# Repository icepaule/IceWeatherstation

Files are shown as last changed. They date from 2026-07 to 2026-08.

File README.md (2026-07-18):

# IceWeatherstation

DIY-Wetterstation auf Basis **ESP32 + Tasmota**: Temperatur, Luftfeuchte, Luftdruck, eine wasserdichte Zusatz-Temperatursonde, Wind (Geschwindigkeit + Richtung), Regenmenge, **Blitzerkennung** (AS3935/Franklin-Sensor) und ein **kalibrierter dBA-Schallpegelmesser**.

## Warum dieses Projekt?

Basiert auf dem Konzept des [ampheo.com Blog-Artikels "How to build a smart weather station with sensors"](https://www.ampheo.com/blog/how-to-build-a-smart-weather-station-with-sensors), erweitert um:

- **Franklin-Blitzsensor** (AS3935) für Blitzerkennung inkl. grober Entfernungsschätzung
- **Kalibriertes dBA-Schallpegelmodul** (DFRobot Gravity SEN0232, 30–130 dBA, A-bewertet) statt eines unkalibrierten Mikrofons, mit wetterfestem Mikrofongehäuse nach dem bewährten [DNMS-Design](https://sensor.community/en/sensors/dnms/) des sensor.community-Citizen-Science-Projekts
- **Zwingend externe WLAN-Antenne** — ESP32-WROOM-32U/32UE-Modulvariante statt der üblichen PCB-Antenne
- **100% Tasmota-Firmware** statt Arduino/PlatformIO, inklusive eigenständigem Web-UI, das komplett ohne Home Assistant/MQTT funktioniert (für Geräte ohne Smart-Home-Infrastruktur beim Empfänger)

Ursprünglich war angedacht, günstige Fertigsensorik (MISOL "Spare Part Outdoor Unit") zu verwenden — siehe [docs/misol-compatibility.md](docs/misol-compatibility.md), warum das **nicht** ohne Weiteres plug-and-play funktioniert und welche zwei Wege es trotzdem gäbe.

## Status

✅ **Erstes Gerät aufgebaut, geflasht und am Schuppen im Betrieb (Stand 2026-07-19).** DS18B20, Regenmesser, Anemometer, Windfahne, dBA-Sensor, AS3935 (Blitz) und OLED-Display sind verkabelt, kalibriert und live verifiziert; MQTT + Home-Assistant-Anbindung läuft. Noch offen: BME280 (Temperatur/Feuchte/Druck) ist bestellt, aber noch nicht geliefert/verbaut. Zweites Gerät (fürs Geschenk) folgt nach demselben Bauplan.

Fotos vom fertigen Aufbau:

<p float="left">
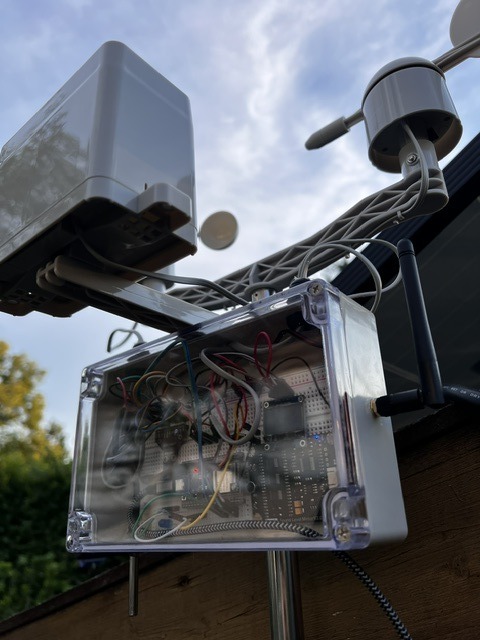
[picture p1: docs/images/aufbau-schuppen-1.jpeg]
Offenes Gehäuse mit Verkabelung, Windfahne/Anemometer im Hintergrund
  
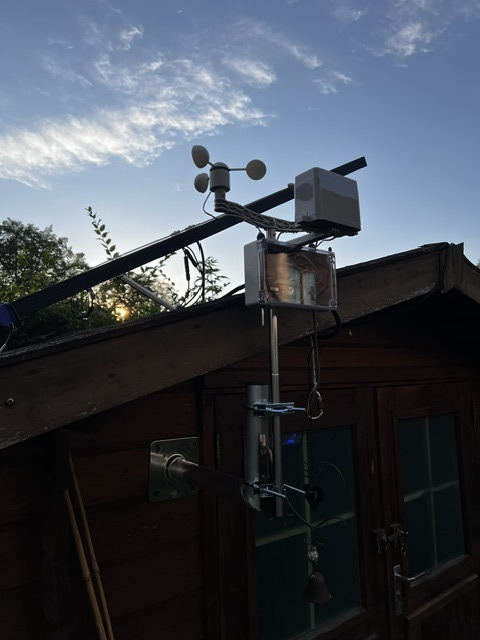
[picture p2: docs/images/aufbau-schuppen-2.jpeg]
Montage am Schuppendach, Anemometer/Windfahne auf dem Mast
  
</p>

Es sind **zwei Geräte** geplant (baugleich): eines für den Eigenbedarf, eines als Geschenk. Das zweite Gerät ist bewusst so ausgelegt, dass es **ohne** Home Assistant/MQTT beim Empfänger funktioniert — die Sensorwerte sind direkt über Tasmotas eingebautes Web-UI abrufbar.

## Struktur

| Datei | Inhalt |
|---|---|
| [docs/setup-guide.md](docs/setup-guide.md) | **Schritt-für-Schritt-Anleitung**: Aufbau, Flashen, Konfiguration, Home-Assistant-Einbindung, WebGUI |
| [docs/bom.md](docs/bom.md) | Vollständige Teileliste mit Bezugsquellen |
| [docs/wiring.md](docs/wiring.md) | Pinbelegung + Verkabelungskonzept (Diagramm) |
| [docs/enclosure.md](docs/enclosure.md) | Gehäuse, Mast-Montage, wetterfestes Mikrofongehäuse (DNMS-Design) |
| [docs/misol-compatibility.md](docs/misol-compatibility.md) | MISOL-Kompatibilitätsanalyse (warum kein Plug-and-Play) |
| [docs/tasmota-config.md](docs/tasmota-config.md) | Firmware-Konfiguration: Template, Counter, ADC, Rules |
| [firmware/README.md](firmware/README.md) | Firmware-Bezug: eigener Custom-Build nötig (AS3935 + OLED-Display sind in keinem offiziellen ESP32-Release kombiniert), inkl. `custom-build/`-Patches + Flash-/OTA-Anleitung |
| [firmware/config/backlog.txt](firmware/config/backlog.txt) | Fertiger Tasmota-Konsolen-Befehlssatz (Counter, ADC, AS3935) |
| [firmware/berry/autoexec.be](firmware/berry/autoexec.be) | Berry-Skript-Entwurf: Windrichtung-Lookup + Web-UI-Erweiterung |

## Hardware-Kurzüberblick

| Sensor | Bauteil | Werte |
|---|---|---|
| Temp/Feuchte/Druck | Bosch BME280 (I2C) | °C, %rH, hPa |
| Zusatz-Temperatur | DS18B20 (wasserdicht, 1-Wire) | °C |
| Wind | SparkFun Weather Meter Kit SEN-15901 | km/h, Richtung (8-stufig) |
| Regen | SparkFun Weather Meter Kit SEN-15901 | mm (Kippwaage) |
| Blitz | AS3935 / CJMCU-3935 (I2C) | Ereignis, Distanz (km), Energie |
| Schallpegel | DFRobot Gravity SEN0232 (analog) | dBA, 30–130 dB, A-bewertet |

Details siehe [docs/bom.md](docs/bom.md) und [docs/wiring.md](docs/wiring.md).

## Quellen / Credits

- [ampheo.com Blog](https://www.ampheo.com/blog/how-to-build-a-smart-weather-station-with-sensors) — Grundkonzept
- [SparkFun Weather Meter Kit SEN-15901 Hookup Guide](https://learn.sparkfun.com/tutorials/weather-meter-hookup-guide) — Wind/Regen-Sensorik
- [DFRobot Gravity SEN0232 Wiki](https://wiki.dfrobot.com/Gravity_Analog_Sound_Level_Meter_SKU_SEN0232) — dBA-Kalibrierung
- [sensor.community DNMS-Projekt](https://sensor.community/en/sensors/dnms/) — Wetterschutzgehäuse-Design fürs Mikrofon
- [rtl_433 Projekt](https://github.com/merbanan/rtl_433) — `fineoffset.c`-Decoder, Grundlage der MISOL-Kompatibilitätsanalyse
- [Tasmota-Dokumentation](https://tasmota.github.io/docs/) — Firmware-Referenz

## Lizenz

MIT, siehe [LICENSE](LICENSE). Keine Gewähr — insbesondere die Firmware-Beispiele sind unkalibrierte Entwürfe, siehe Status oben.

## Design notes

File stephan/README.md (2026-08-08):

# IceWeatherstation — Stephans Version

Reduzierte Variante des [IceWeatherstation](../README.md)-Projekts: gleiche ESP32/Tasmota-Basis, aber
weniger Sensoren. Gebaut für den Nachbau bei Stephan, dokumentiert hier als eigenständige, gekürzte
Abzweigung der Hauptdokumentation.

## Unterschied zum Originalgerät

| | Originalgerät | Stephans Version |
|---|---|---|
| Temperatur/Feuchte/Druck | BME280 | BME280 |
| Zusatztemperatur | DS18B20 | DS18B20 |
| Wind/Regen | SEN-15901 (3-teilig) | SEN-15901 (3-teilig) |
| Display | OLED | OLED |
| Blitzsensor (AS3935) | ✅ | ❌ nicht verbaut |
| Schallpegel (SEN0232) | ✅ | ❌ nicht verbaut |
| Luftqualität (MQ135) | ❌ nicht verbaut | ✅ intern, geschlossenes Gehäuse |
| MQTT / Home Assistant | ✅ | ❌ bewusst nicht — reines Web-UI |
| Status-LED | blinkt bei MQTT-Aktivität | blinkt bei Web-UI-Zugriff (siehe [tasmota-config.md](docs/tasmota-config.md)) |

## Inhalt

- [docs/bauanleitung.pdf](docs/bauanleitung.pdf) — vollständige Schritt-für-Schritt-Anleitung inkl. Verkabelung, zum Ausdrucken/Mitnehmen
- [docs/wiring.md](docs/wiring.md) — Pin-Tabelle (Board-Beschriftung), Widerstandswerte, Schaltbilder
- [docs/tasmota-config.md](docs/tasmota-config.md) — GPIO-Konfiguration, MQ135-Eigenkalibrierung, gefundene Fallstricke
- [firmware/autoexec.be](firmware/autoexec.be) — Dashboard-Skript (muss auf dem Gerät exakt `autoexec.be` heißen)

Die verwendete Sonder-Firmware selbst (Tasmota mit AS3935+OLED-Unterstützung) ist identisch zum
Originalgerät — siehe [../firmware/README.md](../firmware/README.md) für Bezug/Eigenbau. Der
Blitzsensor-Treiber ist darin enthalten, aber ungenutzt (kein AS3935 verbaut) — harmlos.

## Kein MQTT/Home Assistant

Bewusste Entscheidung: Stephans Standort hat keine Home-Assistant-Instanz. Alle Werte sind live über die
Tasmota-eigene Weboberfläche abrufbar (kein Cloud-Konto, keine App nötig).

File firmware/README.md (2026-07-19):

# Firmware

## Custom-Build nötig (AS3935 + Display zusammen)

⚠️ **Korrektur (2026-07-18, live an echter Hardware verifiziert):** Frühere Version dieser Doku ging davon aus, dass die offiziellen Tasmota32-Binaries für dieses Projekt ausreichen. Das stimmt nur, solange kein OLED-Display verbaut wird. Sobald AS3935 **und** Display gleichzeitig gebraucht werden, reicht **kein** offizielles ESP32-Release-Binary:

| Sensor/Feature | `tasmota32.bin` | `tasmota32-display.bin` |
|---|---|---|
| BME280 (I2C) | ✅ | ✅ |
| DS18B20 (1-Wire) | ✅ | ✅ |
| Counter (Regen/Wind) | ✅ | ✅ |
| ADC Range (dBA-Sensor) | ✅ | ✅ |
| Berry-Scripting | ✅ | ✅ |
| **AS3935 (Blitzsensor)** | ✅ | ❌ **fehlt** (I2CDriver 48 nicht kompiliert, alle `AS3935*`-Befehle "Unknown") |
| **OLED-Display (uDisplay/SSD1306)** | ❌ **fehlt** (`DisplayModel`/`DisplayText` "Unknown") | ✅ |

Grund (Tasmota-Quellcode `tasmota_configurations_ESP32.h`): `USE_AS3935` wird nur vom `FIRMWARE_TASMOTA32`-Flag gesetzt, `USE_DISPLAY`+`USE_UNIVERSAL_DISPLAY` nur vom separaten `FIRMWARE_DISPLAYS`-Flag — beide Flags schließen sich in den offiziellen Release-Envs gegenseitig aus. Für ESP32 gibt es (anders als bei ESP8266 mit `tasmota-sensors.bin`) keine dritte Variante, die beides kombiniert.

## Eigener Build: beide Features kombinieren

Lösung: eigener PlatformIO-Build mit [`custom-build/user_config_override.h`](custom-build/user_config_override.h) (in diesem Repo), der beide Defines zusätzlich zum normalen `tasmota32`-Featureset (inkl. AS3935) aktiviert:

```c
#define USE_DISPLAY
#define USE_UNIVERSAL_DISPLAY
```

Kein eigenes PlatformIO-Environment nötig — der Standard-`tasmota32`-Env bringt die nötige `lib_display`-Bibliothek bereits über `lib_extra_dirs` mit, es fehlten nur die beiden Compile-Defines.

### Optional: sprechende Web-UI-Labels statt "Counter 1"/"Analog1"/"ADC1 Range"

Tasmota bietet **keine** eingebaute Möglichkeit, diese Sensor-Labels umzubenennen (offiziell bestätigte Einschränkung, siehe [GitHub-Issue #6970](https://github.com/arendst/Tasmota/issues/6970) — kein Speicherplatz für frei wählbare Strings vorgesehen). Für dieses Projekt daher als zusätzlicher Source-Patch gelöst: [`custom-build/friendly-labels.patch`](custom-build/friendly-labels.patch) ändert die hartkodierten Label-Strings in `xsns_01_counter.ino` (Regenmesser/Anemometer statt Counter 1/2) und `xsns_02_analog.ino` (Windfahne (roh)/Schallpegel (mit dBA-Einheit) statt Analog1/ADC1 Range). Live getestet 2026-07-18, funktioniert einwandfrei.

⚠️ Größerer Wartungsaufwand als der reine Header-Override: der Patch bezieht sich auf feste Zeilennummern/Codeabschnitte und muss bei jedem Tasmota-Versionswechsel manuell neu geprüft/angepasst werden (`patch` schlägt bei Quellcode-Änderungen ggf. fehl, dann Handarbeit nötig). Optional — wer damit leben kann, dass die Tasmota-Web-UI technische Labels zeigt (Tasmotas eigene Haltung: Web-UI ist Konfig-/Debug-Tool, kein Endnutzer-Dashboard), kann diesen Schritt überspringen; das OLED-Display und eine spätere Home-Assistant-Anbindung zeigen ohnehin die sprechenden Bezeichnungen.

```bash
patch -p1 < ../custom-build/friendly-labels.patch   # im Tasmota-Repo-Root ausführen, nach dem Clone
```

### Build-Schritte

```bash
git clone --depth 1 --branch v15.5.0 https://github.com/arendst/Tasmota.git
cp user_config_override.h Tasmota/tasmota/user_config_override.h   # aus diesem Ordner
cd Tasmota
patch -p1 < ../friendly-labels.patch                                # optional, siehe oben
pio run -e tasmota32
# Ergebnis: .pio/build/tasmota32/firmware.bin (App-Image, ~2,2 MB, für OTA/erneutes Serial-Flashen)
#           .pio/build/tasmota32/firmware.factory.bin, falls vorhanden (Ersteinrichtung über USB)
```

Kompilierzeit ca. 2–5 Minuten (abhängig vom Compiler-Cache). Speicherbedarf verifiziert: Flash ~75 % belegt (2.204.503 / 2.949.120 Byte), RAM 24 % — ausreichend Reserve für spätere Erweiterungen (z.B. BME280 braucht keinen zusätzlichen Treiber-Code, ist bereits Teil des Basis-Featuresets).

⚠️ Vor jedem Build-Versuch prüfen, ob sich `tasmota_configurations_ESP32.h` in einer neueren Tasmota-Version geändert hat (Github-Suche nach `USE_AS3935` und `FIRMWARE_TASMOTA32`/`FIRMWARE_DISPLAYS`) — die Trennung könnte sich mit künftigen Releases ändern oder eine offizielle Kombi-Variante entstehen.

### Fertig kompilierte Binaries (Convenience, Stand 2026-07-18)

Für alle, die nicht selbst bauen wollen, liegen die live getesteten Ergebnis-Binaries direkt in [`custom-build/`](custom-build/):

| Datei | Zweck |
|---|---|
| [`custom-build/iceweatherstation-tasmota32.factory.bin`](custom-build/iceweatherstation-tasmota32.factory.bin) | Ersteinrichtung über USB (`esptool` mit `-z 0x0`) |
| [`custom-build/iceweatherstation-tasmota32.bin`](custom-build/iceweatherstation-tasmota32.bin) | OTA-Update / erneutes Serial-Flashen (App-Partition) |

Enthält AS3935 + uDisplay + die sprechenden Web-UI-Labels (Friendly-Labels-Patch bereits eingebaut). Für eine neuere Tasmota-Version selbst neu bauen (s.o.) statt diese Binaries blind zu verwenden.

## Bezug (falls doch nur ein Feature gebraucht wird)

Offizielle Release-Binaries: **https://ota.tasmota.com/tasmota32/release/**

| Datei | Zweck |
|---|---|
| `tasmota32.factory.bin` | Erstes Flashen über USB, falls **kein** Display gebraucht wird |
| `tasmota32.bin` | OTA-Update ohne Display-Bedarf |
| `tasmota32-display.bin` | Falls **kein** AS3935 gebraucht wird |

## Erstes Flashen (USB, esptool)

```bash
esptool.py --chip esp32 --port /dev/ttyUSB0 --baud 460800 write_flash -z 0x0 tasmota32.factory.bin
```

Für den eigenen Custom-Build: gleicher Befehl, aber mit dem selbst gebauten `firmware.factory.bin` (bzw. beim späteren Wechsel von einem offiziellen Release auf den Custom-Build reicht ein OTA-Update mit dem App-Image `firmware.bin` an der App-Partition — Sensor-/GPIO-Konfiguration bleibt dabei erhalten, da sie in einer separaten Flash-Partition liegt).

Alternativ [Tasmotizer](https://github.com/tasmota/tasmotizer) (GUI) verwenden — nimmt die gleiche `.factory.bin`-Datei.

### OTA-Update im eigenen Netz (kein öffentliches Hosting nötig)

Der ESP32 lädt die Firmware über `OtaUrl` + `Upgrade 1` von jeder erreichbaren HTTP-Quelle, nicht zwingend `ota.tasmota.com`. Praktikabel: `firmware.bin` per `python3 -m http.server` von einem Host im selben (V)LAN bereitstellen und die eigene IP als `OtaUrl` setzen — funktioniert ohne Umweg über externe Server, solange Absender-Host und ESP32 im selben Netzsegment liegen (Firewall-Regeln zwischen VLANs beachten).

## Nach dem Flashen

1. Mit dem ESP32-eigenen Access Point `tasmota-XXXX` verbinden, WLAN-Zugangsdaten eintragen (siehe [docs/setup-guide.md](../docs/setup-guide.md))
2. GPIOs über *Konfiguration → Konfiguriere Modul* setzen (siehe [docs/wiring.md](../docs/wiring.md))
3. [config/backlog.txt](config/backlog.txt) — Konsolen-Befehle für Counter/ADC/AS3935/WebSensor einfügen
4. [berry/autoexec.be](berry/autoexec.be) — über den Datei-Manager (*Konsole* → *Verwalte Dateisystem*) hochladen, Datei **muss exakt `autoexec.be` heißen**
5. OLED-Einrichtung (uDisplay, GPIO-Marker, Display-Descriptor): [docs/tasmota-config.md](../docs/tasmota-config.md) Abschnitt 6

Details und Reihenfolge: [docs/setup-guide.md](../docs/setup-guide.md), Befehlsreferenz: [docs/tasmota-config.md](../docs/tasmota-config.md).

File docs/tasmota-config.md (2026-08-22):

# Tasmota-Firmware-Konfiguration

> ⚠️ **Entwurfsstatus:** Diese Konfiguration ist noch nicht auf echter Hardware getestet (Teile wurden erst bestellt). Sie basiert auf offiziell dokumentierten Tasmota-Features und den Erfahrungen aus der bestehenden [Luft1-Station](https://tasmota.github.io/docs/) (baugleicher AS3935-Sensortyp, dort seit längerem stabil im Einsatz). Vor dem finalen Flashen der zweiten Station: Werte anhand der ersten, real aufgebauten Station verifizieren und diese Doku aktualisieren.

## Firmware-Basis

Kein fertiges Community-Template nötig — alle benötigten Bausteine sind in Standard-Tasmota (ESP32-Build) enthalten:

| Anforderung | Tasmota-Feature |
|---|---|
| BME280 (I2C) | Nativer Sensor-Treiber, autodetect |
| AS3935 (I2C) | Nativer Sensor-Treiber |
| DS18B20 (1-Wire) | Nativer Sensor-Treiber |
| Regen-/Windpulse | `Counter1` / `Counter2` |
| dBA-Sensor (analog, linear) | `AdcParam`-Bereichsumrechnung (Typ 6, "Range") |
| Windfahne (Potentiometer → 8 Richtungen) | Rules oder Berry-Skript (kein nativer Support) |
| Eigenes Web-UI | Berry `webserver`-Hooks |

## 1. Grundkonfiguration (Web-UI: *Konfiguration* → *Konfiguriere Modul*)

Empfohlen: Die GPIO-Zuordnung **über die Tasmota-Web-Oberfläche** vornehmen (Modul-Konfigurationsseite), nicht per handgeschriebenem `Template`-JSON — die Web-UI verhindert falsch nummerierte GPIO-Komponenten-IDs, die sich zwischen Tasmota-Versionen ändern können.

**Alternative: per Serial-Konsole (verifiziert für Tasmota 15.5.0(release-tasmota32)-3.3.8, 2026-06-22).** Statt der Web-UI kann jedes `GPIO<pin>`-Kommando direkt den numerischen Funktionswert setzen — praktisch fürs Erstflashen ohne WLAN. Die Werte wurden nicht geraten, sondern aus der `/md`-Seite dieses konkreten Builds ausgelesen (das Options-Array enthält die realen numerischen IDs):

```
GPIO21 640    // I2C SDA1 (BME280 + AS3935)
GPIO22 608    // I2C SCL1 (BME280 + AS3935)
GPIO25 4672   // AS3935 IRQ
GPIO4 1312    // DS18x20 (DS18B20-Sonde)
GPIO27 352    // Counter1 (Regenmesser)
GPIO14 353    // Counter2 (Anemometer)
GPIO34 4704   // ADC Input1 (Windfahne)
GPIO35 4864   // ADC Range1 (dBA-Sensor SEN0232)
```

⚠️ Diese Werte gelten nur für exakt diesen Firmware-Build — bei anderer Tasmota-Version vor Gebrauch per `GPIO<pin>` (ohne Wert) den aktuellen Zustand gegenprüfen bzw. neu aus `/md` auslesen. Der `/md`- und `/cn`-Pfad ist ab Tasmota ≥15 ohne WebPassword standardmäßig für Referer-lose Requests gesperrt (`HTP: Referer '' denied. Use 'SO128 1' for HTTP API`) — für den einmaligen Auslese-Zugriff testweise `SetOption128 1` setzen, danach wieder auf `0` zurücksetzen (Standard-Absicherung bleibt so erhalten).

Pinbelegung (siehe auch [wiring.md](wiring.md)):

| GPIO | Komponente |
|---|---|
| 21 | I2C SDA |
| 22 | I2C SCL |
| 25 | **AS3935** (eigene GPIO-Komponente, kein generischer Interrupt) |
| 4 | DS18B20 (1-Wire) |
| 27 | Counter1 (Regenmesser) |
| 14 | Counter2 (Anemometer) |
| 34 | ADC Input (Windfahne, Rohwert 0–4095) |
| 35 | ADC Input **Range** (dBA-Sensor SEN0232, siehe Abschnitt 3) |

> Tasmota verlangt für den AS3935 eine eigene GPIO-Rolle „AS3935" in der Modul-Konfiguration (nicht „Interrupt"). Zusätzlich müssen an der AS3935-Platine die Pins **CS und MISO auf GND**, **SI auf VCC** gelegt werden, falls die Platine diese SPI-Pins herausführt (bei I2C-Betrieb ungenutzt, aber nicht offen lassen) — [Quelle: Tasmota AS3935-Doku](https://tasmota.github.io/docs/AS3935/).

## 2. Regenmesser & Anemometer (Counter)

Tasmota zählt Pulse an `Counter1`/`Counter2` automatisch. Umrechnungsfaktoren (aus dem SparkFun-Hookup-Guide):

- **Regen:** 1 Kippe = 0,2794 mm
- **Wind:** 1 Klick/Sekunde = 1,492 mph ≈ 2,4 km/h

```
CounterType1 0        // Pulszähler, kein PWM
CounterDebounce 10     // ms, gegen Kontaktprellen am Reed-Kontakt
```

Die Umrechnung Pulse→mm bzw. Pulse/Zeit→km/h ist **nicht linear per `AdcParam` abbildbar** (zeitbasiert), deshalb im Berry-Skript berechnet — siehe [firmware/berry/autoexec.be](../firmware/berry/autoexec.be).

## 3. dBA-Sensor (SEN0232) via AdcParam (Range-Typ)

DFRobot-Formel laut Datenblatt: **dB = Vout(V) × 50** (0,6V → 30 dBA, 2,6V → 130 dBA) — exakt linear, ideal für Tasmotas native ADC-Bereichsumrechnung.

⚠️ **Zwei Fallen, live an Tasmota 15.5.0(release-tasmota32)-3.3.8 verifiziert und korrigiert (2026-07-18):**

1. **`AdcParam<N>` zählt nach GPIO-Reihenfolge, nicht nach Pin-Nummer.** Die Kanalnummer `N` entspricht der Position unter allen ADC-Rollen-Pins, aufsteigend nach GPIO-Nummer sortiert — **nicht** der GPIO-Nummer selbst. Bei diesem Projekt: GPIO34 (Windfahne, „ADC Input") ist Kanal **1**, GPIO35 (dBA, „ADC Range") ist Kanal **2** → der richtige Befehl ist `AdcParam2`, nicht `AdcParam1`! Zur Kontrolle: Der Echo-Antwort-Wert an erster Stelle im Array ist die tatsächliche GPIO-Nummer, z.B. `{"AdcParam2":[35,...]}` bestätigt Pin 35.
2. **Die Schwellwerte sind KEINE Millivolt, sondern ein 0–4095-Pseudo-ADC-Wert** (aus kalibrierter mV-Messung zurückgerechnet, siehe Tasmota-Quellcode `xsns_02_analog.ino`). 0,6V/2,6V müssen erst umgerechnet werden: `mV / 3300 × 4095`.

```
600mV  → 600/3300×4095  ≈ 745
2600mV → 2600/3300×4095 ≈ 3226

AdcParam2 6,745,3226,300,1300   // Kanal 2 = GPIO35; Pseudo-ADC 745–3226 (≈0,6–2,6V) -> Output 30,0-130,0 dBA (x0.1)
```

Ergebnis nach Korrektur: `Status 10` zeigt einen plausiblen Wert um `Range1: 500–600` (= 50–60 dBA, normaler Innenraum-Umgebungspegel), statt vorher fälschlich `35` (3,5 dBA, unmöglich niedrig — Anzeichen, dass etwas an der Umrechnung nicht stimmt).

Allgemein: mit `Status 10` immer gegenprüfen, welcher Analog-Kanal (`Range1`, `Range2`, …) tatsächlich den dBA-Wert zeigt, und mit `AdcParam<N>` (ohne Werte) den aktuell gespeicherten Zustand samt zugehöriger GPIO-Nummer abfragen, bevor man kalibriert.

## 4. Windfahne (Potentiometer → Richtung)

Keine native Tasmota-Umrechnung vorhanden. Zwei Optionen:

1. **Klassische Rules** mit ADC-Schwellwert-Vergleichen (`ON Analog#A1>x DO ... ENDON`) — einfacher, aber unübersichtlich bei 8 Richtungen mit Übergangsbereichen
2. **Berry-Skript mit Lookup-Tabelle** (empfohlen) — übersichtlicher, einfacher zu kalibrieren. Siehe [firmware/berry/autoexec.be](../firmware/berry/autoexec.be)

**Update 09.08.2026:** Die `VANE_TABLE` in `autoexec.be` ist kein Platzhalter mehr, sondern korrekt aus dem
offiziellen Fine-Offset-Datenblatt (`DS-15901-Weather_Meter.pdf`, Hersteller der SEN-15901-Sensorik,
Tabelle "Direction/Resistance") berechnet — über dieselbe Spannungsteiler-Formel wie unser eigener Aufbau
(`raw = 4095 * Rvane / (10000 + Rvane)`, fester 10-kΩ-Widerstand zwischen 3,3V und GPIO34, identische
Topologie wie im Datenblatt-Beispielschaltbild). Live am (baugleichen) Sensor der Stephan-Variante
verifiziert — Details und Ausrichtungsprozedur: [stephan/docs/tasmota-config.md](../stephan/docs/tasmota-config.md)
Abschnitt 5. Kalibrierung reduziert sich damit auf einen rein mechanischen Schritt: Sensor beim Mastaufbau
mit seiner eigenen "N"-Markierung nach echt Norden ausrichten, dann per Kompass-Gegenprobe verifizieren
(nur zuverlässig bei fest montierter, frei einrastender Fahne — von Hand gehalten liefert der Rohwert keine
eindeutigen Ergebnisse, siehe verlinkter Abschnitt).

⚠️ **Fallstrick, live gefunden (2026-07-18):** Der Rohwert (`A1` im Status-10-JSON, `GPIO_ADC_INPUT`-Typ) verschwindet komplett aus der JSON-Ausgabe, sobald `AdcParam<Kanal>` den **4. Parameter ungleich 0** stehen hat (das ist Tasmotas interner Umschalter für einen "Direct Mode", der eigentlich für Dimmer/Licht-Steuerung gedacht ist, nicht für uns relevant). Falls `A1` nicht in `Status 10` auftaucht, obwohl GPIO korrekt auf „ADC Input" steht: `AdcParam<Kanal>` (Kanalnummer nach GPIO-Reihenfolge zählen, siehe Abschnitt 3) mit 4. Wert explizit auf 0 zurücksetzen, z.B. `AdcParam1 6,0,0,0,0`.

## 5. AS3935 (Blitzsensor)

Verifizierte Befehle laut [Tasmota AS3935-Dokumentation](https://tasmota.github.io/docs/AS3935/):

```
AS3935setgain Outdoors   // Outdoor-Verstärkung statt Indoors
AS3935autonf 1           // automatische Störgeräusch-Kalibrierung
AS3935disturber 1        // Disturber-Erkennung aktiv
AS3935autodisturber 1    // automatische Disturber-Unterdrückung
AS3935settings           // aktuelle Konfiguration zur Kontrolle anzeigen
```

Erfahrungswert aus der Luft1-Station: `Outdoors`-Modus ist bei Freiluft-Montage entscheidend gegen Fehlalarme (`Indoors`-Modus hat deutlich höhere, für den Außeneinsatz zu empfindliche Verstärkung). I2C-Adresse ist bei diesem Sensor-Typ fix `0x03` (kein Konfigurationsschritt nötig). Bei anhaltenden Fehlalarmen zusätzlich `AS3935setnf` (Noise-Floor-Level 0–7) manuell nachjustieren.

⚠️ **Live gefunden bei echtem Gewitter (2026-07-19):** Erstkontakt mit realem Blitzgeschehen zeigte trotz korrekt eingerichteter GPIOs durchgehend `Event:0, Distance:0, Energy:0` — Ursache war `Tunecaps:0` in `AS3935settings` (Antennen-Abstimmkondensator nie kalibriert; `0` ist hier der rohe Minimalwert, keine neutrale "kein Tuning nötig"-Einstellung). Ohne Tuning auf die geforderten 500 kHz Resonanzfrequenz sinkt die Empfindlichkeit drastisch. Fix:
```
AS3935calibrate      // "calibration failed":0 = Erfolg (0 Fehler)
AS3935disturber 1    // Disturber-Unterdrueckung wieder aktivieren
```
Alternative laut [Tasmota-Doku](https://tasmota.github.io/docs/AS3935/): Manche Module haben den korrekten, werksseitig ermittelten Tuning-Wert als Aufkleber auf der Platine — dann direkt `AS3935settunecaps <Wert>` statt Auto-Kalibrierung. Nach jedem `AS3935calibrate`/`AS3935settunecaps` immer `AS3935settings` gegenprüfen (Disturber-Status!) und danach live abwarten, ob reale Blitze jetzt registriert werden.

⚠️ **Wiederholt live gefunden (2026-08-20), diesmal Ursache geklärt:** Während eines echten Gewitters erneut `Distance:0, Energy:0` trotz Donner — Gain stand wieder auf `Indoors` statt `Outdoors`. Grund: Gain/Disturber/Tune-Caps sind Chip-interne AS3935-Register, kein von Tasmota persistiertes `Setting` — sie hängen am selben 3,3V-Rail wie ESP32/BME280/OLED und werden bei **jedem** ESP32-Neustart (z.B. für ein Firmware-Update) mit zurückgesetzt. Ein einmalig per Konsole gesetztes Setup hält also nur bis zum nächsten Reboot. **Fix:** `autoexec.be` ruft die komplette AS3935-Konfiguration (`setup_as3935()`) jetzt bei jedem Boot automatisch erneut auf — analog zum Nachtruhe-Self-Heal. Manuelles Nachsetzen nach einem Neustart ist damit nicht mehr nötig.

**Korrektur (2026-08-20), per Tasmota-Quellcode verifiziert** (`xsns_67_as3935.ino`, Funktion `AS3935AutoTuneCaps`): Die obige Annahme von 2026-07-19, `AS3935calibrate` schalte den Disturber-Filter intern ab, ist **falsch** — die Kalibrierroutine fasst das Disturber-Register nachweislich nicht an, sie stellt ausschliesslich `TUNE_CAPS` über `LCO_FDIV`/`DISP_LCO` ein. Der damals (und auch heute wieder) beobachtete `Disturber: Off`-Zustand kommt stattdessen von `AS3935autodisturber 1` selbst: Der Treiber schaltet die Disturber-Unterdrückung nach `DisturberAutoTime` (Default 1 Minute) automatisch kurz aus und wartet auf ein echtes Störsignal, um sie wieder zu aktivieren (`AS3935EverySecond()`, IRQ-Fall 4) — eine gewollte Selbstabgleich-Schleife gegen die Umgebungs-EMI, **kein Fehler**. Wichtig: Dieser Zyklus betrifft ausschliesslich die Störsignal-Filterung. Echte Blitze (IRQ-Fall 8, "storm") laufen über einen komplett getrennten Codepfad und werden unabhängig vom Disturber-Status immer erkannt. `AS3935disturber 1` nach der Kalibrierung bleibt trotzdem sinnvoll (Ausgangszustand explizit setzen), ist aber keine zeitkritische Reihenfolge-Abhängigkeit zu `AS3935calibrate`.

⚠️ **Dashboard-Bug gefunden und behoben (2026-08-22), während eines echten Gewitters live geprüft:** Das MQTT-`Event`-Feld im `AS3935`-JSON ist **nicht** der rohe IRQ-Registerwert (1/4/8 laut Datenblatt), sondern wird vom Treiber bereits übersetzt (`AS3935TranslIrq()` in `xsns_67_as3935.ino`, per Quellcode verifiziert):

| Event | Bedeutung |
|---|---|
| `0` | Ruhezustand (kein Interrupt seit letztem Teleperiod-Report) |
| `1` | **Blitz mit Entfernung erkannt** |
| `2` | **Blitz, aber ausserhalb des Entfernungsbereichs** |
| `3` | **Blitz, Entfernung nicht bestimmbar** |
| `4` | **Gewitter direkt über dem Sensor** |
| `5` | Rauschpegel zu hoch |
| `6` | Störsignal (Disturber) erkannt |
| `7` | Interrupt ohne erkennbare Ursache |

Das Kiosk-Dashboard (`dashboards/kiosk_tablet.yaml`, Karte "AS3935") prüfte bisher fälschlich auf `e == '8'` für "Blitz!" (kommt nie vor) und auf `e == '1'` für "Rauschen" — genau der Code für einen **echten, per Entfernung lokalisierten Blitzschlag**. Ein realer Strike wäre also nie als "Blitz!" angezeigt worden, sondern fälschlich als "Rauschen". Fix: Template korrigiert auf `e in ['1','2','3','4']` → "Blitz!" (gelb), `e == '6'` → "Störer" (orange), `e == '5'` → "Rauschen". Betraf nur die Dashboard-Anzeige — Erkennung/MQTT/Logging auf Tasmota-Seite waren davon nicht betroffen.

## 6. OLED-Display (Hailege 0,96" SSD1306, 128×64, I2C, 4-Pin)

Kein eigener Sensor-GPIO nötig — das Display hängt als dritter Teilnehmer am selben I2C-Bus wie BME280 und AS3935 (siehe [wiring.md](wiring.md)). Braucht aber einen zusätzlichen **virtuellen Marker-Pin** (s.u.).

⚠️ **Wichtige Änderung ggü. älteren Tasmota-Anleitungen (live an Tasmota 15.5.0 verifiziert, 2026-07-18):**

1. **Der klassische `DisplayModel 2`/SSD1306-Treiber ist im Standard-`tasmota32.bin` gar nicht enthalten** — Display-Support ist ein eigenes Firmware-Feature-Build (`tasmota32-display.bin`). Umstieg per OTA, **ohne** die Sensor-Konfiguration zu verlieren (Settings bleiben auf dem separaten Flash-Dateisystem erhalten):
   ```
   OtaUrl http://ota.tasmota.com/tasmota32/release/tasmota32-display.bin
   Upgrade 1
   ```
   Läuft über den ESP32-eigenen SafeBoot-Zwischenschritt (kurzzeitig `Version 15.5.0(release-safeboot)` im Log, normal), danach automatischer Neustart in `(release-display)`. Laut Tasmota-Quellcode entfernt dieser Build nur Emulation/Domoticz/Home-Assistant/Energy-Monitoring — AS3935 und Berry bleiben erhalten.
2. **Der alte SSD1306-Treiber selbst wurde in aktuellem Tasmota komplett entfernt** und durch das neue, generische **uDisplay**-System ersetzt (`DisplayModel` ist jetzt immer **17**, unabhängig vom Displaytyp). Ein `DisplayModel 2`-Versuch wird stillschweigend auf `0` zurückgesetzt (Command scheint erfolgreich, wirkt aber nicht — keine Fehlermeldung!).

### Einrichtung (uDisplay)

1. Einen **ungenutzten** GPIO auf die Rolle **„Option A3"** setzen — rein virtueller Marker ohne physische Funktion, signalisiert Tasmota nur "uDisplay starten". In diesem Projekt: GPIO32 (frei, siehe [wiring.md](wiring.md)).
   ```
   GPIO32 6210   // "Option A3" — Basiswert "Option A1"=6208 + Instanz-Offset 2, gleiches Zählschema wie Counter1/2
   ```
2. Den SSD1306-Display-Descriptor hinterlegen — offizielle Datei [`SSD1306_128x64_display.ini`](https://github.com/arendst/Tasmota/blob/development/tasmota/displaydesc/SSD1306_128x64_display.ini) aus dem Tasmota-Repo, als **einzeiliger** String in `Rule3` gespeichert (Rule3 bewusst **nicht aktivieren** — dient hier nur als Datenspeicher für den Descriptor, nicht als ausführende Regel):
   ```
   Rule3 :H,SSD1306,128,64,1,I2C,3c,*,*,* :S,0,2,1,0,30,20 :I AE D5,80 A8,3F D3,00 40 8D,14 20,00 A1 C8 DA,12 81,9F D9,F1 DB,40 A4 A6 AF :o,AE :O,AF :A,00,10,40,00,00 :i,A6,A7
   ```
   ⚠️ Adresse `3c` im Descriptor selbst prüfen/anpassen, falls das eigene Board auf `0x3D` läuft (per `I2CScan` verifizieren, wie beim AS3935-Adressabgleich).
3. Display-Modell aktivieren und Neustart (nötig, damit der Treiber greift):
   ```
   DisplayModel 17
   Restart 1
   ```
4. Nach dem Neustart sollte das Boot-Log `DSP: SSD1306 initialized` zeigen. Test:
   ```
   DisplayText [x0y0f1]Wetterstation
   ```

### Live-Daten automatisch anzeigen

**Erster Ansatz (überholt):** Eine einfache Tasmota-Rule (`ON Tele-DS18B20#Temperature DO DisplayText ... ENDON`) reicht für einzelne Werte, aber nicht für rollierende 24h-Fenster (Regenmenge, Luftdruck-Trend) — Rules haben keinen eigenen Zustand/Speicher über die Zeit. Das finale Dashboard läuft daher komplett über [firmware/berry/autoexec.be](../firmware/berry/autoexec.be) (Berry-Skript), **Rule1 ist deaktiviert** (`Rule1 0`).

Das Skript aktualisiert alle 10 Sekunden per `tasmota.add_cron("*/10 * * * * *", ...)` vier Zeilen (Zeile 4 + Feuchte in Zeile 3 kamen erst später dazu, siehe Abschnitt 13):

```
Zeile 1: <RSSI>dBm <IP>              (oder "No-WiFi" falls WLAN nicht verbunden)
Zeile 2: <Wind m/s>M <Richtung>° <Regen 24h>L
Zeile 3: <Temperatur>C <Luftdruck ganzzahlig> <Trend U/D/-> <Feuchte>%
Zeile 4: <Regen laufende Stunde>L <Schallpegel>dBA <Blitz-Distanz>KM
```

⚠️ **ESP32 kann keine eigene Versorgungsspannung messen** (anders als ESP8266 mit `ESP.getVcc()` — keine interne Referenz zum Vergleich vorhanden, siehe [ESP32-Forum-Diskussion](https://esp32.com/viewtopic.php?t=3221)). Zeile 1 zeigt deshalb WLAN-Signalstärke statt einer erfundenen Spannungsangabe. Falls später ein Spannungsteiler an einem freien ADC-Pin (GPIO33/36/39) verbaut wird, lässt sich echte Spannungsmessung nachrüsten.

⚠️ **Font des Displays kann keine Sonderzeichen** (live getestet 2026-07-18: `°`-Zeichen erscheint als Kästchen). Das Skript hat deshalb zwei Schalter am Dateianfang:
```berry
var SHOW_DEGREE_SYMBOL = false  # testweise auf true stellen und visuell prüfen
var SHOW_TREND_ARROWS = false   # dito — Pfeile ↑/↓ vs. Buchstaben U/D
```
Nach Änderung: Datei erneut über *Konsole → Verwalte Dateisystem* hochladen (exakt `autoexec.be`) + `Restart 1`.

⚠️ Für den dBA-Sensor (`ANALOG#Range1`) empfiehlt sich `AdcParam` **ohne** die künstliche ×10-Skalierung (`AdcParam2 6,745,3226,30,130` statt `...,300,1300`) — sonst zeigt das Display "596" statt "60" an. Details zur Umrechnung: Abschnitt 3 oben.

⚠️ **Berry kennt keine Listen-Multiplikation** (`[0.0] * 24` schlägt fehl mit `attribute_error`) — Ringpuffer stattdessen per Schleife befüllen (siehe `zero_list()` im Skript).

Regenmenge/Luftdruck-Trend nutzen ein rollierendes 24-Stunden-Ringpuffer-Fenster (`tasmota.rtc()`/`tasmota.time_dump()` für die aktuelle Kalenderstunde) statt eines Mitternacht-Resets — überlebt aber **keinen Neustart** (Historie liegt im RAM, nicht in `persist`, um Flash-Verschleiß durch stündliche Schreibzugriffe zu vermeiden). Nach einem Neustart füllt sich das 24h-Fenster graduell wieder auf.

## Konfigurationsablauf

```mermaid
flowchart TD
    A[Tasmota flashen] --> B[WLAN + Grundkonfiguration]
    B --> C[Modul-GPIOs zuweisen]
    C --> D[I2C-Scan: BME280 + AS3935 erkannt?]
    D -->|nein| D1[Verkabelung/Adressen prüfen]
    D1 --> D
    D -->|ja| E[DS18B20 erkannt?]
    E -->|nein| E1[Pull-up/Verkabelung prüfen]
    E1 --> E
    E -->|ja| F[Counter1/2 Testpulse manuell auslösen]
    F --> G[AdcParam dBA-Sensor kalibrieren]
    G --> H[Berry-Skript für Windfahne laden]
    H --> I[AS3935 auf Outdoor + Testauslösung]
    I --> J[WebSensor-Anzeige aufräumen]
    J --> K[Konfiguration exportieren/sichern]
```

## 7. Status-LED (WLAN/MQTT-Link, optional)

Externe LED (z.B. aus einem Elegoo-Sensor-Kit) + Vorwiderstand (330Ω) an einem freien GPIO, hier **GPIO2**:

```
GPIO2 544      // "LedLink" (Basiswert "LedLink1", gleiches Zählschema wie Counter1/2)
LedState 7     // s.u. — GPIO-Rolle allein reicht NICHT aus
```

Verkabelung: GPIO → Vorwiderstand → LED-Anode (langes Beinchen), LED-Kathode (kurzes Beinchen) → GND. Bei Common-Kathode-RGB-Modulen (z.B. Elegoo SMD-RGB/RGB-LED, 4 Pins: R/G/B/GND) reicht ein einzelner Farbkanal für diesen Zweck — die anderen beiden Pins bleiben unbeschaltet.

⚠️ **Fallstrick, live gefunden (2026-07-18):** Die GPIO-Rollenzuweisung („LedLink") allein reicht nicht — ohne zusätzliches `LedState` bleibt die LED aus. `LedState` ist eine Bitmaske 0–7 (`enum LedStateOptions` im Tasmota-Quellcode: 1=Power, 2/4=MQTT-Sub/Pub-Aktivität, kombinierbar), **kein** einfacher "AN sobald WLAN+MQTT verbunden"-Schalter — eine erste Recherche deutete fälschlich auf einen (nicht existierenden) Wert 8 hin, der von `CmndLedState` aber hart auf `< MAX_LED_OPTION` (=8, also nur 0–7 gültig) begrenzt wird.

Live-Verhalten bei `LedState 7`: LED **blinkt rhythmisch bei jeder MQTT-Aktivität** (Senden/Empfangen), kein dauerhaftes Leuchten im verbundenen Zustand — zeigt damit laufende Netzwerkaktivität statt eines reinen Verbunden/Getrennt-Zustands. Für dieses Projekt genau so gewünscht (bestätigt 2026-07-18).

## 8. Zeitzone (Europe/Berlin, Sommerzeit)

⚠️ **Fallstrick, live gefunden (2026-07-18):** `TimeStd`/`TimeDst` waren bereits korrekt mit den EU-DST-Standardregeln vorbelegt (letzter Sonntag März/Oktober), trotzdem zeigte die Lokalzeit nur UTC+1 statt der im Sommer korrekten UTC+2 (CEST) — betraf nicht nur die Anzeige, sondern auch **jede zeitbasierte Logik im Berry-Skript** (24h-Ringpuffer für Regen/Luftdruck-Trend, Nachtruhe-Fenster). Ursache: `Timezone` stand nicht auf `99` (= "nutze TimeStd/TimeDst-Regeln"), sondern auf einem festen Offset ohne Sommerzeit-Umstellung. Fix:

```
Timezone 99
```

Danach `Status 7` prüfen — `"Timezone":99` und die Lokalzeit muss der tatsächlichen Sommer-/Winterzeit entsprechen (Sunrise/Sunset-Werte in der gleichen Antwort sind ein guter Plausibilitäts-Check).

## 9. Nachtruhe (Display + Status-LED 22:00–08:00 aus)

Realisiert in [firmware/berry/autoexec.be](../firmware/berry/autoexec.be) über `QUIET_START_HOUR`/`QUIET_END_HOUR` (Standard 22/8) — schaltet `DisplayDimmer` und `LedState` stündlich neu (`tasmota.add_cron("0 0 * * * *", ...)`), damit ein Neustart mitten in der Nachtruhe sich selbst korrigiert.

⚠️ **Fallstrick, live gefunden (2026-07-18):** Ein direkter Check beim Booten (in `init()`) griff auf `tasmota.rtc()['local']` zu, **bevor** NTP synchronisiert war (Epoch nahe 0 = 1970) — das lieferte Stunde 0 und löste fälschlich sofort Nachtruhe aus (Display/LED gingen nach jedem Neustart kurz aus, unabhängig von der echten Uhrzeit). Fix: `tasmota.set_timer(15000, ...)` für den ersten Check, zusätzlich Plausibilitätsprüfung (`epoch < 1000000000` → NTP noch nicht bereit → erneut in 15s versuchen).

## 10. MQTT + Home Assistant

MQTT-Zugangsdaten sind projektintern, **nicht** in diesem öffentlichen Repo dokumentiert (siehe Betriebs-Notizen). Wichtig für die HA-Anbindung:

- `SetOption19 1` aktiviert Tasmotas **eigenes** Discovery-Format unter `tasmota/discovery/<MAC>/config` — das ist **nicht** das generische `homeassistant/<component>/.../config`-Schema, das die Standard-„MQTT"-Integration in Home Assistant erwartet. Für automatische Entity-Erstellung braucht es die **dedizierte "Tasmota"-Integration** in HA (separat von der generischen MQTT-Integration, aber auf derselben MQTT-Verbindung aufbauend).
- Home Assistant erstellt Entities aus jedem Feld der periodischen `tele/.../SENSOR`-JSON automatisch (z.B. `sensor.tasmota_ds18b20_temperature`, `sensor.tasmota_counter_c1`, `sensor.tasmota_as3935_distance_2`). Eigene Berechnungswerte (Windgeschwindigkeit/-richtung, Regenmenge 24h) existieren nur im Berry-Skript-Speicher fürs OLED — damit sie ebenfalls per MQTT/HA sichtbar werden, müssen sie explizit in die SENSOR-JSON eingespeist werden.
- Dafür in der Berry-`Driver`-Klasse eine `json_append()`-Methode ergänzen (analog zu `web_sensor()`, aber für MQTT statt Web-UI):
  ```berry
  def json_append()
    tasmota.response_append(string.format(',"IceWeather":{"WindSpeed":%.2f,"WindDir":%d,"Rain24h":%.2f}',
      self.wind_ms, dir, self.rain_24h()))
  end
  ```
  Erzeugt automatisch `sensor.tasmota_iceweather_windspeed` usw. in HA, ohne HA-seitige Template-Sensoren duplizieren zu müssen.

Ergebnis im Home-Assistant-Dashboard `lovelace-wetter` (Tab „Aktuell"): eigener Kasten „🏠 IceWeatherstation (lokal, nicht online)" mit grünem Rahmen, klar von der Online-Wetterquelle (DWD/API oben im Dashboard) unterschieden.

⚠️ **Einheiten-Fallstricke, live gefunden (2026-07-19):**
- Eigene `IceWeather`-Felder (WindSpeed/WindDir/Rain24h) haben von Haus aus **keine** Einheit in HA (Tasmotas Discovery kennt nur bei bekannten Standard-Feldnamen automatisch die richtige Einheit, nicht bei selbst erfundenen JSON-Keys).
- `sensor.tasmota_as3935_distance_2` bekommt von der HA-Tasmota-Integration fälschlich die Einheit **cm** zugewiesen, obwohl der Wert tatsächlich in **km** vorliegt (Tasmotas eigenes Web-UI zeigt korrekt "km") — ein Integrations-seitiger Mapping-Fehler, nicht in Tasmota selbst behebbar.

Fix: `homeassistant: customize:`-Block in einem HA-Package (hier: `packages/iceweatherstation.yaml`, außerhalb dieses Repos in der HA-Konfiguration). Wichtig: **nicht** die neuere Per-Entity-"Anzeigeeinheit"-Option in den HA-Entity-Einstellungen verwenden — die würde bei einem `device_class: distance`-Sensor automatisch eine (hier falsche) Einheiten-Umrechnung anwenden und den ohnehin schon korrekten km-Wert nochmal verfälschen. Der klassische `customize`-Block überschreibt die Einheit nur als Label, ohne Umrechnung:
```yaml
homeassistant:
  customize:
    sensor.tasmota_as3935_distance_2:
      device_class: null   # verhindert HAs automatische Einheiten-Umrechnung
      unit_of_measurement: "km"
    sensor.tasmota_iceweather_windspeed:
      unit_of_measurement: "m/s"
    sensor.tasmota_iceweather_winddir:
      unit_of_measurement: "°"
    sensor.tasmota_iceweather_rain24h:
      unit_of_measurement: "mm"
```
Wirkt erst nach vollständigem HA-Core-Neustart oder *Entwicklertools → YAML → Alle YAML-Konfigurationen neu laden*.

## 11. Regen-24h-Ringpuffer: Persistenz über Neustarts hinweg

⚠️ **Größter funktionaler Bug, live gefunden (2026-07-19):** Der 24h-Regen-Ringpuffer (siehe Abschnitt 4 der Windfahne / [autoexec.be](../firmware/berry/autoexec.be)) lebte ursprünglich nur im RAM — **jeder Neustart löschte die komplette Regen-Historie**, nicht nur die aktuelle Stunde. Bei einem restart-anfälligen System (OTA-Updates, Watchdog-Resets, Konfigurationsänderungen — wie in diesem Projekt mehrfach erlebt) bedeutet das: Regen, der vor dem letzten Neustart fiel, fehlt in der 24h-Anzeige, obwohl er noch im 24h-Fenster liegt. Symptom: Uptime kürzer als 24h + plausibel zu niedrige Regenmenge ist ein starker Hinweis auf genau dieses Problem.

Fix: `import persist` (Tasmota-Berry-Standardmodul), Ringpuffer + Stundenmarker + Druck-Trend werden jetzt über Neustarts hinweg gespeichert. **Zwei weitere Fallstricke dabei gefunden:**

1. **`persist.foo = self.bar` mit einer Liste erzeugt KEINE gemeinsame Referenz.** Nachträgliche Änderungen an `self.bar` tauchen nicht automatisch in `persist.foo` auf — `persist.save()` schreibt dann weiterhin die alte Kopie. Fix: keine zusätzliche `self`-Kopie halten, ausschließlich direkt über `persist.rain_hourly[h] = ...` lesen/schreiben, damit es nur eine einzige Quelle der Wahrheit gibt. `persist.dirty()` zusätzlich nötig, da In-Place-Änderungen an Listen von `persist` nicht automatisch erkannt werden (nur echte Zuweisungen `persist.foo = ...` triggern das automatisch).
2. **NTP-Boot-Race betrifft nicht nur die Nachtruhe, sondern auch den Stunden-Rollover.** Direkt nach dem Booten läuft `tasmota.rtc()` kurzzeitig mit einer ungültigen Epoch (~0/1970, vor NTP-Sync) — das lieferte eine falsche "Stunde", die fälschlich einen Stundenwechsel auslöste und dabei den falschen Ringpuffer-Slot leerte (konkret beobachtet: die komplette bis dahin aufgelaufene Regenmenge wurde beim nächsten Neustart gelöscht, obwohl `persist` sie korrekt geladen hatte — der Bug schlug NACH dem Laden zu). Fix: dieselbe Epoch-Plausibilitätsprüfung (`< 1000000000` → überspringen) wie bei der Nachtruhe-Prüfung auch für `check_hour_rollover()` ergänzen.

Zusätzlich: erster Tick nach jedem Neustart setzt nur die Counter-Basiswerte (`last_counter1`/`last_counter2`), OHNE ein Delta zu berechnen — sonst würde der komplette seit dem letzten Neustart aufgelaufene Tasmota-Counter-Stand (der über manche Neustarts hinweg im RTC-Speicher erhalten bleibt) fälschlich als Regen/Wind in der ersten Sekunde nach dem Neustart gezählt.

Verifiziert per Simulation: `Counter1 <wert>` künstlich erhöhen, `Rain24h` prüfen, `Restart 1`, erneut prüfen — Wert bleibt jetzt über mehrere Neustarts hinweg korrekt erhalten.

## 12. Regen-Vibrationsunterdrückung durch den PV-Solartracker (Cross-MQTT)

⚠️ **Live gefunden (2026-07-20):** Der PV-Solartracker (`esp_solar`, [followmysun-deploy](https://github.com/) — separates Projekt) hängt im selben Schuppen wie die Wetterstation. Jede Nachführbewegung des Aktuators erzeugt genug mechanische Vibration, um am Reed-Kontakt des Regenmessers (`Counter1`) falsche Kippen auszulösen — die Bewegung "klingt" für den Reed-Kontakt wie Regen. `CounterDebounce` (Abschnitt 2) filtert nur Kontaktprellen im Millisekundenbereich, keine anhaltende Vibration über mehrere Sekunden, und `Counter1` selbst hat keine Rules-Ebene davor (reiner Hardware-Pulszähler). Ein Fix musste daher im Berry-Skript selbst ansetzen.

**Lösung:** [firmware/berry/autoexec.be](../firmware/berry/autoexec.be) abonniert per `mqtt.subscribe()` zusätzlich zwei Topics des Solartrackers auf demselben MQTT-Broker (10.10.12.100):

- `tele/solar/SENSOR` → Feld `SENSOR.Motion` (0=Stopp, 1=Hoch, 2=Runter, siehe `solar_main.py`). Bewegung aktiv → Regen-Unterdrückung bis zu einem Hard-Cap von `RAIN_SUPPRESS_MAX_S=120` s ab Bewegungsbeginn verlängern. Bewegung gestoppt → nur noch `RAIN_SUPPRESS_TAIL_S=5` s Nachlaufzeit (mechanisches Nachschwingen), dann automatisch aus.
- `tele/solar/LWT` → bei `"Offline"` die Unterdrückung sofort aufheben (Fail-Safe, falls der Tracker ausfällt/hängen bleibt, bevor er "Stopp" meldet — sonst würde die Regenmessung dauerhaft blind bleiben).

Während der Unterdrückung wird der `Counter1`-Delta **nicht** verworfen, sondern separat in `RainSuppressedMM`/`RainSuppressCount` mitgezählt (Diagnose/Tuning) — `Rain24h` bleibt unverändert. `last_counter1` wird trotzdem weitergeschrieben, damit der unterdrückte Delta nicht am Ende der Unterdrückung auf einen Schlag nachgezählt wird.

Neue Felder in der `IceWeather`-MQTT-JSON (`tele/.../SENSOR`) sowie im Tasmota-Web-UI (nur sichtbar, sobald mindestens einmal unterdrückt wurde):

```json
"IceWeather":{"WindSpeed":0.67,"WindDir":135,"Rain24h":61.19,"RainSuppressActive":0,"RainSuppressedMM":1.12,"RainSuppressCount":2}
```

Für Home Assistant empfiehlt sich ein weiterer `customize`-Eintrag analog Abschnitt 10:
```yaml
    sensor.tasmota_iceweather_rainsuppressedmm:
      unit_of_measurement: "mm"
```
⚠️ Dieser Eintrag war hier nur als Empfehlung notiert, aber nie tatsächlich in `packages/iceweatherstation.yaml` ergänzt worden — erst am 2026-07-23 nachgeholt (Anlass: `RainSuppressedMM` fehlte komplett im Dashboard, siehe Abschnitt 14), zusammen mit einer eigenen Zeile in der Entities-Karte ("Regen unterdrückt (Solartracker)").

**Verifiziert am echten Gerät (2026-07-20), per `mosquitto_pub` simulierte Tracker-Nachrichten + `Counter1 <wert>`-Testkippen:**
1. `Motion:1` per MQTT gesendet → `RainSuppressActive` wechselt sofort auf `1`.
2. Während aktiver Unterdrückung `Counter1` künstlich um 3 erhöht → `Rain24h` bleibt unverändert, `RainSuppressedMM`/`RainSuppressCount` steigen korrekt.
3. `Motion:0` gesendet, 5s Nachlaufzeit abgewartet → `RainSuppressActive` wird `0`.
4. Danach `Counter1` erneut erhöht (simuliert echten Regen) → wird wie gewohnt in `Rain24h` gezählt.
5. Fail-Safe: `tele/solar/LWT`→`"Offline"` während aktiver Unterdrückung gesendet → `RainSuppressActive` fällt sofort auf `0` (nicht erst nach 120s Hard-Cap).
6. Während der Tests startete der reale Solartracker zufällig neu und führte eine echte Nachführbewegung aus (`stat/solar/DEBUG`: `"Motor: Hoch"` → `"Motor: Stopp (overshoot)"`) — dabei stieg `RainSuppressCount` real um 1 (echte Vibrationskippe korrekt unterdrückt), `Rain24h` blieb dabei unverändert. Bestätigt die Funktion nicht nur synthetisch, sondern mit echtem Tracker-Verkehr.

⚠️ Die Testkippen (Schritte 2 und 4) haben `Rain24h`/`persist.rain_hourly` um insgesamt ca. 0,28 mm real erhöht (Schritt 4, absichtlich außerhalb des Unterdrückungsfensters ausgelöst, um die Normalzählung zu prüfen) — vernachlässigbar und läuft mit dem rollierenden 24h-Fenster von selbst wieder heraus.

## 13. OLED-Dashboard auf 4 Zeilen erweitert + weitere Werte in Home Assistant (2026-07-23)

Nach Live-Betrieb kamen zwei Fixes und eine Erweiterung dazu:

**BME280-Erkennung endgültig gefixt:** `USE_DISPLAY` aktiviert in `my_user_config.h` ungewollt auch `USE_DISPLAY_MATRIX`/`USE_DISPLAY_SEVENSEG` mit (die dort nur optisch, nicht tatsächlich per Präprozessor geguardet sind). Deren Boot-Zeit-I2C-Probe beansprucht Adresse `0x76` — identisch mit dem BME280 — und kommt ihm zuvor, sodass BME280 nie erkannt wurde (`SevenSeg found at 0x76` im Boot-Log). Fix in [`user_config_override.h`](../firmware/custom-build/user_config_override.h):
```c
#undef USE_DISPLAY_MATRIX
#undef USE_DISPLAY_SEVENSEG
```
Zusätzlich hatte das BME280-Breakout selbst einen Wackelkontakt (eine der 4 Leitungen) — sichtbar daran, dass der rohe `I2CScan` (Hardware-ACK-Ebene) den Sensor auch im stabilen Dauerbetrieb konsequent vermisste, während AS3935+OLED am selben Bus einwandfrei liefen. Nach Kontakt-Reparatur erscheint `0x76` sofort im `I2CScan` — **Tasmotas BME280-Treiber initialisiert Sensoren aber nur einmal beim Boot**, ein reiner `I2CScan` reicht danach nicht aus. Immer zusätzlich `Restart 1` senden.

**OLED-Layout erweitert** (Zeilenformat siehe Kopf-Kommentar in [autoexec.be](../firmware/berry/autoexec.be)):
```
Zeile 3: <Temperatur>C <Luftdruck> <Trend U/D/-> <Feuchte>%      (Feuchte neu)
Zeile 4: <Regen laufende Stunde>L <Schallpegel>dBA <Blitz-Distanz>KM   (komplett neu)
```
`rain_this_hour()` liest einfach `persist.rain_hourly[<aktuelle Stunde>]` aus — genau der Wert, den `check_hour_rollover()` schon laufend befüllt und erst bei Stundenwechsel zurücksetzt (Abschnitt 11), kein zusätzlicher Zustand nötig.

**Neue Werte auch in Home Assistant:** BME280-Feuchte, dBA-Schallpegel (`ANALOG.Range1`) und AS3935-Blitzdistanz waren als Standard-Tasmota-JSON-Felder bereits automatisch als eigene Entities in HA vorhanden (`sensor.tasmota_bme280_humidity`, `sensor.tasmota_analog_range1`, `sensor.tasmota_as3935_distance_2`) — nur ohne sinnvolle Einheit/Namen. Einzig `RainHour` existierte bisher nur im Berry-Skript-RAM fürs OLED; analog zu `Rain24h` (Abschnitt 10) in `json_append()` ergänzt, dadurch erscheint automatisch `sensor.tasmota_iceweather_rainhour`.

`packages/iceweatherstation.yaml` (HA-seitig, nicht in diesem Repo) um die passenden Einheiten erweitert:
```yaml
    sensor.tasmota_iceweather_rainhour:
      unit_of_measurement: "mm"
    sensor.tasmota_analog_range1:
      unit_of_measurement: "dBA"
      friendly_name: "IceWeatherstation Schallpegel"
```
Dashboard-Karte (`dashboards/wetter.yaml`, Tab „Aktuell") um BME280-Temperatur/-Feuchte/-Druck, Regen/Stunde und Schallpegel ergänzt, dritte Gauge (Feuchte) neben den beiden Temperatur-Gauges hinzugefügt, veralteten "BME280 noch nicht verbaut"-Hinweis entfernt. Ergebnis:

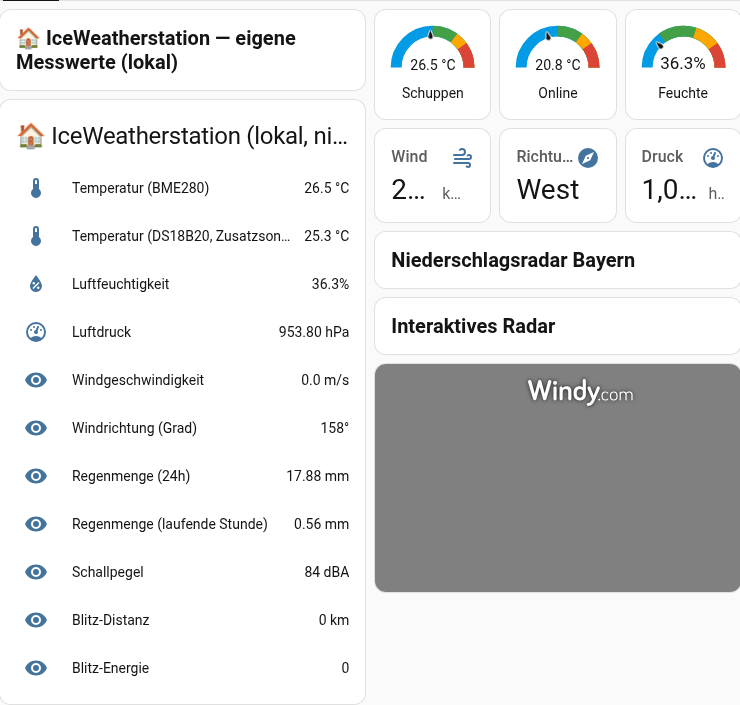
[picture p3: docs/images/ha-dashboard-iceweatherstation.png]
Home Assistant Dashboard mit allen IceWeatherstation-Messwerten


## 14. BME280 zeigt zu warm: Strahlungswärme statt Messfehler (2026-07-23)

Live beobachtet: BME280 zeigte zeitweise **6-8°C mehr** als der DS18B20 (z.B. 31,9°C vs. 25,1°C zur selben Sekunde). Ursache ist keine Sensor-Ungenauigkeit, sondern die **Montage**: Das BME280-Breakout sitzt direkt auf dem Prepboard an der Gehäusewand (angeklebt), die in direkter Sonneneinstrahlung steht — die Wand heizt sich auf und strahlt Wärme auf den Sensor ab. Der DS18B20 dagegen ragt als Messstift unten aus dem Gehäuse und ist nicht direkt besonnt.

⚠️ **Bewusst KEIN fixer Kalibrierungs-Offset**: Ein konstanter Korrekturwert (z.B. "BME280 minus 6,8°C") wäre nur für exakt die Sonnenbedingungen zum Messzeitpunkt richtig — nachts oder bei Bewölkung gibt es keine Strahlungswärme, ein fixer Offset würde den BME280 dann fälschlich zu kalt zeigen. Das ist ein Strahlungsschutz-Problem (fehlender Sonnenschutz/Radiation Shield), kein Kalibrierungsproblem — vergleichbar mit einem Thermometer, das man in die pralle Sonne statt in eine Wetterhütte hängt. Tasmota hat zwar einen globalen `TempOffset`-Befehl (`Settings->temp_comp`, siehe `support_command.ino`), der wirkt aber auf **alle** Temperatursensoren gleichzeitig und kann daher nicht BME280 und DS18B20 unterschiedlich korrigieren.

**Fix:** DS18B20 ist jetzt die primäre/angezeigte Lufttemperatur, sowohl auf dem OLED (Zeile 3, siehe [autoexec.be](../firmware/berry/autoexec.be)) als auch im Home-Assistant-Dashboard (`sensor.tasmota_ds18b20_temperature` zuerst gelistet + als "Schuppen"-Gauge). BME280 bleibt für Luftdruck/Luftfeuchte aktiv (davon nicht in gleichem Maß betroffen) sowie als Diagnose-Wert sichtbar, aber klar mit "Sonneneinfluss - unzuverlässig" beschriftet.

⚠️ **Nebeneffekt, im Auge zu behalten:** Die BME280-Luftfeuchte ist bei Überhitzung ebenfalls potenziell verfälscht (ein zu warmer Sensor zeigt relative Feuchte tendenziell zu niedrig) — noch nicht separat korrigiert, da schwerer zu quantifizieren als die Temperatur.

**Langfristig sauberer Fix (nicht umgesetzt, Hardware-Änderung nötig):** BME280 physisch von der Gehäusewand weg an einen beschatteten Punkt versetzen, oder einen kleinen Strahlungsschutz (z.B. einfacher weißer Trichter/Lamellenschutz) darüber montieren.

**Dashboard-Kompaktierung:** Die Entities-Karte "🏠 IceWeatherstation" hatte serienmäßig sehr große Zeilenabstände (HA bietet dafür keine native Dichte-Einstellung). Fix per `card_mod` in `dashboards/wetter.yaml`:
```yaml
card_mod:
  style: |
    #states > * {
      margin-top: -8px !important;
      margin-bottom: -8px !important;
    }
```

**Nachtrag (gleicher Tag):** Beim Durchgehen des Dashboards fiel auf, dass `RainSuppressedMM` (Regen-Vibrationsunterdrückung durch den Solartracker, Abschnitt 12) trotz existierender Entity nirgends sichtbar war — die dortige `customize`-Empfehlung war nie tatsächlich umgesetzt worden. Jetzt nachgeholt: Einheit `mm` ergänzt und als eigene Zeile "Regen unterdrückt (Solartracker)" in die Entities-Karte aufgenommen, direkt unter `RainHour`. `RainSuppressActive`/`RainSuppressCount` bewusst nicht mit aufgenommen (zu granular für die Hauptkarte, meist `0`).

## 15. Luftdruck-Grafiken hatten Datenlücken: BME280-Read-Freeze + Watchdog (2026-07-28)

Die "Luftdruck - Tag"/"Luftdruck - Monat"-Grafiken im Dashboard hatten größere Lücken (bis zu ~19h). Root Cause per direkter SQLite-Auswertung der HA-Recorder-DB gefunden: `sensor.tasmota_bme280_pressure` blieb über Stunden auf exakt demselben Wert stehen (`last_updated` fror ein), während `sensor.tasmota_ds18b20_temperature` und die `IceWeather`-Werte im selben Gerät ganz normal weiterliefen.

Live-Diagnose bestätigte: `I2CScan` fand das BME280 weiterhin korrekt auf dem Bus (`0x76` ACKt), aber `tele/SENSOR` lieferte über mehrere aufeinanderfolgende Zyklen bit-identische Pressure/Temperature/Humidity-Werte — der Sensor ist am Bus erreichbar, aber Tasmotas BME280-Treiber liefert bei einem fehlgeschlagenen Read offenbar stillschweigend den letzten Cache-Wert statt eines Fehlers. Das ist eine andere Fehlerart als der frühere komplette Wackelkontakt-Ausfall (Abschnitt "BME280 wackelkontakt", `I2CScan` fand dort gar nichts) — hier bleibt der Bus-Kontakt bestehen, nur die Read-Loop hängt.

**Sofort-Fix:** `Restart 1` per MQTT (`cmnd/iceweatherstation/Restart`) initialisiert den Sensor-Read neu — Pressure sprang danach sofort von den eingefrorenen 953,6 hPa auf den tatsächlichen aktuellen Wert.

**Dauerhafter Fix — Watchdog:** Da das jetzt zum zweiten Mal auftrat (22./23.07. ~19h, 27./28.07. ~5,5h) und beide Male unbemerkt blieb bis zur manuellen Prüfung, gibt es jetzt einen automatischen Watchdog nach demselben Muster wie der bestehende Ubertooth-MQTT-Watchdog:

- `/opt/iceweatherstation-watchdog/watchdog.sh` (auf NUC-HA) vergleicht bei jedem Lauf die BME280-Signatur (Pressure+Temperature+Humidity) aus `tele/iceweatherstation/SENSOR` gegen eine Marker-Datei (`/run/iceweatherstation-watchdog.state`).
- Bleibt die Signatur ≥30 Minuten unverändert, sendet der Watchdog `cmnd/iceweatherstation/Restart 1` und setzt den Marker zurück.
- systemd-Timer `iceweatherstation-watchdog.timer` (10-Minuten-Takt, `OnBootSec=10min`/`OnUnitActiveSec=10min`) triggert `iceweatherstation-watchdog.service` (`Type=oneshot`).
- 30 Minuten identischer Werte für Druck **und** Temperatur **und** Feuchte gleichzeitig ist physikalisch praktisch ausgeschlossen — echte Wetterwerte schwanken auf Dezimalstellen-Ebene ständig, daher keine Fehlalarm-Gefahr bei normalem Betrieb.
- Diese Watchdog-Dateien liegen (wie beim Ubertooth-Watchdog) direkt auf NUC-HA unter `/opt/` und `/etc/systemd/system/`, nicht in diesem Repo.

Historische Lücken in den bestehenden Grafiken lassen sich nicht rückwirkend füllen (die Werte wurden nie echt gemessen), ab jetzt sollte es aber keine mehrstündigen Lücken mehr geben.

Weiter mit dem [Setup-Guide](setup-guide.md) für die komplette Schritt-für-Schritt-Anleitung inklusive Home-Assistant-Einbindung.

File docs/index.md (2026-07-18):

# IceWeatherstation

DIY-Wetterstation auf Basis **ESP32 + Tasmota**: Temperatur, Luftfeuchte, Luftdruck, eine wasserdichte Zusatz-Temperatursonde, Wind (Geschwindigkeit + Richtung), Regenmenge, **Blitzerkennung** (AS3935/Franklin-Sensor) und ein **kalibrierter dBA-Schallpegelmesser**.

[Quellcode auf GitHub](https://github.com/icepaule/IceWeatherstation)

## Status

✅ **Erstes Gerät aufgebaut, geflasht und am Schuppen im Betrieb (Stand 2026-07-19).** DS18B20, Regenmesser, Anemometer, Windfahne, dBA-Sensor, AS3935 (Blitz) und OLED-Display sind verkabelt, kalibriert und live verifiziert; MQTT + Home-Assistant-Anbindung läuft. Noch offen: BME280 (Temperatur/Feuchte/Druck) ist bestellt, aber noch nicht geliefert/verbaut.

<p float="left">
  Offenes Gehäuse mit Verkabelung, Windfahne/Anemometer im Hintergrund
  Montage am Schuppendach, Anemometer/Windfahne auf dem Mast
</p>

## Dokumentation

| Seite | Inhalt |
|---|---|
| [Setup-Guide](setup-guide) | **Schritt-für-Schritt-Anleitung**: Aufbau, Flashen, Konfiguration, Home-Assistant-Einbindung |
| [Teileliste (BOM)](bom) | Vollständige Teileliste mit Bezugsquellen |
| [Verkabelung](wiring) | Pinbelegung + Verkabelungskonzept |
| [Gehäuse](enclosure) | Gehäuse, Mast-Montage, wetterfestes Mikrofongehäuse (DNMS-Design) |
| [MISOL-Kompatibilität](misol-compatibility) | Warum keine MISOL-Fertigsensorik als Plug-and-Play funktioniert |
| [Tasmota-Konfiguration](tasmota-config) | Firmware-Konfiguration, alle live gefundenen Fallstricke |
| [Firmware](https://github.com/icepaule/IceWeatherstation/tree/main/firmware) | Custom-Build, fertige Binaries, Berry-Skript |

## Hardware-Kurzüberblick

| Sensor | Bauteil | Werte |
|---|---|---|
| Temp/Feuchte/Druck | Bosch BME280 (I2C) | °C, %rH, hPa |
| Zusatz-Temperatur | DS18B20 (wasserdicht, 1-Wire) | °C |
| Wind | SparkFun Weather Meter Kit SEN-15901 | m/s, Richtung (Grad) |
| Regen | SparkFun Weather Meter Kit SEN-15901 | mm (Kippwaage) |
| Blitz | AS3935 / CJMCU-3935 (I2C) | Ereignis, Distanz (km), Energie |
| Schallpegel | DFRobot Gravity SEN0232 (analog) | dBA, 30–130 dB, A-bewertet |

## Quellen / Credits

- [ampheo.com Blog](https://www.ampheo.com/blog/how-to-build-a-smart-weather-station-with-sensors) — Grundkonzept
- [SparkFun Weather Meter Kit SEN-15901 Hookup Guide](https://learn.sparkfun.com/tutorials/weather-meter-hookup-guide) — Wind/Regen-Sensorik
- [DFRobot Gravity SEN0232 Wiki](https://wiki.dfrobot.com/Gravity_Analog_Sound_Level_Meter_SKU_SEN0232) — dBA-Kalibrierung
- [sensor.community DNMS-Projekt](https://sensor.community/en/sensors/dnms/) — Wetterschutzgehäuse-Design fürs Mikrofon
- [rtl_433 Projekt](https://github.com/merbanan/rtl_433) — `fineoffset.c`-Decoder, Grundlage der MISOL-Kompatibilitätsanalyse
- [Tasmota-Dokumentation](https://tasmota.github.io/docs/) — Firmware-Referenz

MIT-Lizenz, siehe [LICENSE](https://github.com/icepaule/IceWeatherstation/blob/main/LICENSE).

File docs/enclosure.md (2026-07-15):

# Gehäuse & Wetterschutz

## Hauptgehäuse

IP65-Elektronikgehäuse (Polycarbonat oder ABS, ~200×120×75mm) nimmt ESP32, BME280, AS3935, SEN0232 und die Verkabelung auf. Kabelverschraubungen (IP68) für:

- Wetterkabel-Bündel zu Anemometer/Windfahne/Regenmesser (SEN-15901, RJ11-Anschlüsse)
- DS18B20-Sonde
- Stromzuleitung
- Mikrofonrohr (siehe unten) — **hier keine dichte Verschraubung**, sondern eine belüftete Lösung

Ein Silikagel-Beutel im Gehäuse reduziert Kondenswasserbildung bei Temperaturwechseln.

## Wetterschutz für das dBA-Mikrofon (DNMS-Design)

Das SEN0232-Mikrofon braucht Zugang zur Außenluft, muss aber vor Regen und Windrauschen geschützt werden. Bewährtes Design aus dem [DNMS-Projekt](https://sensor.community/en/sensors/dnms/) von sensor.community: ein kurzes Elektroinstallationsrohr mit 90°-Bogen, Öffnung nach unten, mit Schaumstoff-Windschutz im Inneren.

```mermaid
flowchart TD
    A["Hauptgehäuse (IP65)<br/>SEN0232 sitzt innen, geschützt"] -->|"M20 IP68-Kabelverschraubung<br/>(belüftet, kein Vollverschluss)"| B["25mm-Elektrorohr, gerade,<br/>~80-100mm Länge"]
    B --> C["90°-Rohrbogen"]
    C --> D["Rohröffnung zeigt NACH UNTEN<br/>(Regenschutz)"]
    D --> E["Schaumstoff-Windschutz<br/>im Rohrinneren<br/>(reduziert Windrauschen)"]
```

**Warum diese Reihenfolge wichtig ist:**

1. **Öffnung nach unten** — verhindert, dass Regen direkt ins Rohr und zum Mikrofon läuft
2. **Schaumstoff im Inneren** — laut DNMS-Dokumentation "absolut notwendig", da Windrauschen sonst die dB-Messung verfälscht (Böen erzeugen tieffrequentes Rauschen, das die A-Bewertung nicht korrekt herausfiltert)
3. **SEN0232 bleibt im Hauptgehäuse** — nur die akustische Öffnung ragt nach außen, das Sensor-Modul selbst bleibt trocken

## Mast-Montage

```mermaid
flowchart TD
    MAST["Alu-Rundrohr (1-2m)<br/>vertikal montiert"]
    MAST --> TOP["Kopfende: Anemometer + Windfahne<br/>(freier, ungestörter Luftstrom nötig)"]
    MAST --> MID["Mittig: U-Bolzen-Halterung<br/>für Antennenmast/Wandhalterung"]
    MAST --> BOX["Unten/seitlich: IP65-Hauptgehäuse<br/>+ AS3935-Antenne frei montiert"]
```

**Montage-Hinweise:**
- Anemometer und Windfahne so hoch wie möglich, frei von Turbulenzen durch Gebäude/Bäume
- AS3935 reagiert empfindlich auf EMI — Antenne/Sensor nicht direkt neben Stromkabeln oder Metallmasten platzieren
- Regenmesser (Kippwaage) muss exakt waagerecht montiert sein, sonst systematischer Messfehler — mit Wasserwaage ausrichten

Weiter mit: [tasmota-config.md](tasmota-config.md) oder zurück zum [setup-guide.md](setup-guide.md) für die Gesamt-Reihenfolge.

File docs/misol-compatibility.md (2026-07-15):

# Warum keine MISOL-Fertigsensorik?

Ursprünglich stand zur Debatte, günstige Fertigsensorik von MISOL ("Spare Part Outdoor Unit für professionelle Funk-Wetterstationen") statt des SparkFun Weather Meter Kits zu verwenden — deutlich günstiger, aber mit einem entscheidenden Unterschied im Funktionsprinzip.

## Das Problem

Die MISOL-Sensorik (Wind/Regen/Temp/Feuchte) ist **keine** einfache GPIO-Sensorik wie im ampheo.com-Blog-Artikel beschrieben, sondern die komplette Sensorik einer **fertigen 433-MHz-Funk-Wetterstation**. Laut Quellcode des [rtl_433-Projekts](https://github.com/merbanan/rtl_433) (`fineoffset.c`-Decoder) ist die Hardware mit hoher Wahrscheinlichkeit **Fine-Offset/WH65-kompatibel** und wird dort explizit als "Misol WS2320" gelistet.

Der Hersteller garantiert selbst **keine** Kompatibilität zu Fremdgeräten — die Sensorik ist dafür gebaut, an den mitgelieferten Funkempfänger zu senden, nicht für einen direkten GPIO-Anschluss an einen Mikrocontroller wie den ESP32.

## Zwei mögliche Wege, falls MISOL trotzdem gewünscht ist

Keiner davon ist "plug and play":

```mermaid
flowchart LR
    START["MISOL Spare-Part-Sensorik"]
    START --> A["Weg A: Direktverkabelung"]
    START --> B["Weg B: Funkweg via RTL-SDR"]

    A --> A1["Platine öffnen"]
    A1 --> A2["Reed-Kontakt (Regen) anzapfen"]
    A1 --> A3["Hall-Sensor (Anemometer) anzapfen"]
    A1 --> A4["Potentiometer (Windfahne) anzapfen"]
    A2 --> A5["Original-Funkteil ausbauen"]
    A3 --> A5
    A4 --> A5
    A5 --> A6["1:1-GPIO-Integration wie SparkFun-Kit"]

    B --> B1["RTL-SDR-Dongle"]
    B1 --> B2["rtl_433-Add-on<br/>(z.B. in Home Assistant)"]
    B2 --> B3["Original-Sender bleibt aktiv"]
    B3 --> B4["Empfang der Funktelegramme"]
```

| Weg | Aufwand | Bewertung |
|---|---|---|
| **A. Direktverkabelung** | Löten/Basteln (Platine öffnen, Original-Funkteil ausbauen, Reed-/Hall-/Potentiometer-Signale direkt anzapfen), danach 1:1-GPIO-Integration wie beim SparkFun-Kit | Mehrfach von anderen Bastlern für baugleiche Fine-Offset-Sensorik dokumentiert (z.B. [github.com/pilotak/WeatherMeters](https://github.com/pilotak/WeatherMeters), diverse Home-Assistant-Community-Threads). Funktioniert nachweislich für ähnliche Hardware, aber nicht für jede MISOL-SKU einzeln belegt |
| **B. Funkweg via RTL-SDR** | Kein Löten, aber zusätzliche Hardware (SDR-Dongle) + separater Empfangspfad, z.B. über eine Home-Assistant-Integration | Protokoll-Kompatibilität sehr wahrscheinlich (Fine-Offset-Protokollfamilie ist in `rtl_433` gut dokumentiert), aber nicht 1:1 für jede konkrete SKU verifiziert |

## Warum stattdessen SparkFun SEN-15901

Das [SparkFun Weather Meter Kit](https://www.sparkfun.com/weather-meter-kit.html) ist zwar teurer, aber:

- Dokumentierte, offene GPIO-Schnittstelle (Reed-Kontakte + Potentiometer direkt über RJ11-Kabel)
- Offizieller [Hookup Guide](https://learn.sparkfun.com/tutorials/weather-meter-hookup-guide) mit exakten Umrechnungsformeln
- Kein Löt-/Bastelrisiko, "aus der Tüte funktionierend"

**Wichtig bei beiden Wegen (MISOL wie SparkFun):** Die Windfahne braucht in der Praxis eine manuelle Kalibrierung — die Datenblattwerte stimmen laut mehreren Quellen nicht exakt mit der real gemessenen Spannung überein.

Zurück zur [Teileliste](bom.md).

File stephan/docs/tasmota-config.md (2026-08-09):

# Tasmota-Konfiguration — Stephans Version

Firmware: dieselbe Sonder-Firmware wie das Originalgerät (Tasmota 15.5.0, AS3935+OLED-Support kombiniert
— der AS3935-Treiber ist enthalten, aber ungenutzt, da kein Blitzsensor verbaut ist). Bezug/Eigenbau:
[../../firmware/README.md](../../firmware/README.md).

## 1. GPIO-Konfiguration

```
Backlog GPIO21 640;GPIO22 608;GPIO4 1312;GPIO14 352;GPIO27 353;GPIO34 4704;GPIO35 4864;GPIO32 6210;GPIO2 288
```

| GPIO | Rolle | Bauteil |
|---|---|---|
| 21 | I2C SDA1 | BME280 + OLED |
| 22 | I2C SCL1 | BME280 + OLED |
| 4 | DS18x201 | DS18B20 |
| 14 | Counter1 | Regenmesser |
| 27 | Counter2 | Anemometer |
| 34 | ADC Input1 | Windfahne |
| 35 | ADC Range1 | MQ135 (siehe Abschnitt 3 — bewusst nicht "ADC MQ") |
| 32 | Option A3 | virtueller Marker fürs OLED, kein physischer Pin |
| 2 | Led1 | Status-LED (bewusst "Led", nicht "LedLink" — siehe Abschnitt 4) |

**Hinweis:** IO14/IO27 sind hier bewusst gegenüber dem Originalgerät vertauscht (dort: 27=Regenmesser,
14=Anemometer) — passend zur tatsächlichen Verkabelung bei Stephans Aufbau. Counter1/Counter2 sind rein
softwareseitig vergebene, funktional identische Rollen; welcher physische Pin welchen Namen bekommt, ist
frei wählbar. Details zum Fund: [wiring.md](wiring.md).

Windfahne zusätzlich auf reine 1:1-Durchreichung gestellt (kein AdcParam-Range-Effekt gewünscht):

```
AdcParam1 6,0,4095,0,4095
```

MQ135 ebenso, da die Rolle "ADC Range1" ohne diesen Parameter eine eigene Skalierung anwenden würde
(mit 4 Nullen liefert sie sonst `null` statt eines Rohwerts, siehe Abschnitt 3):

```
AdcParam2 6,0,4095,0,4095
```

### Warum ein ESP32 hier zwei verschiedene ADC-Rollen braucht

Ein ESP32-Board unterstützt offenbar nur **eine** Instanz der Rolle "ADC Input" gleichzeitig — live
verifiziert: eine zweite GPIO-Zuweisung auf denselben Rollencode ersetzt die erste, statt eine zweite
Instanz zu erzeugen. Windfahne und MQ135 brauchen aber beide einen rohen 0–4095-Wert. Lösung: Windfahne
behält "ADC Input1" (IO34, JSON-Schlüssel `A1`), MQ135 nutzt stattdessen "ADC Range1" (IO35,
JSON-Schlüssel `Range1`) mit der oben gezeigten Identitäts-Skala — liefert denselben rohen Rückgabewert,
nur unter anderem Namen.

**Bekannter kosmetischer Nebeneffekt:** Die im Custom-Firmware-Build fest einkompilierten Web-UI-Labels
(`friendly-labels.patch`, ursprünglich fürs Originalgerät geschrieben) benennen die Rolle "ADC Range" fest
zu "Schallpegel...dBA" um, weil dort beim Originalgerät tatsächlich der Schallpegelsensor hängt. Da
Stephans Version keinen Schallsensor hat, zeigt diese Zeile im Web-UI den MQ135-Rohwert unter falschem
Label. Nur per Firmware-Neubau behebbar (Patch anpassen), nicht per Tasmota-Befehl. Die tatsächlich
korrekt benannte "Luftqualität"-Zeile (siehe Abschnitt 3) ist die maßgebliche Anzeige — die
"Schallpegel"-Zeile kann ignoriert werden.

## 2. Status-LED

```
LedState 0
```

Bewusst **kein** `LedState 7` (wie beim Originalgerät, das MQTT nutzt) — ohne MQTT gibt es keine
Aktivität, die Tasmotas eingebaute Blink-Logik triggern könnte. Stattdessen steuert das Dashboard-Skript
(`firmware/autoexec.be`) die LED komplett manuell über `LedPower1`, ausgelöst bei jedem Abruf der
Sensor-Tabelle (`web_sensor()`-Hook) — das passiert insbesondere bei jedem AJAX-Poll, den die
Tasmota-Startseite alle paar Sekunden ausführt, solange der Browser-Tab aktiv geöffnet ist. Ergebnis: LED
blinkt bei WLAN-Datentransfer, funktional ähnlich zum MQTT-Blinken des Originalgeräts, aber ohne
MQTT-Abhängigkeit.

**Wichtiger Fallstrick:** GPIO2 muss die Rolle **"Led"** (288) haben, nicht **"LedLink"** (544) — Letztere
hat ein eigenes, fest verdrahtetes Verbindungsstatus-Verhalten (sprang im Test selbstständig auf
`LedState 8`, "an wenn WLAN verbunden", obwohl das Skript das nirgends setzt) und überschreibt jede
manuelle Steuerung über `LedPower`. Mit der Rolle "Led" bleibt `LedState 0` stabil.

Der Blink-Puls ist auf maximal 1× pro 2 Sekunden gedrosselt (`LED_PULSE_MIN_GAP_S` im Skript) — bei
schnellerem Browser-Poll-Takt (live gemessen: teils <1s statt der angenommenen ~2,3s) würde sonst jeder
neue Aufruf den 400ms-Ausschalt-Timer des vorherigen Blitzes überholen (Tasmota ersetzt einen benannten
Timer beim erneuten Setzen) und die LED bliebe dauerhaft an statt sichtbar zu blinken.

In der Nachtruhe (22:00–08:00 Uhr) bleibt die LED unabhängig vom Traffic durchgehend aus.

## 3. MQ135-Eigenkalibrierung

Tasmotas eingebaute MQ-Sensor-Formel (`AdcParam` Typ 10, Rolle "ADC MQ") wurde getestet und über 5 Minuten
Laufzeit live beobachtet — lieferte durchgehend einen implausiblen Wert (~2,9 statt der erwarteten
Größenordnung 400–2000 ppm), unabhängig von der Uptime. Vermutete Ursache: der eingebaute Treiber geht
von einem anderen Spannungsteiler-/Referenzspannungs-Aufbau aus als unserem (10 kΩ + 15 kΩ an einem
3,3V-ADC).

Deshalb berechnet das Dashboard-Skript den ppm-Wert komplett selbst aus dem rohen ADC-Wert, nach demselben
Verfahren wie bereits produktiv laufende, baugleiche MQ135-Sensoren im eigenen Heimnetz (deren Skript als
Vorlage übernommen), aber mit dem eigenen Spannungsteiler-Verhältnis statt eines abweichenden Faktors:

```berry
var MQ_VC = 5.0              # Sensor-Versorgungsspannung (Heizer an 5V)
var MQ_DIVIDER_RATIO = 0.6   # eigener Spannungsteiler: 15k/(10k+15k)
var MQ_A = 116.6020682       # gaengige Community-Kurve fuer MQ135 (CO2-aehnlich)
var MQ_B = -2.769034857
var MQ_RATIO_CLEAN_AIR = 3.6 # Rs/Ro-Verhaeltnis in sauberer Luft
var MQ_CAL_SECONDS = 180     # Kalibrierfenster nach Boot
```

**Kalibrier-Ablauf:** in den ersten 180 Sekunden nach jedem (Neu-)Start wird die Referenz `Ro`
kontinuierlich aus der aktuellen Sensor-Resistenz `Rs` nachgeführt (setzt normale/saubere Luft in dieser
Zeit voraus), danach eingefroren. Die Web-UI zeigt währenddessen "Kalibriere.. (noch Xs)" statt einer
Kategorie. Ein Neustart mitten in verrauchter/frisch gelüfteter Luft verzerrt die Baseline dauerhaft bis
zum nächsten Neustart — bekannter Fallstrick, der bei einem baugleichen Referenzgerät im eigenen Heimnetz
einmal zu einem impliziten Fehlalarm führte.

Die CO2-Kategorie-Schwellen (übliche Innenraum-Luftqualitäts-Bänder):

| Kategorie | Bereich |
|---|---|
| Sehr gut | < 800 ppm |
| Gut | 800–1000 ppm |
| Normal | 1000–1400 ppm |
| Schlecht | 1400–2000 ppm |
| Kritisch | > 2000 ppm |

## 4. Temperatur-Kalibrierung

```
TempOffset <Differenz in °C, -12.6 bis 12.6>
```

Wirkt global auf **alle** Temperatursensoren des Geräts gleichzeitig (kein Pro-Sensor-Wert in Tasmota) —
am besten erst nach der finalen Montage im Gehäuse kalibrieren, da sich die Eigenerwärmung durch die
Elektronik je nach Position/Gehäuse unterscheidet.

## 5. Windfahnen-Kalibrierung

`VANE_TABLE` im Dashboard-Skript ist **kein Platzhalter mehr**, sondern aus dem offiziellen
Fine-Offset-Datenblatt (`DS-15901-Weather_Meter.pdf`, Hersteller der SEN-15901-Sensorik) berechnet:
Datenblatt-Tabelle "Direction/Resistance" (16 Werte, 891 Ω–120 kΩ) durch die Spannungsteiler-Formel
`raw = 4095 * Rvane / (10000 + Rvane)` in erwartete rohe ADC-Werte umgerechnet — passend zu unserem
eigenen 10-kΩ-Spannungsteiler an 3,3V, identische Topologie wie im Datenblatt-Beispielschaltbild.

Dadurch reduziert sich die Kalibrierung auf einen rein **mechanischen** Schritt: beim Mastmontage die
"N"-Markierung auf dem Windfahnen-Sensor selbst nach echt Norden ausrichten. Kein Software-Abgleich, kein
Kompass-Offset im Skript mehr nötig — die Tabelle stimmt bereits mit echten Kompassrichtungen überein,
sofern die Fahne korrekt ausgerichtet montiert wird.

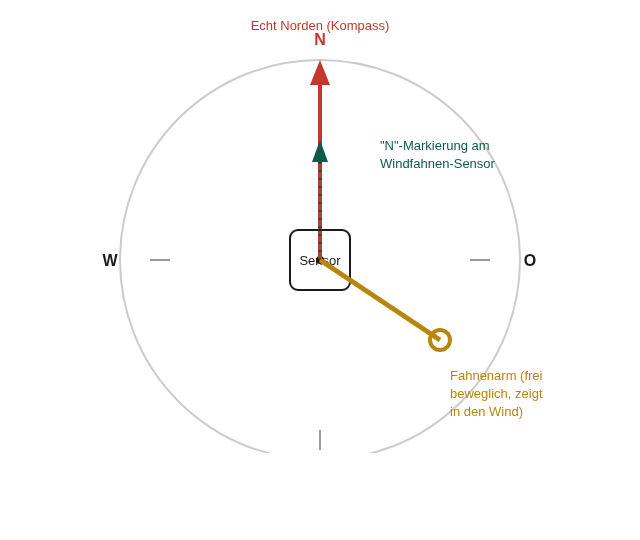
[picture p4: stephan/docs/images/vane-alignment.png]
Windfahnen-Ausrichtung nach Kompass


### Ausrichtungsprozedur bei der Montage

1. Windfahne auf ihre Achse/Lager montieren (noch nicht endgültig fixieren)
2. Kompass (echtes Gerät oder Handy-App) direkt daneben halten, echt Norden bestimmen
3. Sensorgehäuse so drehen, dass seine **"N"-Markierung** exakt nach Norden zeigt
4. Erst jetzt endgültig festschrauben/fixieren

**Wichtig — live gefunden (09.08.2026):** Eine Kompass-Gegenprobe funktioniert nur zuverlässig, wenn die
Fahne **fest auf ihrer Achse montiert** ist und frei in ihre 16 Rastpositionen einrasten kann. Von Hand
gehalten (z.B. zum schnellen Test auf dem Tisch) liefert der Rohwert keine eindeutigen Ergebnisse — die
Fahne trifft dabei praktisch nie exakt eine der festen Magnet-Positionen, sondern oft eine uneindeutige
Zwischenstellung (laut Datenblatt das Resultat zweier gleichzeitig aktiver Schalter). Getestet mit zwei
Handhaltungen (Norden, Süden): beide ergaben Rohwerte, die keiner sauberen 180°-Beziehung in der Tabelle
entsprachen — kein Defekt, sondern erwartetes Verhalten einer nicht fest montierten Fahne.

Optionale Gegenprobe **nach fester Montage**: `Status 10` → `ANALOG.A1` mit der Fahne in eine bekannte
Richtung gedreht abfragen und mit der Tabelle vergleichen.

## 6. WLAN-Setup vor Übergabe erneut aktivieren

**Das ist der letzte Software-Schritt, bevor das Gehäuse verschlossen und an Stephan übergeben wird** —
danach ist das Gerät nicht mehr über das Test-WLAN erreichbar.

Um wieder in den Ersteinrichtungs-Zustand (eigener Access Point + WLAN-Auswahl) zu wechseln, ohne
GPIOs/Skript/Kalibrierung zu verlieren, zwei gleichwertige Wege:

**Über die Konsole** (`cm?cmnd=` oder Konsolen-Eingabe):

```
WifiConfig 2
```

**Über die Weboberfläche** (funktioniert auch, falls die Konsole gerade z.B. durch eine Netzwerk-IPS
blockiert ist — live gefunden 09.08.2026, siehe unten): Configuration → Configure WiFi → SSID und Passwort
leeren → Save. Ohne gültige Zugangsdaten öffnet das Gerät beim nächsten Boot automatisch seinen eigenen
Access Point.

Beide Wege starten den WiFi-Manager: Gerät öffnet seinen eigenen Access Point **`Wetterstation-Stephan`**
mit Setup-Portal inkl. WLAN-Netzwerkauswahl — genau der Zustand nach dem Erstflashen. Bei der
Konsolen-Variante läuft das AP-Fenster 3 Minuten; passiert darin nichts, verbindet sich das Gerät
automatisch wieder mit dem zuletzt bekannten Netz (dann einfach erneut auslösen). Ein bloßes Löschen der
SSID per Konsolenbefehl (`SSID1 0`) reicht laut Tasmota-Dokumentation dagegen nicht zuverlässig, um den
AP-Modus auszulösen.

**Live gefunden (09.08.2026):** Nach längerem intensivem Testen des Geräts (viele Konsolen-Anfragen mit
`cmnd=`/Berry-Code-artigen Query-Strings) waren `/cm`, `/bc` und `/cn` plötzlich nicht mehr erreichbar
(leere TCP-Antwort), während die normale Sensor-Hauptseite weiter einwandfrei lief — auch nach einem
Neustart des Geräts nicht behoben. Ursache vermutlich eine Netzwerk-IPS (pfSense/Suricata), die die
anfragende Quelladresse wegen der vielen kommandoartigen Requests geblockt hat (bereits von einem früheren,
ähnlichen Fall bei der Originalstation bekannt). Der Web-UI-Weg über "Configure WiFi" ist davon nicht
betroffen und funktioniert als zuverlässige Rückfalloption.

**Für Stephan** (siehe [Bauanleitung](bauanleitung.pdf) Abschnitt 6): Nach dem Reset verbindet er sich mit
dem geöffneten Access Point `Wetterstation-Stephan` und trägt dort sein eigenes WLAN ein — danach ist das
Gerät dauerhaft in seinem Netz.

## 7. Kein MQTT

Bewusst nicht konfiguriert — Stephans Standort hat keine Home-Assistant-Instanz, alle Werte laufen über
die Tasmota-eigene Weboberfläche.

## 8. OLED-Anzeige — Bedeutung der vier Zeilen

Das Display zeigt die wichtigsten Kernwerte direkt am Gehäuse, auch ohne Handy/Browser in der Nähe.
Format (aus `refresh_display()` in `autoexec.be`):

| Zeile | Beispiel | Bedeutung |
|---|---|---|
| 1 | `-58dBm 192.168.1.42` | WLAN-Signalstärke (negativ, näher an 0 = besser; ab ca. -80 dBm wird's wacklig) + aktuelle IP-Adresse. Zeigt `No-WiFi`, wenn die WLAN-Verbindung gerade fehlt. |
| 2 | `2M 270° 3L` | **M** = Windgeschwindigkeit in m/s. **°** = Windrichtung in Grad wie am Kompass (0°/360°=Nord, 90°=Ost, 180°=Süd, 270°=West), im Uhrzeigersinn. **L** = Regenmenge der letzten 24h in Liter/m² — entspricht "mm Niederschlag" (1 mm Regen = 1 L/m²), nur anders benannt, kein Fehler. |
| 3 | `21.4C 1013 U 55%` | Temperatur in °C (vom DS18B20, bewusst nicht vom BME280 — Eigenerwärmungseffekt, siehe Abschnitt 4), Luftdruck in hPa (gerundet), Drucktrend (**U**p/**D**own/**-** = stabil), Luftfeuchte in % (vom BME280). |
| 4 | `Regen Stunde: 0.2L` | Regenmenge der aktuell laufenden Stunde, gleiche Einheit wie Zeile 2 (L = L/m² = mm). Setzt sich stündlich automatisch zurück. |

Nachts (22:00–08:00 Uhr, siehe `QUIET_START_HOUR`/`QUIET_END_HOUR`) bleiben Display und Status-LED
bewusst aus, um nicht zu stören — kein Fehler.

Weiter mit: [wiring.md](wiring.md) für die physische Verkabelung.

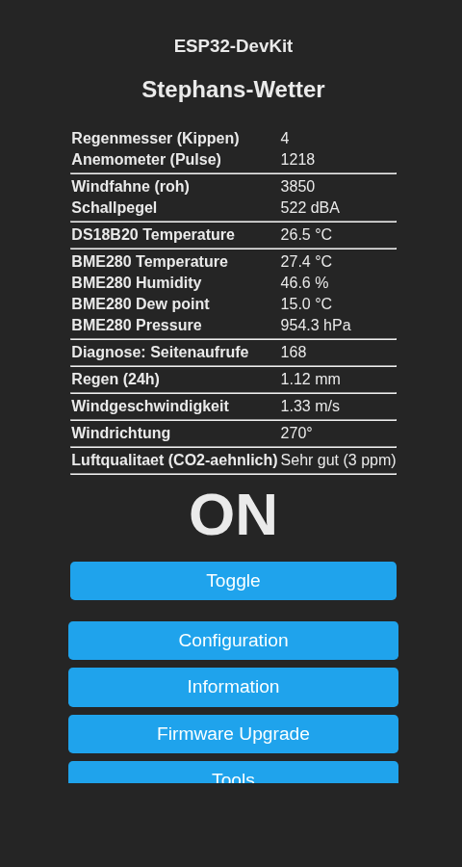
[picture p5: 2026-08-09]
stephan/docs/images/webui-home.png

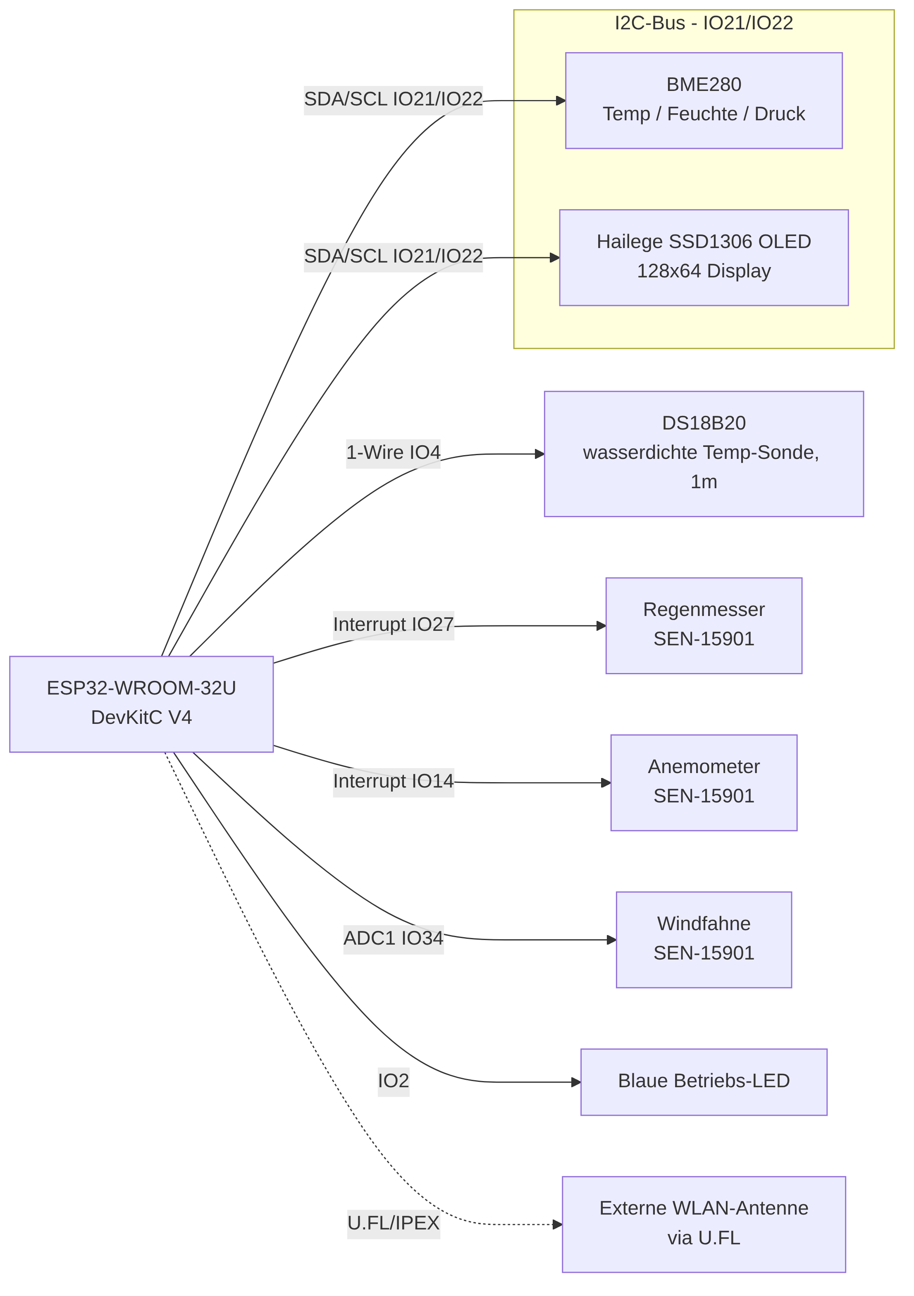
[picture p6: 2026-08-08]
stephan/docs/images/block-stephan.png

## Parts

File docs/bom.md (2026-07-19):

# Teileliste (BOM)

Für **zwei baugleiche Geräte**. Wo nichts anderes vermerkt ist, gilt die Menge pro Gerät (also ×2 bestellen).

> Preise sind Momentaufnahmen (Stand 2026-07-15) und können abweichen — vor der Bestellung selbst prüfen. Amazon-Wunschlisten zeigen beim Einfügen automatisch die aktuellen Preise an, deshalb sind hier bewusst nicht überall feste Preise hinterlegt.

## Kernkomponenten

| # | Bauteil | Modell | Menge | Bezugsquelle | Hinweis |
|---|---|---|---|---|---|
| 1 | Mikrocontroller | ESP32-WROOM-**32U**/32UE DevKitC V4, USB-C, externe Antenne (U.FL/IPEX) | 2× | Amazon.de / AZ-Delivery / AliExpress, Suche „ESP32-WROOM-32U DevKitC external antenna“ | **Bewusst 32U/32UE statt Standard-32E** — Standardmodul hat nur PCB-Antenne, keine externe Buchse |
| 2 | WLAN-Antenne | 2,4 GHz 3 dBi Antenne + U.FL/IPEX-zu-SMA-Pigtail | 2× | Amazon.de, Suche „U.FL IPEX SMA Pigtail 2.4GHz Antenne ESP32“ | Nicht direkt an Metallteilen montieren, freie Sichtlinie im Gehäuse |
| 3 | Temp/Feuchte/Druck | Bosch **BME280** I2C-Breakout (z.B. AZDelivery GY-BME280) | 2× | Amazon.de / AZ-Delivery | SDA→GPIO21, SCL→GPIO22 |
| 3b | Wetterschutz BME280 | TFA Dostmann Schutzhülle für Sender, weiß, 10,2×9,5×17,5cm | 2× | [Amazon.de](https://www.amazon.de), 12,99€/Stk. (Stand 2026-07-19) | Schützt vor Niederschlag/Sonneneinstrahlung bei guter Luftzirkulation — unter dem Hauptgehäuse montiert, damit BME280 nicht durch Eigenerwärmung des Gehäuses verfälschte Werte liefert |
| 4 | Zusatz-Temperatur | **DS18B20** Edelstahl-Sonde, wasserdicht, 1m Kabel | 2× | Amazon.de / AZ-Delivery „DS18B20 waterproof“ | GPIO4, 4,7 kΩ Pull-up gegen 3,3V nötig |
| 5 | Wind/Regen/Windrichtung | **SparkFun Weather Meter Kit SEN-15901** | 2× | [DigiKey](https://www.digikey.de/de/products/detail/sparkfun-electronics/SEN-15901/11570533) oder [Mouser.de](https://www.mouser.de) | Auf Amazon.de/eBay nicht sinnvoll verfügbar (nicht lieferbar bzw. deutlich überteuert). RJ11-Steckkabel. Lieferzeit vor Bestellung prüfen |
| 6 | Blitzsensor (Franklin) | **AS3935** / CJMCU-3935-Modul | 2× (ggf. 1× wenn ein Modul aus einem Vorgängerprojekt wiederverwendet wird) | AliExpress / Amazon.de „CJMCU-3935 AS3935“ | Läuft zuverlässig per **I2C** (abweichend von manchen Herstellerhinweisen, die nur SPI empfehlen — bei diesem Klon in der Praxis bewährt). EMI-empfindlich: sauberes Netzteil, kein Steckbrett, Antenne freihalten |
| 7 | Schallpegel (dBA, kalibriert) | DFRobot Gravity **SEN0232** (teils als „V2.0” verkauft), 30–130 dBA, ±1,5 dB, A-bewertet | 2× | Europäischer Distributor (z.B. Botland, DigiKey) — **nicht** über Amazon.de bestellen | ⚠️ Auf Amazon.de kursiert ein ähnlich benanntes, aber **unkalibriertes** „Analog Sound Sensor”-Modul — das ist **nicht** dasselbe Bauteil. Analog, nicht I2C. Die im Handel oft als „V2.0” gelabelte Variante ist laut [DFRobot-Wiki](https://wiki.dfrobot.com/sen0232/) hard- und softwareseitig identisch zur SEN0232 (kein eigenes Datenblatt, keine geänderte Formel/Pinbelegung) — Doku in diesem Repo gilt unverändert |
| 7b | Wetterschutz Mikrofon | 25mm-Elektroinstallationsrohr + 90°-Bogen, M20 IP68-Kabelverschraubung, Schaumstoff-Windschutz | 2× | Baumarkt (Rohr/Bogen) + Elektrofachhandel (Kabelverschraubung) + Amazon.de (Windschutzschaum) | Details: [enclosure.md](enclosure.md) |

## Gehäuse, Montage, Strom

| # | Bauteil | Menge | Hinweis |
|---|---|---|---|
| 8 | Elektronik-Gehäuse, Polycarbonat/ABS, ~200×120×75mm, IP65 | 2× | Reicht für ESP32 + BME280 + AS3935 + dBA-Modul + Klemmleisten |
| 9 | Kabelverschraubungen IP68, M12/M16/M20/M25 gemischt | 1× Sortiment (deckt beide Geräte) | Je eine Verschraubung für: Wetterkabel-Bündel, DS18B20-Sonde, Stromkabel; fürs Mikrofon separate belüftete Lösung (siehe 7b) |
| 10 | Mast/Rohrhalterung, Aluminium, U-Bolzen | 2× | Windfahne/Anemometer brauchen freien, ungestörten Luftstrom |
| 11 | Stromversorgung: wetterfeste 5V/USB-Zuleitung | 2× | Zuverlässiger als Solar, insbesondere wegen kontinuierlicher Last durch AS3935 + dBA-Sensor |
| 11b | *Alternative:* Solar (6V/1W-Panel + TP4056-Lademodul + 18650-Zelle) | optional | Nur wenn kein Kabelweg möglich — kein Low-Power-Projekt, Akku großzügig dimensionieren |

## Kleinteile

| # | Bauteil | Menge | Hinweis |
|---|---|---|---|
| 12 | Widerstands-Sortiment (u.a. 4,7 kΩ) | 1× Sortiment | Für DS18B20-Pullup |
| 13 | Schraub-/Verbindungsklemmen, Dupont-Kabel, Schrumpfschlauch | 1× Sortiment | Saubere, wartbare Verkabelung im IP65-Gehäuse |
| 14 | Silikagel-Beutel, wiederverwendbar | 1× Packung | Gegen Kondenswasser im geschlossenen Gehäuse |
| 15 | SSD1306 OLED 0,96" I2C (optional) | 2× | Alternative/Ergänzung zum Web-UI — direkt ablesbar ohne Browser, siehe [setup-guide.md](setup-guide.md) |

## Erweiterungssensoren (geplant, 2026-07-19)

Alle nativ von Tasmota unterstützt, kein Custom-Treiber nötig. **Keiner davon gehört ins TFA-Dostmann-Schutzgehäuse** (Punkt 3b) — das ist speziell fürs Blocken von Sonne/Regen bei gleichzeitig freier Luftzirkulation für den BME280 gebaut; Sensoren, die selbst freie Sicht zum Himmel brauchen (Licht/UV), würden dort ja genau das verlieren, wovor das Gehäuse schützt.

| # | Bauteil | Modell | Menge | Bezugsquelle | Hinweis |
|---|---|---|---|---|---|
| 16 | Helligkeit (Lux) | **BH1750** I2C-Breakout | 2× | Amazon.de / AZ-Delivery | I2C, teilt sich den bestehenden Bus (GPIO21/22) — braucht freie Sicht zum Himmel, NICHT im Schutzgehäuse (Punkt 3b) montieren |
| 17 | UV-Index | **VEML6070** I2C-Breakout | 2× | Amazon.de / AliExpress | I2C, gleicher Bus — ebenfalls freie Sicht zum Himmel nötig, NICHT im Schutzgehäuse |
| 18 | Feinstaub (PM2,5/PM10) | **PMS5003** oder **PMS7003** | 2× | Amazon.de / AZ-Delivery | UART (2 GPIOs, z.B. GPIO16/17), braucht **eigenes** belüftetes Gehäuse mit Lüfter-Ansaugung — andere Bauform als der BME280-Strahlungsschutz, nicht kombinierbar |
| 19 | Gassensor (Luftqualität) | **MQ135** (bereits vorhanden, 2× im Bestand) | 2× vorhanden | — | Siehe Hinweis unten — braucht 5V + Spannungsteiler, teils drinnen/teils draußen sinnvoll |

### MQ135-Hinweise (2× bereits vorhanden)

⚠️ **MQ135 braucht zwingend Luftaustausch mit der zu messenden Umgebung** — das Sensorelement (beheiztes SnO₂) reagiert chemisch mit der umgebenden Luft. In einem **vollständig geschlossenen** Gehäuse misst er nur die eingeschlossene Luft darin, nicht die Außenluft.

Sinnvolle Aufteilung für die zwei vorhandenen Module:
- **Ein MQ135 im geschlossenen Hauptgehäuse** — hier bewusst *ohne* Außenluftkontakt, als interner Sicherheits-/Ausgasungs-Detektor (erkennt z.B. eine überhitzende Batterie/Verkabelung) — genau dafür ist ein geschlossenes Gehäuse hier richtig, da die Innenraumluft selbst überwacht werden soll
- **Der zweite MQ135 extern** für echte Außenluftqualität — braucht eigenes belüftetes UND wettergeschütztes Gehäuse (Feuchtigkeit/Regen schadet dem Sensorelement dauerhaft, anders als beim BME280 aber ohne dessen einfache "nur Luft, kein Wasser"-Anforderung — MQ-Sensoren vertragen dauerhafte Nässe generell schlecht)

⚠️ **Hardware-Details:**
- Heizer braucht **5V** (nicht 3,3V) — separate 5V-Versorgung, nicht vom ESP32-3,3V-Pin
- Analogausgang kann laut Datenblatt **über 3,3V** ansteigen — zwingend Spannungsteiler vor dem ESP32-ADC-Pin nötig (z.B. 10 kΩ + 15 kΩ), sonst Risiko für den ADC-Eingang
- Kontinuierlicher Heizer-Stromverbrauch **~150–200 mA pro Modul** (2× ≈ 300–400 mA zusätzlich einplanen — Netzteil-Dimensionierung prüfen, kein Low-Power-Sensor)
- **24–48h Einbrennzeit** nötig, bevor Messwerte einigermaßen stabil sind; nach jedem Stromausfall erneut 3–5 Minuten Aufwärmzeit
- Tasmota unterstützt MQ135 nativ über den generischen `ADC`-Gassensor-Typ (`AdcParam` mit `ANALOG_MQ_TYPE`), Kalibrierung gegen bekannte Frischluft nötig
- Grundsätzlich eher als Innenraum-Luftqualitätssensor konzipiert — bei Außeneinsatz (Temperatur-/Feuchte-Schwankungen) mit reduzierter Genauigkeit rechnen

## Warum SparkFun statt MISOL-Fertigsensorik?

Kurzfassung: MISOL-Sets sind für den eigenen Funk-Empfänger gebaut, nicht für direkten GPIO-Anschluss. Details und Alternativwege: [misol-compatibility.md](misol-compatibility.md).

## Quellen

- [SparkFun Weather Meter Kit SEN-15901 Hookup Guide](https://learn.sparkfun.com/tutorials/weather-meter-hookup-guide)
- [Original-Datenblatt Shenzhen Fine Offset Electronics (RJ11-Pinbelegung)](https://cdn.sparkfun.com/assets/d/1/e/0/6/DS-15901-Weather_Meter.pdf) — Quelle für die RJ11-Pin-Tabelle in [wiring.md](wiring.md)
- [DFRobot Gravity SEN0232 Wiki](https://wiki.dfrobot.com/Gravity_Analog_Sound_Level_Meter_SKU_SEN0232)
- [Bosch BME280 Datenblatt](https://www.bosch-sensortec.com/products/environmental-sensors/humidity-sensors-bme280/)
- [AS3935 Datenblatt (AMS/TE)](https://look.ams-osram.com/m/6ff54cea1cf87dc2/original/AS3935-Franklin-Lightning-Sensor-IC.pdf)

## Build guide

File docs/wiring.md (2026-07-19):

# Verkabelungskonzept

## Pin-Belegung (ESP32-WROOM-32U DevKitC V4)

| Funktion | Modulfunktion | GPIO | Typ | Hinweis |
|---|---|---|---|---|
| BME280 SDA | Thermo-/Hygro-/Barosensor (Temp/Feuchte/Druck) | 21 | I2C | gemeinsamer Bus mit AS3935 |
| BME280 SCL | Thermo-/Hygro-/Barosensor (Temp/Feuchte/Druck) | 22 | I2C | gemeinsamer Bus mit AS3935 |
| AS3935 SDA | Blitzsensor (Franklin) | 21 | I2C | gemeinsamer Bus mit BME280 |
| AS3935 SCL | Blitzsensor (Franklin) | 22 | I2C | gemeinsamer Bus mit BME280 |
| AS3935 IRQ | Blitzsensor (Franklin) | 25 | Interrupt | Blitzereignis-Trigger |
| DS18B20 | Thermosensor (wasserdicht, Zusatzmessstelle) | 4 | 1-Wire | 4,7 kΩ Pull-up gegen 3,3V |
| Regenmesser (SEN-15901) | Niederschlagsmenge | 27 | Interrupt (Counter1) | Reed-Kontakt, Kippwaage |
| Anemometer (SEN-15901) | Windgeschwindigkeit | 14 | Interrupt (Counter2) | Reed-Kontakt |
| Windfahne (SEN-15901) | Windrichtung | 34 | ADC1 | Spannungsteiler/Potentiometer |
| dBA-Sensor (SEN0232) | Schallpegel (Lautstärke, A-bewertet) | 35 | ADC1 | analoger Ausgang, 0,6–2,6V |

**Warum genau diese Pins:**
- I2C-Bus (BME280 + AS3935) bewusst auf 21/22 — Tasmota-Standardbelegung, spart Konfigurationsaufwand
- Alle ADC-Pins bewusst auf **ADC1** (GPIO32–39) — ADC2 ist bei aktivem WLAN auf dem ESP32 nicht zuverlässig nutzbar
- Rain/Wind auf getrennte Interrupt-fähige GPIOs, da beide unabhängig voneinander und potenziell gleichzeitig Pulse liefern

## Pin-Position am ESP32-WROOM-32U DevKitC V4 (Board-Beschriftung)

Der 38-Pin-DevKitC-V4-Formfaktor (Espressif-Referenzdesign, auch von den meisten Klonen inkl. 32U/32UE-Antennenvariante 1:1 übernommen) hat zwei Header-Reihen. Die aufgedruckte Zahl neben "IO"/"GPIO" **ist** die GPIO-Nummer — falls auf deinem Board nur die nackte Zahl ohne "IO"-Präfix steht, bezeichnet sie trotzdem denselben GPIO. Position wird von der 3V3-/5V-Ecke aus gezählt (siehe Pin 1/19 je Reihe):

**Linke Reihe (J2), von oben nach unten:**

| Pos. | Aufdruck | GPIO | Im Projekt verwendet |
|---|---|---|---|
| 1 | 3V3 | – | 3,3V-Versorgung (mehrfach genutzt) |
| 2 | EN | – | |
| 3 | VP | GPIO36 | |
| 4 | VN | GPIO39 | |
| 5 | IO34 | **GPIO34** | ✅ Windfahne (ADC) |
| 6 | IO35 | **GPIO35** | ✅ dBA-Sensor SEN0232 (ADC) |
| 7 | IO32 | **GPIO32** | ✅ „Option A3" — virtueller uDisplay-Marker fürs OLED, keine physische Funktion (siehe [tasmota-config.md](tasmota-config.md) Abschnitt 6) |
| 8 | IO33 | GPIO33 | |
| 9 | IO25 | **GPIO25** | ✅ AS3935 IRQ |
| 10 | IO26 | GPIO26 | |
| 11 | IO27 | **GPIO27** | ✅ Regenmesser (Counter1) |
| 12 | IO14 | **GPIO14** | ✅ Anemometer (Counter2) |
| 13 | IO12 | GPIO12 | ⚠️ Strapping-Pin, beim Booten nicht belasten |
| 14 | GND | – | |
| 15 | IO13 | GPIO13 | |
| 16 | D2 | GPIO9 | ⚠️ intern für Flash-SPI, nicht verwenden |
| 17 | D3 | GPIO10 | ⚠️ intern für Flash-SPI, nicht verwenden |
| 18 | CMD | GPIO11 | ⚠️ intern für Flash-SPI, nicht verwenden |
| 19 | 5V | – | |

**Rechte Reihe (J3), von oben nach unten:**

| Pos. | Aufdruck | GPIO | Im Projekt verwendet |
|---|---|---|---|
| 1 | GND | – | |
| 2 | IO23 | GPIO23 | |
| 3 | IO22 | **GPIO22** | ✅ I2C SCL (BME280 + AS3935) |
| 4 | TX | GPIO1 | ⚠️ Serial-Konsole, beim Flashen/Debuggen belegt |
| 5 | RX | GPIO3 | ⚠️ Serial-Konsole, beim Flashen/Debuggen belegt |
| 6 | IO21 | **GPIO21** | ✅ I2C SDA (BME280 + AS3935) |
| 7 | GND | – | |
| 8 | IO19 | GPIO19 | |
| 9 | IO18 | GPIO18 | |
| 10 | IO5 | GPIO5 | ⚠️ Strapping-Pin |
| 11 | IO17 | GPIO17 | |
| 12 | IO16 | GPIO16 | |
| 13 | IO4 | **GPIO4** | ✅ DS18B20 (1-Wire) |
| 14 | IO0 | GPIO0 | ⚠️ Boot-Strapping-Pin, nicht belegen |
| 15 | IO2 | **GPIO2** | ✅ „LedLink" — Status-LED (WLAN/MQTT-Aktivität), optional. ⚠️ zusätzlich Strapping-Pin, aber unproblematisch (siehe [tasmota-config.md](tasmota-config.md) Abschnitt 7) |
| 16 | IO15 | GPIO15 | ⚠️ Strapping-Pin |
| 17 | D1 | GPIO8 | ⚠️ intern für Flash-SPI, nicht verwenden |
| 18 | D0 | GPIO7 | ⚠️ intern für Flash-SPI, nicht verwenden |
| 19 | CLK | GPIO6 | ⚠️ intern für Flash-SPI, nicht verwenden |

**Alle 9 im Projekt genutzten GPIOs (21, 22, 25, 4, 27, 14, 34, 35, 32) liegen auf normalen, unkritischen I/O-Pins — keine Kollision mit Boot-Strapping- oder internem Flash-SPI-Pin.** Quelle: [Espressif ESP32-DevKitC V4 User Guide](https://docs.espressif.com/projects/esp-dev-kits/en/latest/esp32/esp32-devkitc/user_guide.html).

## Physische Pin-Zuordnung fürs Prep-Board

Diese Tabelle listet **jeden physischen Pin/Draht** der Bauteile und wohin er auf dem Prep-Board bzw. ESP32 gehört — als direkte Bau-Anleitung, unabhängig davon ob per RJ11-Stecker oder direkt verlötet.

| Bauteil | Modulfunktion | Bauteil-Pin/Ader | Ziel | Hinweis |
|---|---|---|---|---|
| BME280-Breakout | Thermo-/Hygro-/Barosensor | VCC | 3,3V | |
| BME280-Breakout | Thermo-/Hygro-/Barosensor | GND | GND | |
| BME280-Breakout | Thermo-/Hygro-/Barosensor | SDA | GPIO21 | gemeinsamer I2C-Bus mit AS3935 |
| BME280-Breakout | Thermo-/Hygro-/Barosensor | SCL | GPIO22 | gemeinsamer I2C-Bus mit AS3935 |
| AS3935-Modul | Blitzsensor (Franklin) | VCC | 3,3V | |
| AS3935-Modul | Blitzsensor (Franklin) | GND | GND | |
| AS3935-Modul | Blitzsensor (Franklin) | SDA (**auf CJMCU-3935 als „MOSI" beschriftet**, kein SDA-Aufdruck) | GPIO21 | gemeinsamer I2C-Bus mit BME280 |
| AS3935-Modul | Blitzsensor (Franklin) | SCL | GPIO22 | gemeinsamer I2C-Bus mit BME280 |
| AS3935-Modul | Blitzsensor (Franklin) | IRQ | GPIO25 | |
| AS3935-Modul | Blitzsensor (Franklin) | CS | GND | nur falls Platine SPI-Pins herausführt (bei I2C-Betrieb ungenutzt, aber nicht offen lassen) |
| AS3935-Modul | Blitzsensor (Franklin) | MISO | GND | s.o. |
| AS3935-Modul | Blitzsensor (Franklin) | SI | 3,3V | s.o. |
| AS3935-Modul | Blitzsensor (Franklin) | A0 / A1 (falls auf der Platine vorhanden) | 3,3V | setzt I2C-Adresse auf `0x03` (von Tasmota/Doku so erwartet) |
| DS18B20-Sonde | Thermosensor (wasserdicht, Zusatzmessstelle) | VCC (meist rot) | 3,3V | |
| DS18B20-Sonde | Thermosensor (wasserdicht, Zusatzmessstelle) | GND (meist schwarz) | GND | |
| DS18B20-Sonde | Thermosensor (wasserdicht, Zusatzmessstelle) | DATA (meist gelb) | GPIO4 | + 4,7 kΩ Pull-up zwischen DATA und 3,3V |
| SEN0232 (dBA) | Schallpegel (Lautstärke, A-bewertet) | VCC | 3,3V/5V (Modulaufdruck prüfen) | |
| SEN0232 (dBA) | Schallpegel (Lautstärke, A-bewertet) | GND | GND | |
| SEN0232 (dBA) | Schallpegel (Lautstärke, A-bewertet) | AOUT | GPIO35 | |
| SSD1306-OLED (optional) | Anzeige (Live-Werte am Gehäuse) | VCC | 3,3V | |
| SSD1306-OLED (optional) | Anzeige (Live-Werte am Gehäuse) | GND | GND | |
| SSD1306-OLED (optional) | Anzeige (Live-Werte am Gehäuse) | SDA | GPIO21 | dritter Teilnehmer am selben I2C-Bus (BME280+AS3935) |
| SSD1306-OLED (optional) | Anzeige (Live-Werte am Gehäuse) | SCL | GPIO22 | dritter Teilnehmer am selben I2C-Bus (BME280+AS3935) |
| SEN-15901 Regenmesser | Niederschlagsmenge | Ader A (Reed-Kontakt, polaritätsfrei) | GND | RJ11-Pin: siehe Tabelle unten |
| SEN-15901 Regenmesser | Niederschlagsmenge | Ader B (Reed-Kontakt, polaritätsfrei) | GPIO27 | ESP32-interner Pull-up i.d.R. ausreichend |
| SEN-15901 Anemometer | Windgeschwindigkeit | Ader A (Reed-Kontakt, polaritätsfrei) | GND | RJ11-Pin: siehe Tabelle unten |
| SEN-15901 Anemometer | Windgeschwindigkeit | Ader B (Reed-Kontakt, polaritätsfrei) | GPIO14 | ESP32-interner Pull-up i.d.R. ausreichend |
| SEN-15901 Windfahne | Windrichtung | Ader A (variabler R, polaritätsfrei) | GND | RJ11-Pin: siehe Tabelle unten |
| SEN-15901 Windfahne | Windrichtung | Ader B (variabler R, polaritätsfrei) | Spannungsteiler-Knoten → GPIO34 | zusätzlich fester Widerstand (empfohlen 10 kΩ, 1%) zwischen 3,3V und diesem Knoten nötig |

### RJ11-Pinbelegung SEN-15901 (verifiziert gegen Fine-Offset-Original-Datenblatt)

Der SEN-15901 basiert, wie in [misol-compatibility.md](misol-compatibility.md) bereits hergeleitet, auf Fine-Offset-Sensorik. Das Original-Datenblatt des Herstellers (Shenzhen Fine Offset Electronics, `DS-15901-Weather_Meter.pdf`) gibt die Pinbelegung explizit an:

| Sensor | RJ11-Kabel | Belegte Pins | Funktion |
|---|---|---|---|
| Regenmesser | eigenes, separates RJ11-Kabel | die **beiden mittleren** Kontakte | Reed-Kontakt (Schalter, kein Polaritätsbezug) |
| Anemometer | **gemeinsames** RJ11-Kabel mit Windfahne (kurzes Verbindungskabel am Sensorarm) | Pins **2 + 3** (innere Adern) | Reed-Kontakt (Schalter) |
| Windfahne | **gemeinsames** RJ11-Kabel mit Anemometer | Pins **1 + 4** (äußere Adern) | 8-Schalter/Widerstands-Netzwerk, 891 Ω–120 kΩ je nach Richtung |

> Das Datenblatt nennt keine Aderfarben (die sind laut Community-Berichten nicht über alle Fine-Offset-Klone hinweg einheitlich) — deshalb im Zweifel per Multimeter-Durchgangsprüfung gegen die Pin-Nummern verifizieren, bevor final verlötet wird.

### RJ11 entfernen und direkt aufs Prep-Board verbinden

Da alle drei SEN-15901-Sensoren reine Schalter bzw. ein reines Widerstandsnetzwerk sind (**keine Polarität**, keine aktive Elektronik), ist das Entfernen der RJ11-Stecker unkritisch:

1. RJ11-Stecker abschneiden, Kabel ca. 1–2 cm abisolieren
2. Mit Multimeter im Durchgangs-/Widerstandsmodus **die beiden Adern von Regenmesser und Anemometer/Windfahne-Gemeinschaftskabel eindeutig paaren** — wichtig ist nur, dass die beiden Adern der Windfahne nicht mit denen des Anemometers vertauscht werden (beide stecken im selben Kabel)
3. Windfahne: Probe drehen und Widerstand zwischen ihren beiden Adern messen (sollte je nach Richtung zwischen ~688 Ω und ~120 kΩ liegen, siehe Widerstandstabelle in [tasmota-config.md](tasmota-config.md)) — damit ist die Zuordnung zweifelsfrei bestätigt
4. Anemometer/Regenmesser: Adern einfach durchklingeln (Kontakt schließt beim Drehen der Becher bzw. beim Kippen der Wippe) — Polarität egal, eine Ader auf GND, andere auf den jeweiligen GPIO
5. Alle Verbindungen auf dem Prep-Board mit Schraub-/Verbindungsklemmen (siehe [bom.md](bom.md) Punkt 13) statt direkt verlöten — erleichtert spätere Fehlersuche/Austausch

Alternative ohne Auftrennen: RJ11-Buchsen (6P4C) aufs Prep-Board löten/kleben und die Original-Stecker einfach einstecken — spart das Auftrennen, braucht aber zusätzliche Buchsenteile (nicht in der BOM enthalten).

## Blockschaltbild

```mermaid
graph LR
    ESP32["ESP32-WROOM-32U<br/>DevKitC V4"]

    subgraph I2C-Bus [I2C-Bus – GPIO21/22]
        BME280["BME280<br/>Temp / Feuchte / Druck"]
        AS3935["AS3935<br/>Blitzsensor"]
    end

    DS18B20["DS18B20<br/>wasserdichte Temp-Sonde"]
    RAIN["Regenmesser<br/>SEN-15901"]
    ANEMO["Anemometer<br/>SEN-15901"]
    VANE["Windfahne<br/>SEN-15901"]
    DBA["SEN0232<br/>dBA-Sensor"]
    ANT["Externe WLAN-Antenne<br/>via U.FL"]

    ESP32 -->|SDA/SCL GPIO21/22| BME280
    ESP32 -->|SDA/SCL GPIO21/22| AS3935
    ESP32 -->|IRQ GPIO25| AS3935
    ESP32 -->|1-Wire GPIO4| DS18B20
    ESP32 -->|Interrupt GPIO27| RAIN
    ESP32 -->|Interrupt GPIO14| ANEMO
    ESP32 -->|ADC1 GPIO34| VANE
    ESP32 -->|ADC1 GPIO35| DBA
    ESP32 -.->|U.FL/IPEX| ANT
```

## Stromversorgung

```mermaid
graph TD
    MAINS["5V-Zuleitung<br/>(wetterfestes Kabel)"]
    USB["USB-Netzteil / USB-Buchse<br/>im Gehäuse"]
    ESP32V["ESP32 5V-Pin"]
    LDO["Onboard-LDO<br/>(auf DevKitC-Board)"]
    V33["3,3V-Schiene"]

    MAINS --> USB --> ESP32V --> LDO --> V33
    V33 --> BME280V["BME280"]
    V33 --> AS3935V["AS3935"]
    V33 --> DS18B20V["DS18B20"]
    V33 --> DBAV["SEN0232"]
```

**Hinweis Stromversorgung:** AS3935 und SEN0232 ziehen kontinuierlich Strom (kein reines Low-Power-Projekt). Bei der Solar-Alternative (siehe [bom.md](bom.md)) den Akku entsprechend großzügig dimensionieren.

⚠️ **Kein Spannungsteiler zur Stromversorgung verwenden!** Ein Widerstandsteiler funktioniert nur für Signale mit vernachlässigbarem Strom (wie bei der Windfahne), nicht zum Versorgen des ESP32 selbst — der zieht stark schwankenden Strom (WLAN-Sendespitzen bis 300–500 mA), ein Spannungsteiler würde dabei einbrechen (Reset-Schleifen). Der 5V-Pin des DevKitC-Boards hat bereits einen eingebauten LDO-Regler auf 3,3V — 5V-Zuleitung einfach direkt an den 5V-Pin (oder über USB).

⚠️ **Fallstrick, live gefunden (2026-07-18):** Manche moderne USB-C-Schnelllade-Netzteile (PD/QC) liefern **ganz ohne Spannung**, solange keine Aushandlung mit einer "intelligenten" Gegenstelle stattfindet — ein einfaches ESP32-Board handelt das oft nicht aus, das Board bleibt dann komplett dunkel (LED, OLED, alle Sensor-LEDs aus). Fix: einfaches "dummes" 5V/1–2A-USB-Netzteil ohne Fast-Charge/PD-Funktion verwenden (z.B. altes Handy-Ladegerät, Powerbank).

## Verkabelungs-Reihenfolge (empfohlen)

1. Erst auf dem Breadboard alle Sensoren einzeln gegen den ESP32 testen (I2C-Scan für BME280/AS3935, `OneWire`-Scan für DS18B20, ADC-Rohwerte für Windfahne/dBA), **bevor** final ins Gehäuse verlötet/verklemmt wird
2. I2C-Bus zuerst (BME280 + AS3935) — beide Adressen per `I2CScan`-Kommando in Tasmota gegenprüfen (AS3935-Klone laufen oft auf Adresse `0x03`)
3. Danach 1-Wire (DS18B20), dann die beiden Interrupt-Leitungen (Regen/Wind), zuletzt die ADC-Leitungen (Windfahne/dBA)
4. Erst nach erfolgreichem Einzeltest final ins IP65-Gehäuse verkabeln (Zugentlastung an jeder Kabelverschraubung nicht vergessen)

## Fritzing-Projektdatei

[`fritzing/IceWeatherstation.fzz`](fritzing/IceWeatherstation.fzz) — Breadboard-Verdrahtungsplan für die komplette Station (ESP32 + BME280 + AS3935 + DS18B20 + Regenmesser/Anemometer/Windfahne + dBA-Sensor + OLED + Status-LED), programmatisch aus dieser Pin-Tabelle generiert (2026-07-19).

⚠️ **Bekannte Einschränkungen (Hand-Erzeugung ohne Fritzing-GUI zur visuellen Prüfung):**
- **ESP32-WROOM-32U DevKitC V4:** echtes, community-gepflegtes Fritzing-Part ([Fritzing-Forum](https://forum.fritzing.org/t/esp32-devkitc-v4-ready/17213)), Pin-für-Pin gegen die Tabelle oben verifiziert (alle 9 im Projekt genutzten GPIOs stimmen exakt überein) — in der `.fzz` eingebettet, kein separater Download nötig.
- **BME280, DS18B20:** echte, passende Fritzing-Core-Parts (SparkFun-Breakout bzw. DS18B20-Sonde).
- **AS3935, SEN0232 (dBA), SSD1306-OLED:** Für diese drei existiert **kein** exaktes Fritzing-Part — im Bild durch elektrisch/pin-technisch passende Platzhalter-Footprints ersetzt (MPU6050/GY-521 fürs AS3935 wegen INT+I2C-Pins, TEMT6000-Breakout fürs dBA-Modul wegen VCC/GND/Signal, Grove-OLED fürs SSD1306 wegen GND/VCC/SDA/SCL) — Beschriftung im Bauteil-Titel macht das jeweils kenntlich. Optik weicht daher vom realen Bauteil ab, die Pin-Zuordnung/Verdrahtung selbst ist korrekt.
- **Regenmesser/Anemometer:** als Reed-Kontakt-Bauteil dargestellt, **Windfahne** als variabler Widerstand (2 der 3 Pins genutzt) — beides funktional exakt, wie im SEN-15901 auch tatsächlich verbaut.
- Die Netzliste (welcher Pin mit welchem verbunden ist) wurde direkt aus der obigen Tabelle erzeugt. **Update 2026-07-19 (1):** Pin-Positionen direkt aus den SVG-Koordinaten jedes Bauteils berechnet (Transformationskette pro Connector aufgelöst, korrekt für Rotation/Skalierung/mm-vs-Zoll) — Wires liegen exakt auf den Anschluss-Pins.
- **Update 2026-07-19 (2), kreuzungsfreies Routing:** Statt jedes Bauteil direkt sternförmig mit dem ESP32 zu verbinden (was zwangsläufig zu einem Wire-Gewirr an einem Punkt führt, siehe Screenshot-Beispiel BME280), sind gemeinsame Signale jetzt als **Bus-Ketten** verlegt: 3,3V/GND/SDA/SCL laufen als eine Leitung nacheinander durch alle Bauteile, die sie brauchen (ESP32 → BME280 → AS3935 → OLED usw.), statt N-mal einzeln zum ESP32 zurück. Die vier Sammelleitungen (3,3V, SDA, SCL, AS3935-INT) sind zusätzlich als eigene, klar getrennte "Lanes" **oberhalb** der gesamten Schaltung verlegt (jede auf eigener Höhe mit kleinem X-Versatz), beide GND-Ketten (links/rechts) laufen unterhalb — dadurch kreuzt keine Leitung eine andere. Bauteile sind passend zur Pin-Reihenfolge am ESP32 (links: GPIO34/35/27/14+GND, rechts: SDA/SCL/GPIO4/GPIO2+GND) in zwei Spalten links/rechts vom ESP32 angeordnet. Einzige technisch unvermeidbare Ausnahme: `AS3935 INT` muss auf `GPIO25` (linke Pinreihe), obwohl AS3935 selbst wegen des I2C-Busses rechts sitzt — dafür bekommt genau diese eine Leitung ihre eigene, höchste Lane, damit sie nichts anderes kreuzt.
- **Update 2026-07-19 (3), echte Fritzing-Verifikation + Schematic/Code:** Ab hier nicht mehr blind gebaut — Fritzing 1.0.1 + Parts-Datenbank lokal installiert und die Datei per Xvfb (virtueller X-Server) tatsächlich in der echten App geöffnet und screenshot-geprüft, statt nur die XML-Struktur zu validieren. Dabei zwei echte Fehler gefunden und live gefixt: (a) eine verbliebene Kreuzung zwischen Windfahne, ihrem Spannungsteiler-Widerstand und dem SEN0232 (Widerstand saß versetzt statt in der Signalspalte); (b) bestätigt, dass Fritzing die eigentliche Verkabelung **pro Ansicht getrennt** speichert — Verbindungen aus der Breadboard-Ansicht erscheinen NICHT automatisch als Ratsnest in Schematic/PCB (mehrfach getestet, auch mit gespiegelten `connects`-Einträgen — hat nicht funktioniert). **Schematic-Ansicht** zeigt daher alle 13 Bauteile mit korrekten Schaltzeichen in sauberem Raster, aber **ohne** Verbindungslinien — die müssten in Fritzing selbst nachgezogen werden (Status "No connections to route" beim Öffnen ist erwartet, kein Fehler). Gleiches gilt für die PCB-Ansicht (nur Footprint-Platzierung, keine Traces).
- **Code-Tab befüllt:** Fritzings eingebauter "Code"-Tab (normalerweise für Arduino-Sketches) enthält jetzt zwei Dateien als Referenz: `IceWeatherstation_TasmotaBacklog.ino` (= `firmware/config/backlog.txt`, die Tasmota-Konsolen-Befehle) und `IceWeatherstation_autoexec.ino` (= `firmware/berry/autoexec.be`, das Dashboard-Skript) — beide sind **kein** kompilierbarer Arduino-Code, nur mit `.ino`-Endung gespeichert, weil Fritzings Code-Tab keine andere Dateiendung zulässt. Einbettung live verifiziert: beim Öffnen in einer frischen Fritzing-Instanz (andere Prozess-ID, simuliert einen fremden Rechner) zeigt die Statuszeile korrekt „File … was restored from the .fzz file" — die Dateien sind also wirklich im `.fzz` eingebettet, nicht nur über einen lokalen Pfad verlinkt.
- ⚠️ **Fallstrick, live gefunden:** Öffnet man die `.fzz` in Fritzing und speichert dort einmal ab, entfernt Fritzing das eingebettete ESP32-Bauteil automatisch aus der Zip-Datei (es wird beim ersten Laden in Fritzings eigene lokale Parts-Datenbank importiert und gilt danach als "lokal vorhanden", nicht mehr bundle-pflichtig) — das **zerstört die Portabilität** auf einem dritten Rechner. Für Bearbeitungen daher: entweder das ESP32-Bauteil einmal dauerhaft in die eigene Fritzing-Installation importieren (dann ist es kein Problem mehr), oder nach jeder Bearbeitung prüfen, ob `part.ESP32_DevKitc_V4_1.fzp` + die 3 zugehörigen SVGs noch in der `.fzz` (als ZIP) enthalten sind.

Weiter mit: [tasmota-config.md](tasmota-config.md) für die Firmware-Seite dieser Verkabelung.

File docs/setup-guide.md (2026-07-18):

# Setup-Guide: Aufbau, Installation, Konfiguration, Integration

Schritt-für-Schritt-Anleitung für den kompletten Weg von den einzelnen Bauteilen bis zur fertig eingebundenen Wetterstation — **verifiziert am ersten real aufgebauten Gerät (Stand 2026-07-19)**. Gilt für beide Geräte — beim zweiten Gerät (ohne Home Assistant beim Empfänger) Schritt 11 überspringen.

> Platzhalter in dieser Anleitung: `<WIFI_SSID>` / `<WIFI_PASSWORT>` / `<MQTT_BROKER>` / `<MQTT_USER>` / `<MQTT_PASSWORT>` — bewusst nicht mit echten Zugangsdaten befüllt, durch eigene Werte ersetzen.

```mermaid
flowchart TD
    S1["1. Vorbereitung<br/>Custom-Firmware bauen/laden"]
    S2["2. Erstes Flashen (USB)"]
    S3["3. WLAN-Grundkonfiguration"]
    S4["4. GPIO-Konfiguration"]
    S5["5. Sensoren einzeln verkabeln + testen"]
    S6["6. OLED-Display einrichten"]
    S7["7. Berry-Skript hochladen"]
    S8["8. Status-LED (optional)"]
    S9["9. Nachtruhe + Zeitzone"]
    S10["10. Web-UI-Labels (optional)"]
    S11["11. MQTT + Home Assistant"]
    S12["12. Gehäuse-/Mast-Montage"]
    S13["13. Kalibrierung Windfahne/dBA"]

    S1 --> S2 --> S3 --> S4 --> S5 --> S6 --> S7 --> S8 --> S9 --> S10 --> S11 --> S12 --> S13
```

## 1. Vorbereitung

⚠️ **Wichtigste Erkenntnis aus dem realen Aufbau:** Ein Standard-Tasmota-Release reicht **nicht**, sobald sowohl AS3935 (Blitzsensor) als auch das OLED-Display gleichzeitig genutzt werden sollen — kein offizielles ESP32-Binary kombiniert beides (Details: [firmware/README.md](../firmware/README.md)). Zwei Optionen:

- **Fertig kompilierte Binaries verwenden** (schneller): [`firmware/custom-build/iceweatherstation-tasmota32.factory.bin`](../firmware/custom-build/iceweatherstation-tasmota32.factory.bin) direkt herunterladen
- **Selbst bauen** (empfohlen bei neuerer Tasmota-Version): PlatformIO-Build mit [`firmware/custom-build/user_config_override.h`](../firmware/custom-build/user_config_override.h) + optional [`friendly-labels.patch`](../firmware/custom-build/friendly-labels.patch), siehe [firmware/README.md](../firmware/README.md) für die genauen Befehle

Weiteres Werkzeug: Lötkolben, Multimeter, Wasserwaage (Regenmesser-Montage), Schraubendreher-Set, 4,7 kΩ + 10 kΩ Widerstände (DS18B20-Pullup bzw. Windfahnen-Spannungsteiler), einfaches "dummes" USB-Netzteil (**kein** Fast-Charge/PD-Ladegerät, siehe Warnung in Schritt 12).

Diese Doku griffbereit: [bom.md](bom.md) (Teile), [wiring.md](wiring.md) (Pins), [tasmota-config.md](tasmota-config.md) (Befehlsreferenz + alle live gefundenen Fallstricke), [firmware/config/backlog.txt](../firmware/config/backlog.txt) (fertiger Konsolen-Befehlssatz).

## 2. Erstes Flashen (USB)

```bash
esptool.py --chip esp32 --port /dev/ttyUSB0 --baud 460800 write_flash -z 0x0 iceweatherstation-tasmota32.factory.bin
```

Alternativ [Tasmotizer](https://github.com/tasmota/tasmotizer) (GUI), nimmt dieselbe `.factory.bin`-Datei. Nach dem ersten Boot öffnet der ESP32 einen eigenen Access Point (`tasmota-XXXX`).

## 3. WLAN-Grundkonfiguration

Über den ESP32-eigenen Access Point verbinden, dann:

```
Backlog SSID1 <WIFI_SSID>;Password1 <WIFI_PASSWORT>;WebServer 2
```

Danach ist das Gerät im eigenen WLAN unter seiner IP bzw. `http://tasmota-XXXX.local/` erreichbar.

⚠️ **Fallstrick:** Tasmota ≥15 blockt `/cm`, `/cn`, `/md` (Kommando-API, Konfigurationsseiten) standardmäßig ohne WebPassword, wenn der HTTP-Request keinen Referer-Header mitschickt (z.B. bei `curl`) — nur die reine Root-Seite `/` bleibt davon unberührt. Für Skript-/Automatisierungs-Zugriff per `curl` einen Referer-Header mitschicken: `curl -e "http://<ip>/" "http://<ip>/cm?cmnd=..."`. Alternativ dauerhaft `SetOption128 1` setzen (weniger sicher) oder ein WebPassword vergeben (empfohlen).

## 4. GPIO-Konfiguration

Empfohlen über die Web-UI (*Konfiguration → Konfiguriere Modul*) — verhindert falsch nummerierte GPIO-Komponenten-IDs, die sich zwischen Tasmota-Versionen ändern können. Alternativ per Konsole (praktisch fürs Erstflashen ohne WLAN-UI), mit den für dieses Projekt verifizierten Werten (gültig für Tasmota 15.5.0(3.3.8) — bei anderer Version per `GPIO<pin>` gegenprüfen, siehe [tasmota-config.md](tasmota-config.md) Abschnitt 2):

```
Backlog GPIO21 640;GPIO22 608;GPIO25 4672;GPIO4 1312;GPIO27 352;GPIO14 353;GPIO34 4704;GPIO35 4864
```

Zuordnung (siehe [wiring.md](wiring.md) für die physische Pin-Tabelle):

| GPIO | Rolle | Bauteil |
|---|---|---|
| 21 | I2C SDA1 | BME280 + AS3935 |
| 22 | I2C SCL1 | BME280 + AS3935 |
| 25 | AS3935 (IRQ) | AS3935 |
| 4 | DS18x201 | DS18B20 |
| 27 | Counter1 | Regenmesser |
| 14 | Counter2 | Anemometer |
| 34 | ADC Input1 | Windfahne |
| 35 | ADC Range1 | dBA-Sensor (SEN0232) |

Danach `FriendlyName1` sinnvoll setzen (z.B. „Wetterstation Schuppen“) und neustarten (`Restart 1`).

## 5. Sensoren einzeln verkabeln und testen

**Nacheinander** anschließen und nach jedem Sensor sofort prüfen — spart bei einem Fehler das Durchsuchen mehrerer gleichzeitig neuer Verkabelungen. Reihenfolge, wie am realen Gerät durchgeführt:

1. **DS18B20**: VCC/GND/DATA (siehe wiring.md) + **zwingend 4,7 kΩ Pull-up zwischen DATA und 3,3V** (ohne Pull-up bleibt der Sensor unsichtbar — kein Fehler, sondern erwartetes Verhalten eines offenen 1-Wire-Bus). Prüfen: `Status 10` → `DS18B20:{"Temperature":...}` sollte erscheinen.
2. **dBA-Sensor (SEN0232)**: DFRobot-Gravity-Kabelfarben Schwarz=GND, Rot=VCC(3,3-5V), Blau=Signal. Kalibrieren:
   ```
   AdcParam2 6,745,3226,30,130
   ```
   ⚠️ **Zwei Fallstricke:** (1) Die Kanalnummer in `AdcParam<N>` zählt nach **GPIO-Reihenfolge**, nicht nach GPIO-Nummer — bei Windfahne(34)+dBA(35) ist dBA Kanal **2**, nicht 1 (Echo-Array erste Zahl = tatsächliche GPIO-Nummer, guter Sanity-Check). (2) Die Schwellwerte sind kein Millivolt, sondern ein 0–4095-Pseudo-ADC-Wert (`mV/3300×4095`). Details: [tasmota-config.md](tasmota-config.md) Abschnitt 3.
3. **Windfahne**: Spannungsteiler mit **festem 10 kΩ-Widerstand zwischen 3,3V und GPIO34**, Windfahne selbst zwischen GPIO34-Knoten und GND. Prüfen: `Status 10` → `ANALOG:{"A1":...}`. Falls `A1` trotz korrektem GPIO nicht erscheint: `AdcParam1 6,0,0,0,0` setzen (Fallstrick: Parameter 4 ≠ 0 unterdrückt die Anzeige komplett, Details [tasmota-config.md](tasmota-config.md) Abschnitt 4).
4. **Regenmesser + Anemometer** (SEN-15901, RJ11-Pinbelegung siehe [wiring.md](wiring.md)): `CounterDebounce 10` setzen (sonst massives Kontaktprellen/Fehlzählungen). Testpulse: Reed-Kontakte per Hand kurz schließen bzw. Anemometer drehen, `COUNTER:{"C1":...,"C2":...}` sollte hochzählen.
5. **AS3935**: Auf dem CJMCU-3935-Board heißt die SDA-Leitung **„MOSI"** (kein SDA-Aufdruck), SI→3,3V, CS+MISO→GND, ggf. A0/A1→3,3V. `I2CScan` sollte `0x03` finden. Danach:
   ```
   Backlog AS3935setgain Outdoors;AS3935autonf 1;AS3935disturber 1;AS3935autodisturber 1
   ```
6. **BME280**: I2C, gemeinsamer Bus mit AS3935. `I2CScan` sollte zusätzlich `0x76`/`0x77` finden.

## 6. OLED-Display einrichten

Der klassische SSD1306-Treiber wurde in aktuellem Tasmota entfernt — das neue **uDisplay**-System braucht `DisplayModel 17` + einen virtuellen GPIO-Marker + einen Display-Descriptor. Vollständige Befehlsfolge: [tasmota-config.md](tasmota-config.md) Abschnitt 6.

## 7. Berry-Skript hochladen

*Konsole → Verwalte Dateisystem* → Datei-Upload: [firmware/berry/autoexec.be](../firmware/berry/autoexec.be) (Name **muss** exakt `autoexec.be` sein). Danach `Restart 1`. Das Skript übernimmt: Windrichtung-Umrechnung, 24h-Regenmenge, Windgeschwindigkeit, OLED-Dashboard (alle 10s), Nachtruhe-Zeitplan, sowie das Einspeisen eigener Werte in die MQTT-Telemetrie (`json_append()`).

Boot-Log auf Fehler prüfen: `BRY: Successfully loaded 'autoexec.be'` (keine `attribute_error`/`compile error`-Zeile).

## 8. Status-LED (optional)

Externe LED + 330Ω-Vorwiderstand an einem freien GPIO, z.B. GPIO2 (GPIO32 ist bereits durch den uDisplay-Marker belegt, siehe Schritt 6):

```
GPIO2 544      // "LedLink"
LedState 7     // GPIO-Rolle allein reicht NICHT, LedState zusätzlich nötig!
```

Verhalten: LED blinkt rhythmisch bei jeder MQTT-Aktivität. Details + Common-Kathode-RGB-Verkabelung (z.B. Elegoo-Kit): [tasmota-config.md](tasmota-config.md) Abschnitt 7.

## 9. Nachtruhe + Zeitzone

Zeitzone **zwingend vor** der Nachtruhe-Kontrolle prüfen — sonst rechnet die 22-08-Uhr-Logik mit falscher Lokalzeit:

```
Timezone 99
```

`Status 7` prüfen: `Local`-Zeit muss der echten Sommer-/Winterzeit entsprechen. Die Nachtruhe selbst (Display+LED 22:00–08:00 aus) ist bereits im Berry-Skript (Schritt 7) enthalten, per `QUIET_START_HOUR`/`QUIET_END_HOUR` einstellbar. Details + NTP-Boot-Race-Fallstrick: [tasmota-config.md](tasmota-config.md) Abschnitt 8+9.

## 10. Web-UI-Labels (optional)

„Counter 1“/„Analog1“/„ADC1 Range“ lassen sich nicht per Einstellung umbenennen (Tasmota-Einschränkung) — nur per Source-Patch im Custom-Build lösbar. Siehe [firmware/README.md](../firmware/README.md) Abschnitt „Optional: sprechende Web-UI-Labels“.

## 11. MQTT + Home Assistant

```
Backlog MqttHost <MQTT_BROKER>;MqttPort 1883;MqttUser <MQTT_USER>;MqttPassword <MQTT_PASSWORT>;Topic iceweatherstation;FriendlyName1 IceWeatherstation;SetOption19 1
```

⚠️ `SetOption19` aktiviert Tasmotas **eigenes** Discovery-Format (`tasmota/discovery/<MAC>/config`), nicht das generische Home-Assistant-MQTT-Schema. Für automatische Entity-Erstellung braucht HA die dedizierte **„Tasmota"-Integration** (separat von der generischen „MQTT"-Integration, beide auf derselben Verbindung). Ist diese aktiv, erscheinen Entities wie `sensor.tasmota_ds18b20_temperature` automatisch nach einem Neustart des ESP32. Details + Dashboard-Einbindung: [tasmota-config.md](tasmota-config.md) Abschnitt 10.

```mermaid
sequenceDiagram
    participant WS as Wetterstation (Tasmota)
    participant MQ as MQTT-Broker
    participant HA as Home Assistant (Tasmota-Integration)

    WS->>MQ: connect (MqttUser/MqttPassword)
    WS->>MQ: publish tasmota/discovery/<MAC>/config (retained)
    WS->>MQ: publish tele/iceweatherstation/SENSOR (alle TelePeriod Sekunden)
    HA->>MQ: subscribe tasmota/discovery/#
    MQ-->>HA: Discovery-Config
    HA->>MQ: subscribe tele/iceweatherstation/SENSOR
    MQ-->>HA: Live-Sensorwerte
    HA->>HA: Entities automatisch angelegt
```

**Schwager-Gerät (ohne Home Assistant):** MQTT einfach unkonfiguriert lassen — das Web-UI und das OLED funktionieren komplett unabhängig davon. mDNS-Hostname (`http://tasmota-XXXX.local/`) als Lesezeichen/Homescreen-Icon speichern.

## 12. Gehäuse-/Mast-Montage

Details: [enclosure.md](enclosure.md). Kurzfassung:

1. Alle Sensoren final ins IP65-Gehäuse verkabeln (Zugentlastung an jeder Kabelverschraubung), Schraubklemmen statt Direktverlötung (leichtere Fehlersuche)
2. Mikrofonrohr (DNMS-Design) montieren, Öffnung nach unten, Schaumstoff-Windschutz einsetzen
3. Silikagel-Beutel ins Gehäuse legen
4. Anemometer/Windfahne so hoch und frei wie möglich, Regenmesser exakt waagerecht (Wasserwaage), AS3935 fern von Störquellen
5. Vor dem endgültigen Verschließen nochmal `Status 10` prüfen (alle Werte noch plausibel nach dem finalen Verkabeln?)

⚠️ **Stromversorgung — zwei Fallstricke live gefunden:**
- **Kein Spannungsteiler zur Versorgung!** Nur für Signale (Windfahne) geeignet, nicht für den ESP32 selbst (schwankender Stromverbrauch, WLAN-Spitzen bis 300–500 mA) — der 5V-Pin hat bereits einen eingebauten LDO-Regler auf 3,3V, einfach direkt anschließen.
- **Keine USB-C-Schnelllade-Netzteile (PD/QC)** — manche liefern ganz ohne Aushandlung mit einer "intelligenten" Gegenstelle keine Spannung, das Board bleibt dann komplett dunkel. Einfaches "dummes" 5V/1-2A-USB-Netzteil verwenden.

## 13. Kalibrierung nach dem Aufbau

- **Windfahne:** Rohe ADC-Werte (GPIO34, `Status 10` → `ANALOG.A1`) für jede der 16 Richtungen real messen (Kompass am Mast drehen) und die Platzhalter-Tabelle `VANE_TABLE` in [autoexec.be](../firmware/berry/autoexec.be) durch die gemessenen Werte ersetzen
- **dBA-Sensor:** Falls verfügbar, gegen ein Referenz-Schallpegelmessgerät bei 2-3 bekannten Lautstärken abgleichen
- **AS3935:** Bei häufigen Fehlalarmen (`disturber`-Events) `AS3935setnf` (Noise-Floor 0–7) nachjustieren — Outdoor-Modus reduziert das bereits deutlich

## Troubleshooting-Kurzreferenz

| Symptom | Wahrscheinliche Ursache |
|---|---|
| `I2CScan` findet BME280/AS3935/OLED nicht | Verkabelung SDA/SCL vertauscht (AS3935: Pin heißt „MOSI" nicht „SDA"), falsche I2C-Adresse, oder Board kurzzeitig ohne sauberen Neustart (I2C-Bus-Hang nach Watchdog-Reset — `Restart 1` behebt es) |
| DS18B20 liefert keinen Wert / erscheint nicht | 4,7 kΩ Pull-up fehlt zwischen DATA und 3,3V |
| `A1` (Windfahne) erscheint nicht in `Status 10` | `AdcParam1`-Parameter 4 ≠ 0 (Direct-Mode-Schalter) — auf `AdcParam1 6,0,0,0,0` zurücksetzen |
| dBA-Wert (`Range1`) unplausibel (z.B. 3,5 statt ~50-60) | Falscher `AdcParam`-Kanal (zählt nach GPIO-Reihenfolge, nicht GPIO-Nummer) oder Millivolt statt Pseudo-ADC-Wert verwendet |
| Counter1/2 zählen wild hoch ohne Bewegung | `CounterDebounce` steht auf 0 (unentprellt) — auf 10 setzen |
| `DisplayModel`/`AS3935*`-Befehle "Unknown" | Firmware ohne das jeweilige Feature — Custom-Build nötig (siehe Schritt 1) |
| `DisplayModel 2` wird lautlos auf 0 zurückgesetzt | Klassischer SSD1306-Treiber wurde entfernt — `DisplayModel 17` (uDisplay) verwenden |
| Status-LED bleibt aus trotz "LedLink"-GPIO-Rolle | `LedState` zusätzlich setzen (`LedState 7`) — GPIO-Rolle allein reicht nicht |
| Lokalzeit falsch (z.B. UTC+1 statt UTC+2 im Sommer) | `Timezone` steht nicht auf `99` |
| Display/LED gehen nach jedem Neustart kurz aus, unabhängig von der Uhrzeit | Nachtruhe-Check lief vor NTP-Sync (bereits im Skript gefixt, `tasmota.set_timer`) |
| `/cm`/`/cn`/`/md`-Aufrufe per `curl` liefern leere Antwort | Fehlender Referer-Header (Tasmota-Sicherheitsfeature) — `-e "http://<ip>/"` mitgeben |
| Board komplett dunkel (LED+OLED+alle Sensor-LEDs aus) | USB-C-Schnelllade-Netzteil liefert keine Spannung ohne Aushandlung — einfaches Netzteil verwenden |
| WLAN verbindet nicht nach Flash | ESP32 im AP-Modus (`tasmota-XXXX`) erneut verbinden, WLAN-Zugangsdaten neu eintragen |

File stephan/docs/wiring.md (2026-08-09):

# Verkabelung — Stephans Version

Alle Pin-Angaben nutzen die Beschriftung, wie sie direkt auf dem ESP32-WROOM-32U-DevKitC-V4-Board
aufgedruckt ist (z.B. `IO21`) — keine Umrechnung von GPIO-Nummern nötig. Vollständige Pin-Positionstabelle
(welcher Aufdruck an welcher physischen Stelle sitzt): [../../docs/wiring.md](../../docs/wiring.md)
(Originalgerät-Doku, Abschnitt "Pin-Position am ESP32-WROOM-32U DevKitC V4").

## Blockschaltbild

```mermaid
graph LR
    ESP32["ESP32-WROOM-32U<br/>DevKitC V4"]

    subgraph I2C-Bus [I2C-Bus - IO21/IO22]
        BME280["BME280<br/>Temp / Feuchte / Druck"]
        OLED["Hailege SSD1306 OLED<br/>128x64 Display"]
    end

    DS18B20["DS18B20<br/>wasserdichte Temp-Sonde, 1m"]
    RAIN["Regenmesser<br/>SEN-15901"]
    ANEMO["Anemometer<br/>SEN-15901"]
    VANE["Windfahne<br/>SEN-15901"]
    MQ135["MQ135<br/>Gassensor (Luftqualität)"]
    LED["Blaue Betriebs-LED"]
    ANT["Externe WLAN-Antenne<br/>via U.FL"]

    ESP32 -->|SDA/SCL IO21/IO22| BME280
    ESP32 -->|SDA/SCL IO21/IO22| OLED
    ESP32 -->|1-Wire IO4| DS18B20
    ESP32 -->|Interrupt IO14| RAIN
    ESP32 -->|Interrupt IO27| ANEMO
    ESP32 -->|ADC1 IO34| VANE
    ESP32 -->|ADC1 IO35| MQ135
    ESP32 -->|IO2| LED
    ESP32 -.->|U.FL/IPEX| ANT
```

## Pin-Tabelle

| Bauteil | Pin/Ader | Board-Pin | Hinweis |
|---|---|---|---|
| BME280 | VCC | 3V3 | |
| BME280 | GND | GND | |
| BME280 | SDA | IO21 | gemeinsamer I2C-Bus mit OLED |
| BME280 | SCL | IO22 | gemeinsamer I2C-Bus mit OLED |
| Hailege OLED | VCC | 3V3 | |
| Hailege OLED | GND | GND | |
| Hailege OLED | SDA | IO21 | dritter Teilnehmer am selben I2C-Bus |
| Hailege OLED | SCL | IO22 | dritter Teilnehmer am selben I2C-Bus |
| DS18B20 | VCC (meist rot) | 3V3 | |
| DS18B20 | GND (meist schwarz) | GND | |
| DS18B20 | DATA (meist gelb) | IO4 | + 4,7 kΩ Pull-up zwischen DATA und 3V3 (zwingend) |
| Blaue Status-LED | Anode (langes Beinchen) über 220 Ω-Vorwiderstand | IO2 | |
| Blaue Status-LED | Kathode (kurzes Beinchen) | GND | |
| SEN-15901 Regenmesser | Ader A (Reed-Kontakt, polaritätsfrei) | GND | kein Widerstand nötig |
| SEN-15901 Regenmesser | Ader B | IO14 | |
| SEN-15901 Anemometer | Ader A (rot oder gelb, Reed-Kontakt, polaritätsfrei) | GND | kein Widerstand nötig |
| SEN-15901 Anemometer | Ader B (gelb oder rot) | IO27 | |
| SEN-15901 Windfahne | Ader A (schwarz oder grün, variabler Widerstand, polaritätsfrei) | GND | |
| SEN-15901 Windfahne | Ader B (grün oder schwarz) | Spannungsteiler-Knoten → IO34 | + fester 10 kΩ-Widerstand zwischen 3V3 und diesem Knoten |
| MQ135 | VCC (Heizer) | **5V** (nicht 3V3!) | Heizer zieht durchgehend ~150–200 mA |
| MQ135 | GND | GND | |
| MQ135 | AOUT | Spannungsteiler-Knoten → IO35 | + 10 kΩ (AOUT→Knoten) und 15 kΩ (Knoten→GND) |

**Wichtig — welche Sensoren brauchen einen Widerstand:** Nur Bauteile mit einem *variablen* Ausgang
(Windfahne, MQ135) brauchen einen Spannungsteiler. Regenmesser und Anemometer sind reine Reed-Kontakt-
Schalter (an/aus) — die nutzt den internen Pull-up des ESP32, kein externer Widerstand nötig.

## Schaltbilder

### DS18B20 Pull-up

Der 4,7-kΩ-Widerstand überbrückt **3V3 und die DATA-Leitung** als eigene, dritte Verbindung — zusätzlich
zum normalen dreiadrigen Sensorkabel. 1-Wire-Busse wie beim DS18B20 haben keinen aktiven Treiber, der die
Leitung auf HIGH zieht: ohne den Widerstand "floatet" IO4 (kein definierter Pegel), sobald niemand gerade
sendet, und der Sensor bleibt beim Scan unsichtbar — kein Defekt, sondern erwartetes Verhalten eines
offenen Busses.

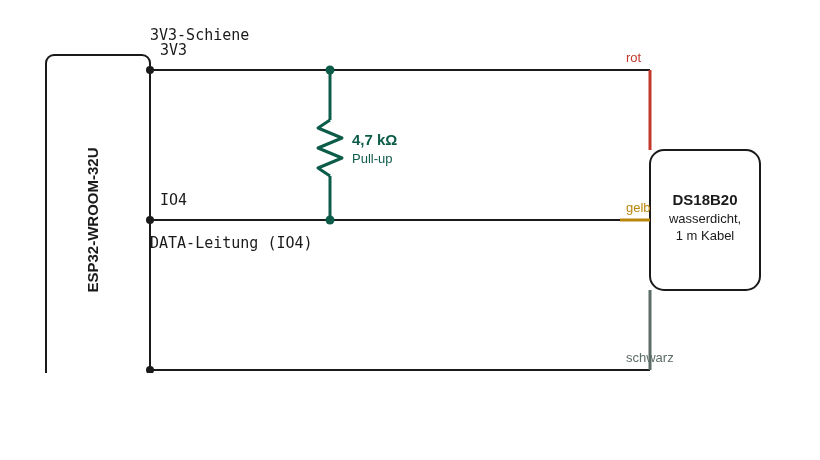
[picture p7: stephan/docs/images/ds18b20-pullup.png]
DS18B20 Pull-up-Schaltbild


### MQ135-Spannungsteiler

Reduziert den 0–5V-Rohausgang des Sensors auf den 0–3,3V-Bereich, den der ESP32-ADC verträgt: 10 kΩ
zwischen AOUT und dem IO35-Messknoten, 15 kΩ zwischen diesem Knoten und GND.

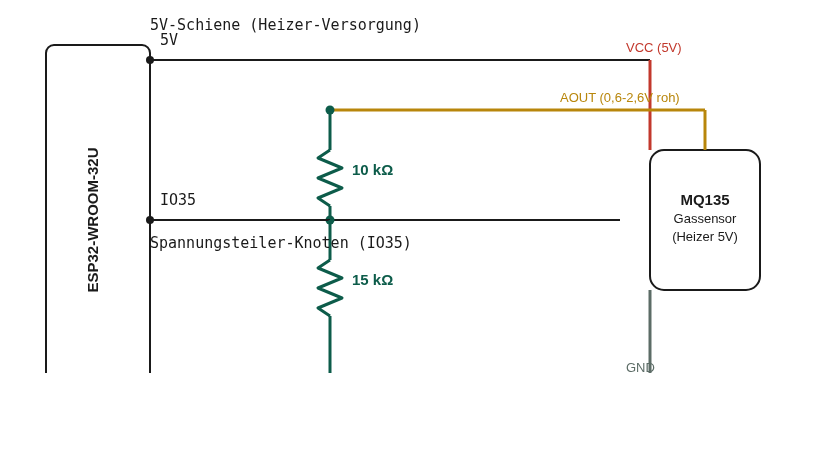
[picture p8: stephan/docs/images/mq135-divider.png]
MQ135-Spannungsteiler-Schaltbild


### Status-LED

Einfache Einzel-LED mit Vorwiderstand, keine Besonderheiten in der Verkabelung selbst — die Software-Seite
(GPIO-Rolle, Blink-Logik) ist in [tasmota-config.md](tasmota-config.md) dokumentiert.

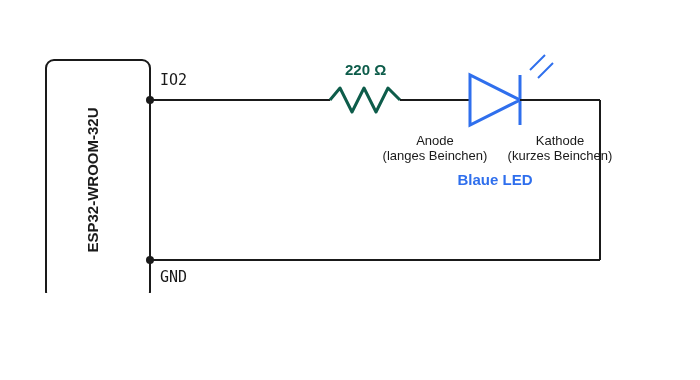
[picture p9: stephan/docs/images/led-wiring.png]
LED-Schaltbild


## RJ11-Pinbelegung SEN-15901

| Sensor | Kabel | Belegte Pins | Funktion |
|---|---|---|---|
| Regenmesser | eigenes, separates Kabel | die beiden mittleren Kontakte | Reed-Kontakt (Schalter) |
| Anemometer | gemeinsames Kabel mit Windfahne | Pins 2+3 (innere Adern) | Reed-Kontakt (Schalter) |
| Windfahne | gemeinsames Kabel mit Anemometer | Pins 1+4 (äußere Adern) | 8-Stufen-Widerstandsnetzwerk, 891 Ω–120 kΩ |

Aderfarben sind laut Datenblatt nicht herstellerübergreifend einheitlich dokumentiert — für das bei
Stephans Aufbau tatsächlich verbaute Exemplar per Multimeter gegen die Pin-Nummern verifiziert:

| Ader-Farbe | Zugehörig zu |
|---|---|
| Rot + Gelb | Anemometer |
| Schwarz + Grün | Windfahne |

Gilt für dieses konkrete SEN-15901-Exemplar — bei einem anderen Kabelsatz sicherheitshalber trotzdem
gegen die Pin-Nummern (RJ11 2+3 = Anemometer, 1+4 = Windfahne) nachmessen, bevor final verlötet wird.
Details zum Original-Datenblatt (Shenzhen Fine Offset Electronics, `DS-15901-Weather_Meter.pdf`):
[../../docs/wiring.md](../../docs/wiring.md).

## Widerstandsliste (Zusammenfassung)

| Widerstand | Zweck | Position |
|---|---|---|
| 4,7 kΩ | DS18B20 1-Wire Pull-up | zwischen IO4 und 3V3 |
| 10 kΩ | Windfahnen-Spannungsteiler | zwischen 3V3 und IO34-Knoten |
| 10 kΩ | MQ135-Spannungsteiler (oberer Teil) | zwischen MQ135-AOUT und IO35-Knoten |
| 15 kΩ | MQ135-Spannungsteiler (unterer Teil) | zwischen IO35-Knoten und GND |
| 220 Ω | LED-Vorwiderstand | zwischen IO2 und LED-Anode |

## Live gefundener Fallstrick: Wackelkontakt am Windfahnen-Knoten

Beim Aufbau zeigte der Windfahnen-Rohwert (`ANALOG.A1`) einen ständig schwankenden Wert (z.B.
188→245→184), obwohl die Fahne stillstand — auch nachdem ein externer Störfaktor (ein in der Nähe
drehendes Anemometer) ausgeschlossen wurde. Ursache war ein loser Kontakt am Spannungsteiler-Knoten
(Widerstand-Beinchen bzw. Windfahnen-Ader nicht fest genug verbunden). Nach dem Nachdrücken aller drei
Verbindungen an diesem Knoten stand der Wert bei konstanter Ausrichtung felsenfest. Symptom-Erkennung:
ein *stillstehender* Sensor sollte einen *stabilen* Rohwert liefern — deutliches, unregelmäßiges
Schwanken deutet auf einen losen Kontakt, nicht auf einen defekten Sensor.

## Live gefundener Fallstrick: Regenmesser/Anemometer vertauscht

Bei Stephans Aufbau landeten Regenmesser und Anemometer auf den jeweils anderen Pins als ursprünglich
dokumentiert (Regenmesser auf IO14 statt IO27, Anemometer auf IO27 statt IO14). Erkannt durch gezieltes
Debugging: ein direkter Kurzschlusstest IO14↔GND am ESP32 (ganz ohne Sensorkabel) ließ den Zähler
zuverlässig hochzählen — das ESP32-seitige Pin/GPIO war also nachweislich in Ordnung, nur der erwartete
Sensor reagierte nicht. Da Counter1/Counter2 rein softwareseitig vergebene, funktional identische Rollen
sind (kein Hardware-Unterschied zwischen den beiden Pins), ließ sich das Problem ohne Umverkabeln lösen:
einfach die Rollen in der Software vertauscht (`GPIO14 352` = Counter1, `GPIO27 353` = Counter2, statt
umgekehrt) — passt sich damit an die tatsächliche Verkabelung an, statt die Kabel physisch zu tauschen.
**Lehre:** Bei einem nicht reagierenden Zähler-Sensor lohnt sich immer zuerst ein Kurzschlusstest direkt
am ESP32-Pin, bevor man das Sensorkabel verdächtigt — das trennt zuverlässig "Pin kaputt/falsch
konfiguriert" von "falscher Sensor an diesem Pin" bzw. "Kabelproblem".

Weiter mit: [tasmota-config.md](tasmota-config.md) für die Firmware-Konfiguration.

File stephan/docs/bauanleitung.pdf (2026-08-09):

# ️ IceWeatherstation

### Stephans Version – Schritt-für-Schritt inkl. Verkabelung

Reduzierte Variante: BME280, OLED-Display, wasserdichter Temperaturfühler, Windrichtung, Windgeschwindigkeit, Regenmenge, Luftqualität (MQ135), Betriebs-LED Ohne Blitzsensor und ohne Schallpegelsensor

Erstellt: 08.08.2026 · Pin-Bezeichnungen wie auf dem ESP32-Board aufgedruckt Vollständige Projektdoku (Originalgerät, mehr Sensoren): github.com/icepaule/IceWeatherstation

## Inhalt

1. Überblick — was dein Gerät kann
2. Was schon erledigt ist
3. Teileliste
4. Verkabelung + Pin-Tabelle (Board-Beschriftung)
5. Sensoren einzeln anschließen und testen
6. Eigenes WLAN eintragen
7. Status-LED
8. Gehäuse- und Mastmontage
9. Kalibrierung nach dem Aufbau
10. Fertig — Werte ablesen
11. Troubleshooting

## 1. Überblick — was dein Gerät kann

Dein Gerät ist eine reduzierte Variante der IceWeatherstation: dieselbe Basis (ESP32 + Tasmota-Firmware), aber mit weniger Sensoren als das Originalgerät. Kein Blitzsensor, kein Schallpegelsensor — dafür einfacher im Aufbau. Alle Werte erscheinen automatisch auf einer eigenen Webseite im Browser (kein Cloud-Konto, keine App nötig) und zusätzlich live auf dem kleinen OLED-Display am Gehäuse.

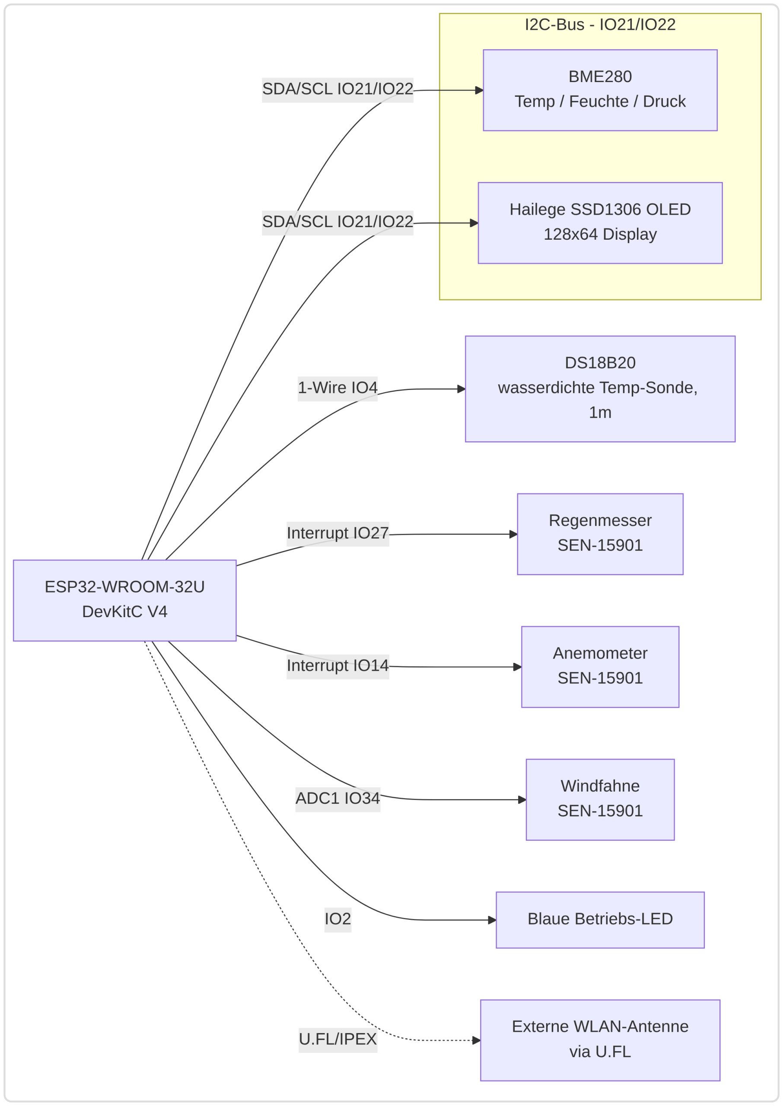
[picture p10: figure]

Blockschaltbild deiner Version: BME280 und OLED teilen sich einen I2C-Bus, alle anderen Sensoren hängen einzeln am ESP32.

Was das Gerät misst

Messgröße | Sensor
Temperatur, Luftfeuchte, Luftdruck | BME280
Zusatztemperatur (wasserdicht, außen) | DS18B20, 1m Kabel
Windgeschwindigkeit | SparkFun SEN-15901 (Anemometer)
Windrichtung | SparkFun SEN-15901 (Windfahne)
Niederschlagsmenge | SparkFun SEN-15901 (Regenmesser/Kippwaage)
Anzeige direkt am Gehäuse | Hailege 0,96" OLED, 128×64, I2C
Luftqualität (CO2-ähnlich, intern) | MQ135-Gassensor, im geschlossenen Hauptgehäuse
Betriebsanzeige | Blaue Status-LED (blinkt bei Web-UI-Zugriff, siehe Abschnitt 7)

## 2. Was schon erledigt ist

Das Board ist bereits fertig vorkonfiguriert — die Firmware wurde geflasht, alle GPIOs für genau deine Sensoren gesetzt, das OLED-Display softwareseitig eingerichtet und das passende Dashboard-Skript hochgeladen. Das wurde am 08.08.2026 zum Testen kurz mit einem eigenen (privaten) WLAN verbunden — das trägst du in Schritt 6 auf dein eigenes WLAN um, das ist der einzige Software-Schritt, der noch nötig ist.

Konkret schon erledigt:

Firmware geflasht: Tasmota 15.5.0 (Sonder-Build mit OLED-Unterstützung) Gerätename gesetzt: Wetterstation Stephan
Alle GPIOs für deine Sensoren konfiguriert (Tabelle in Abschnitt 4)
OLED-Display softwareseitig aktiviert (uDisplay/SSD1306)
Dashboard-Skript hochgeladen (zeigt WLAN/Wind/Regen/Temperatur/Druck/Feuchte auf dem Display)
Zeitzone (Europe/Berlin, Sommerzeit) gesetzt
MQ135-Luftqualitätssensor per Eigenkalibrierung eingebunden (Details Abschnitt 5.7) Temperatur gegen Referenzthermometer kalibriert ( TempOffset )
Status-LED blinkt bei Web-UI-Zugriff (Details Abschnitt 7)
Kein MQTT/Home Assistant konfiguriert — bewusst, dein Gerät braucht das nicht, alles läuft übers Web-UI

Was du noch tun musst: Sensoren verkabeln (Abschnitt 4+5), eigenes WLAN eintragen (Abschnitt 6), Gehäuse/Mast montieren (Abschnitt 8), Windfahne kalibrieren (Abschnitt 9).

## 3. Teileliste

# | Bauteil | Hinweis

1 | ESP32-WROOM-32U DevKitC V4 (extern Antenne) | bereits geflasht/konfiguriert — das Board, das du hast
2 | WLAN-Antenne, 2,4 GHz, U.FL/IPEX | nicht direkt an Metallteilen montieren
3 | Bosch BME280 I2C-Breakout | SDA/SCL gemeinsam mit OLED
4 | Hailege 0,96" I2C OLED-Display, 128×64, 4-Pin | gemeinsamer I2C-Bus mit BME280
5 | DS18B20, wasserdicht, 1m Kabel | + 4,7 kΩ Pull-up-Widerstand nötig
6 | SparkFun Weather Meter Kit SEN-15901 | Regenmesser + Anemometer + Windfahne in einem Set
7 | Blaue LED (Betriebsanzeige) + 220Ω-Vorwiderstand | einfache Einzel-LED reicht

7b | MQ135-Gassensor (4-Pin-Breakout) | Heizer braucht 5V, im geschlossenen Hauptgehäuse montiert (kein Außenluftkontakt)
8 | Widerstände: 1× 4,7 kΩ (DS18B20-Pullup), 1× 10 kΩ (Windfahnen-Spannungsteiler), 1× 10 kΩ + 1× 15 kΩ (MQ135-Spannungsteiler) | 1%-Toleranz empfohlen
9 | Elektronik-Gehäuse, IP65, ~200×120×75mm | für ESP32 + BME280 + Klemmleisten
10 | Kabelverschraubungen IP68, gemischte Größen | Wetterkabel-Bündel, DS18B20-Sonde, Stromkabel
11 | Mast/Rohrhalterung, Aluminium, U-Bolzen | Anemometer/Windfahne brauchen freien Luftstrom
12 | Wetterfeste 5V/USB-Stromzuleitung | einfaches "dummes" Netzteil, kein Schnelllader (siehe Warnhinweis Abschnitt 8)
13 | Schraub-/Verbindungsklemmen, Dupont-Kabel | Klemmen statt Löten = leichtere Fehlersuche
14 | Silikagel-Beutel | gegen Kondenswasser im Gehäuse

## 4. Verkabelung + Pin-Tabelle (Board-Beschriftung)

Die Pins sind hier mit der Beschriftung angegeben, die direkt auf deinem ESP32-Board neben den Stiftleisten aufgedruckt ist (z.B. "IO21") — du musst also nicht zwischen GPIO-Nummern und Board umrechnen.

Bauteil | Pin/Ader | Board-Pin | Hinweis
BME280 | VCC | 3V3
BME280 | GND | GND
BME280 | SDA | IO21 | gemeinsamer I2C-Bus mit OLED
BME280 | SCL | IO22 | gemeinsamer I2C-Bus mit OLED
Hailege OLED | VCC | 3V3
Hailege OLED | GND | GND
Hailege OLED | SDA | IO21 | dritter Teilnehmer am selben I2C-Bus
Hailege OLED | SCL | IO22 | dritter Teilnehmer am selben I2C-Bus
DS18B20 | VCC (meist rot) | 3V3
DS18B20 | GND (meist schwarz) | GND
DS18B20 | DATA (meist gelb) | IO4 | + 4,7 kΩ Pull-up zwischen DATA und 3V3 (zwingend!)
Blaue Status-LED | Anode (langes Beinchen) über 220Ω-Vorwiderstand | IO2
Blaue Status-LED | Kathode (kurzes Beinchen) | GND
SEN-15901 Regenmesser | Ader A | GND | Reed-Kontakt, polaritätsfrei
SEN-15901 Regenmesser | Ader B | IO27
SEN-15901 Anemometer | Ader A | GND | Reed-Kontakt, polaritätsfrei
SEN-15901 Anemometer | Ader B | IO14
SEN-15901 Windfahne | Ader A | GND | variabler Widerstand, polaritätsfrei

SEN-15901 Windfahne | Ader B | Spannungsteiler-Knoten → IO34 | + fester 10 kΩ-Widerstand zwischen 3V3 und diesem Knoten
MQ135 | VCC (Heizer) | 5V (nicht 3V3!) | Heizer zieht durchgehend ~150– 200 mA
MQ135 | GND | GND
MQ135 | AOUT | Spannungsteiler-Knoten → IO35 | + 10 kΩ (AOUT→Knoten) und 15 kΩ (Knoten→GND), siehe Diagramm unten

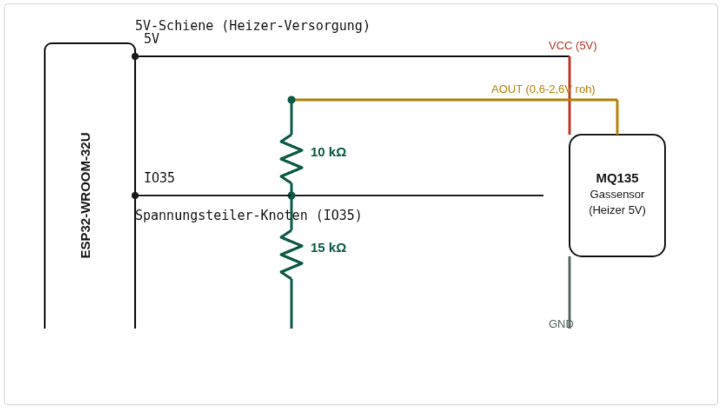
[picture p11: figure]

MQ135-Spannungsteiler: 10 kΩ zwischen AOUT und dem IO35-Messknoten, 15 kΩ zwischen diesem Knoten und GND — reduziert den 0–5V-Rohausgang auf den 0–3,3V-Bereich, den der ESP32-ADC verträgt.

Software-Konfiguration (bereits erledigt, nur zur Info): Jeder Pin oben wurde intern folgender GPIO-Rolle zugewiesen — falls du das Board mal neu flashen musst, hier der komplette Befehl:

Backlog GPIO21 640;GPIO22 608;GPIO4 1312;GPIO27 352;GPIO14 353;GPIO34 4704;GPIO35 4864;GPIO32 6210;GPIO2 288

(Stand 08.08.2026: IO35 nutzt die Rolle "ADC Range1" statt "ADC Input1" — ein ESP32 unterstützt nur eine Instanz von "ADC Input" gleichzeitig, die belegt die Windfahne (IO34). IO35 zusätzlich mit AdcParam2 6,0,4095,0,4095 auf reine 1:1-Durchreichung gestellt (die Rolle "ADC Range" würde sonst eine eigene Skalierung anwenden) — dadurch zeigt der MQ135-Rohwert im Web-UI leider unter der fest einkompilierten Fehlbezeichnung "Schallpegel...dBA" (Custom-Firmware-Label-Patch vom Originalgerät, dort war "Range" tatsächlich der dBA-Sensor; nur per Firmware-Neubau behebbar). Die echte, korrekt benannte "Luftqualität"-Zeile im Web-UI ist die maßgebliche Anzeige. IO2 nutzt die Rolle "Led" statt "LedLink" — "LedLink" hat ein eigenes, nicht abschaltbares Verbindungsstatus-Verhalten, das eine frei steuerbare Anzeige-LED stört.) (IO32 ist ein rein virtueller Marker fürs OLED, kein physischer Sensor-Pin — nicht verkabeln.)

RJ11-Pinbelegung SEN-15901

Sensor | Kabel | Belegte Pins | Funktion
Regenmesser | eigenes, separates Kabel | die beiden mittleren Kontakte | Reed-Kontakt (Schalter)
Anemometer | gemeinsames Kabel mit Windfahne | Pins 2+3 (innere Adern) | Reed-Kontakt (Schalter)
Windfahne | gemeinsames Kabel mit Anemometer | Pins 1+4 (äußere Adern) | 8-Stufen-Widerstandsnetzwerk, 891 Ω–120 kΩ

Aderfarben sind nicht herstellerübergreifend einheitlich — im Zweifel per Multimeter gegen die Pin-Nummern verifizieren, bevor final verlötet wird.

Kein Spannungsteiler zur Stromversorgung! Ein Widerstandsteiler funktioniert nur für Signale (wie bei der Windfahne), niemals um den ESP32 selbst zu versorgen — der zieht schwankenden Strom (WLAN-Spitzen bis 300–500 mA), ein Teiler würde einbrechen (Reset-Schleifen). 5V-Zuleitung einfach direkt an den 5V-Pin (Board hat einen eingebauten LDO-Regler auf 3,3V).

## 5. Sensoren einzeln anschließen und testen

Nacheinander anschließen und nach jedem Sensor sofort prüfen — das spart bei einem Fehler das Durchsuchen mehrerer gleichzeitig neuer Kabel. Öffne dazu im Browser die Adresse des Geräts (siehe Abschnitt 6) → Konsole, und gib die Befehle unten dort ein.

### 5.1 DS18B20

VCC/GND/DATA anschließen + zwingend 4,7 kΩ Pull-up zwischen DATA und 3V3 (ohne Pull-up bleibt der Sensor unsichtbar — kein Fehler, sondern erwartetes Verhalten eines offenen 1-Wire-Busses). Prüfen: Status 10 → DS18B20:{"Temperature":...} sollte erscheinen.

### 5.2 Windfahne

Spannungsteiler mit festem 10 kΩ-Widerstand zwischen 3V3 und IO34, Windfahne selbst zwischen IO34-Knoten und GND. Prüfen: Status 10 → ANALOG:{"A1":...} .

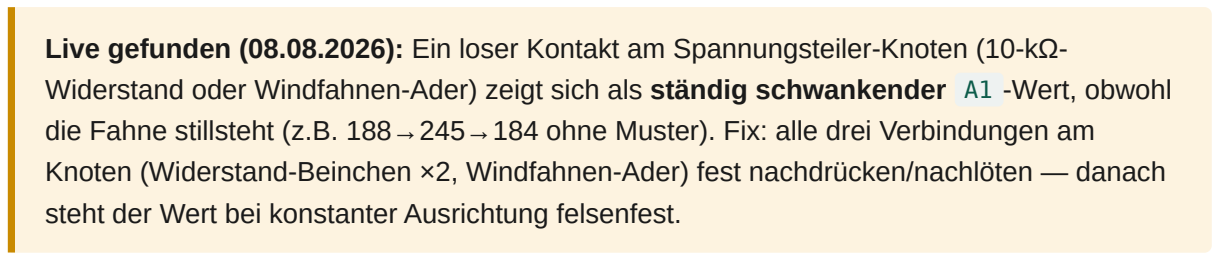
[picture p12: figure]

Live gefunden (08.08.2026): Ein loser Kontakt am Spannungsteiler-Knoten (10-kΩ-Widerstand oder Windfahnen-Ader) zeigt sich als ständig schwankender A1 -Wert, obwohl die Fahne stillsteht (z.B. 188→245→184 ohne Muster). Fix: alle drei Verbindungen am Knoten (Widerstand-Beinchen ×2, Windfahnen-Ader) fest nachdrücken/nachlöten — danach steht der Wert bei konstanter Ausrichtung felsenfest.

### 5.3 Regenmesser + Anemometer

CounterDebounce ist bereits auf 10 gesetzt (Entprellung). Test: Reed-Kontakte per Hand kurz schließen bzw. Anemometer drehen — COUNTER:{"C1":...,"C2":...} sollte hochzählen (C1 = Regen, C2 = Wind).

### 5.4 BME280

Gemeinsamer I2C-Bus mit dem OLED. I2CScan sollte 0x76 (oder 0x77 ) finden.

### 5.5 OLED-Display

Ist bereits softwareseitig eingerichtet (uDisplay, DisplayModel 17 ). Nach dem Anschließen an IO21/IO22/3V3/GND sollte es automatisch die vier Dashboard-Zeilen zeigen. Falls nicht: Boot-Log prüfen, dort sollte DSP: SSD1306 initialized stehen — falls dein Display auf Adresse 0x3D statt 0x3C läuft, sag Bescheid, dann muss der Descriptor einmal angepasst werden.

### 5.6 Blaue Status-LED

Über 220Ω-Vorwiderstand an IO2 (Anode) und GND (Kathode). Details zum Blink-Verhalten: Abschnitt 7.

### 5.7 MQ135 (Luftqualität)

Spannungsteiler wie im Diagramm in Abschnitt 4 (10 kΩ zwischen AOUT und dem IO35-Knoten, 15 kΩ zwischen diesem Knoten und GND), Heizer an 5V (nicht 3V3). Prüfen: Status 10 → ANALOG:{"Range1":...} sollte einen Rohwert zwischen 0 und 4095 zeigen.

Der Sensor ist bereits per Eigenkalibrierung eingebunden (kein Standard-Tasmota-Feature, siehe Kasten unten) und braucht nach jedem Neustart 180 Sekunden in normaler/sauberer Luft, bevor die Web-UI-Zeile "Luftqualität" einen echten Wert statt "Kalibriere.." zeigt. Neustart also nicht direkt nach Kochen/Rauchen/Lüften auslösen, sonst verzerrt das die Referenz bis zum nächsten Neustart.

Warum eine Eigenkalibrierung nötig war: Tasmotas eingebaute MQ-Sensor-Formel (Kommando AdcParam Typ 10) geht von einem anderen Spannungsteiler-Aufbau aus als unserem und lieferte am realen Sensor dauerhaft unplausible Werte, unabhängig von der Laufzeit. Das Dashboard-Skript berechnet den ppm-Wert deshalb komplett selbst aus dem rohen ADC-Wert (Formel und Kalibrier-Konstanten identisch zu bereits seit Tagen produktiv laufenden, baugleichen MQ135-Sensoren im eigenen Heimnetz, nur mit unserem eigenen Spannungsteiler-Verhältnis).

## 6. Eigenes WLAN eintragen

Das Gerät wird dir bereits im Ersteinrichtungs-Zustand übergeben — es öffnet direkt nach dem Einschalten seinen eigenen WLAN-Zugangspunkt mit dem Namen Wetterstation-Stephan und einer Auswahlseite für dein WLAN, genau wie bei einem neuen Router.

1. Mit dem Handy/Laptop mit dem WLAN Wetterstation-Stephan verbinden
2. Es sollte sich automatisch eine Setup-Seite öffnen (falls nicht: im Browser 192.168.4.1 aufrufen)
3. Dein eigenes WLAN aus der Liste wählen, Passwort eintragen, speichern

Danach ist das Gerät in deinem eigenen WLAN erreichbar — der Gerätename ( Wetterstation-Stephan ) bleibt gleich, nur das Netzwerk wechselt. Als Lesezeichen speichern, das ist später deine "App". Falls der mDNS-Name ( .local ) bei dir nicht auflöst, zeigt dein Router (DHCP-Client-Liste) die aktuelle IP-Adresse unter dem Gerätenamen Wetterstation-Stephan .

Alternative über die Konsole, falls die Setup-Seite mal nicht erscheint: Backlog SSID1 <DEIN_WLAN_NAME>;Password1 <DEIN_WLAN_PASSWORT>

## 7. Status-LED

Deine LED blinkt bei WLAN-Datentransfer — jedes Mal, wenn die Web-UI-Seite offen ist und sich aktualisiert, blitzt sie kurz auf (ca. 400ms), aber höchstens einmal alle 2 Sekunden. Anders als beim Originalgerät (das MQTT nutzt und dort LedState 7 für "blinkt bei jeder MQTT-Aktivität" verwendet) hat Tasmota für generischen WLAN-Traffic keinen eingebauten Blink-Modus — dein Gerät braucht ja bewusst kein MQTT. Das Dashboard-Skript steuert die LED deshalb komplett manuell ( LedState 0 + gezielte LedPower1 -Befehle).

In der Nachtruhe (22:00–08:00 Uhr) bleibt die LED durchgehend aus, damit sie nachts niemanden stört.

Wichtig für die GPIO-Rolle: IO2 muss die Rolle "Led" haben, nicht "LedLink" — Letztere hat ein eigenes, fest verdrahtetes Verbindungsstatus-Verhalten (springt selbstständig auf LedState 8 , "an wenn WLAN verbunden") und überschreibt jede manuelle Steuerung. Live gefunden und korrigiert (08.08.2026) — falls die LED bei dir dauerhaft leuchtet statt zu blinken, GPIO2 prüfen (Konsole: GPIO2 ) — muss {"Led1":288} zeigen, nicht {"LedLink":544} .

Wichtig: dein Browser-Tab muss aktiv/fokussiert sein — die meisten Browser drosseln JavaScript-Timer in Hintergrund-Tabs stark, dann wirkt es so, als würde die LED gar nicht blinken, obwohl der Mechanismus läuft. Ein Reload mit aktivem Tab behebt das.

## 8. Gehäuse- und Mastmontage

1. Alle Sensoren final ins IP65-Gehäuse verkabeln (Zugentlastung an jeder Kabelverschraubung), Schraubklemmen statt Direktverlötung (leichtere Fehlersuche später)
2. Silikagel-Beutel ins Gehäuse legen
3. Anemometer/Windfahne so hoch und frei wie möglich montieren, Regenmesser exakt waagerecht (Wasserwaage!)
4. Vor dem endgültigen Verschließen nochmal Status 10 prüfen — sind alle Werte nach dem finalen Verkabeln noch plausibel?

Stromversorgung — zwei Fallstricke aus dem Originalaufbau:

Kein Spannungsteiler zur Versorgung! 5V-Pin direkt anschließen (eingebauter LDO-Regler).
Keine USB-C-Schnelllade-Netzteile (PD/QC)! Manche liefern ganz ohne Aushandlung mit einer "intelligenten" Gegenstelle keine Spannung — das Board bleibt dann komplett dunkel. Einfaches "dummes" 5V/1-2A-USB-Netzteil verwenden (z.B. altes Handy-Ladegerät).

## 9. Kalibrierung nach dem Aufbau

Windfahne: Die Tabelle im Dashboard-Skript ist bereits aus dem offiziellen Hersteller-Datenblatt der SEN-15901-Sensorik berechnet (Widerstand→Richtung, umgerechnet auf unseren 10-kΩ-Spannungsteiler) — kein Software-Abgleich mehr nötig. Die Kalibrierung reduziert sich auf einen rein mechanischen Schritt bei der Mastmontage:

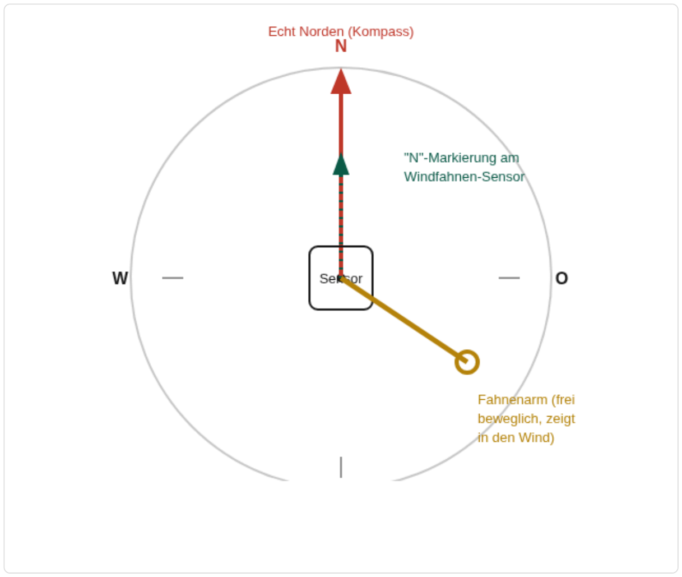
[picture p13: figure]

1. Windfahne auf ihre Achse/Lager montieren (noch nicht endgültig fixieren)
2. Kompass (echtes Gerät oder Handy-App) direkt daneben halten, echt Norden bestimmen
3. Sensorgehäuse so drehen, dass seine "N"-Markierung exakt nach Norden zeigt
4. Erst jetzt endgültig festschrauben/fixieren

Danach stimmen die angezeigten Richtungen direkt, ohne weiteren Software-Abgleich. Optionale Gegenprobe danach: Status 10 → ANALOG.A1 mit der Fahne in eine bekannte Richtung gedreht abfragen und mit der Tabelle im Skript vergleichen.

Wichtig: Eine Kompass-Gegenprobe funktioniert nur zuverlässig, wenn die Fahne fest auf ihrer Achse montiert ist und frei in ihre 16 Rastpositionen einrasten kann. Von Hand gehalten liefert der Rohwert keine eindeutigen Ergebnisse (zwei benachbarte Kontakte können gleichzeitig leicht aktiv sein) — kein Defekt, sondern normales Verhalten einer nicht fest montierten Fahne. Also erst nach dem endgültigen Festschrauben testen.

Temperatur: Falls DS18B20 oder BME280 gegenüber einem Referenzthermometer daneben liegen (z.B. durch Eigenerwärmung nahe der Elektronik), lässt sich das mit einem einzigen Befehl korrigieren:

TempOffset <Differenz in °C, -12.6 bis 12.6>

Wirkt global auf alle Temperatursensoren des Geräts gleichzeitig (kein Pro-Sensor-Wert in Tasmota) — am besten erst nach der finalen Montage im Gehäuse kalibrieren, da sich die Eigenerwärmung je nach Position/Gehäuse unterscheidet.

## 10. Fertig — Werte ablesen

Die gespeicherte Adresse http://tasmota-EF4E84-3716.local/ (oder die feste IP aus deinem Router) im Browser öffnen — dort erscheinen alle Sensorwerte live, ganz ohne App oder Cloud-Konto. Auf dem Smartphone als Homescreen-Icon speicherbar, damit es sich wie eine App anfühlt.

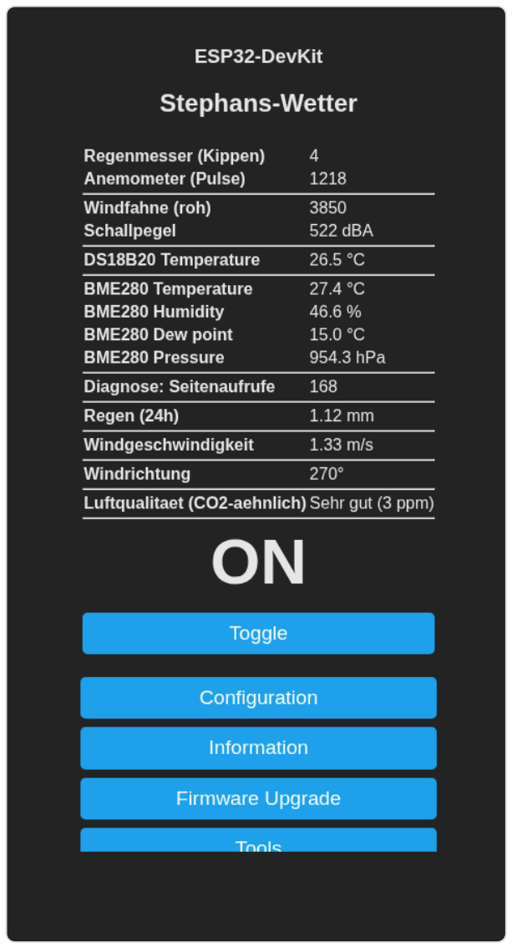
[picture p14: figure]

Das OLED-Display zeigt die wichtigsten Kernwerte zusätzlich direkt am Gehäuse, auch ganz ohne Handy/Browser in der Nähe — vier Zeilen mit fest zugeordneter Bedeutung:

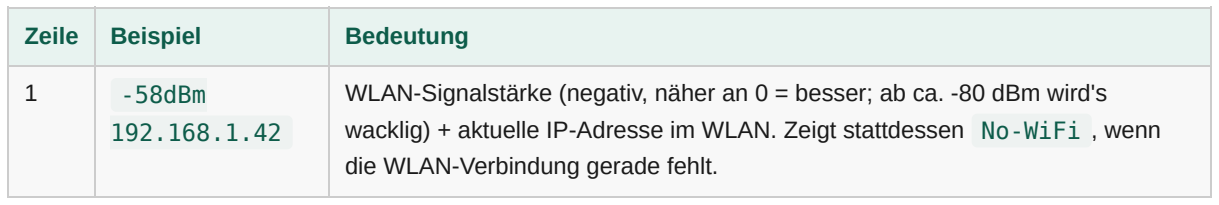
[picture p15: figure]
Zeile; Beispiel; Bedeutung

1 | -58dBm 192.168.1.42 | WLAN-Signalstärke (negativ, näher an 0 = besser; ab ca. -80 dBm wird's wacklig) + aktuelle IP-Adresse im WLAN. Zeigt stattdessen No-WiFi , wenn die WLAN-Verbindung gerade fehlt.

2 | 2M 270° 3L | M = Windgeschwindigkeit in Metern pro Sekunde (m/s). ° = Windrichtung in Grad, wie am Kompass (0°/360°=Nord, 90°=Ost, 180°=Süd, 270°=West), im Uhrzeigersinn. L = Regenmenge der letzten 24 Stunden in Liter pro Quadratmeter — das ist dieselbe Einheit wie „mm Niederschlag" (1 mm Regen = 1 L/m²), nur anders benannt.
3 | 21.4C 1013 U 55% | Lufttemperatur in °C (vom wasserdichten DS18B20-Fühler, nicht vom BME280 — der sitzt zu nah an der Elektronik und würde sich selbst aufheizen), Luftdruck in hPa (ganzzahlig gerundet), Drucktrend der letzten Stunden (Up = steigt, Down = fällt, - = stabil — grober Hinweis auf Wetteränderung), Luftfeuchte in % (vom BME280).
4 | Regen Stunde: 0.2L | Regenmenge der aktuell laufenden Stunde, gleiche Einheit wie Zeile 2 (L = L/m² = mm). Setzt sich zu Beginn jeder neuen Stunde automatisch auf 0 zurück.

Nachts (22:00–08:00 Uhr) bleiben Display und Status-LED bewusst aus, um nicht zu stören — das ist kein Fehler, siehe Abschnitt 7. Die Web-Oberfläche liefert dieselben Werte plus einige zusätzliche (z.B. Luftqualität, Seitenaufrufe-Zähler) jederzeit, auch nachts.

## 11. Troubleshooting

Symptom | Wahrscheinliche Ursache
I2CScan findet BME280/OLED nicht | SDA/SCL vertauscht, falsche I2C-Adresse, oder Board ohne sauberen Neustart (I2C-Bus-Hang — Restart 1 behebt es)
DS18B20 liefert keinen Wert | 4,7 kΩ Pull-up fehlt zwischen DATA und 3V3
A1 (Windfahne) erscheint nicht in Status 10 | Verkabelung des Spannungsteilers prüfen (10 kΩ zwischen 3V3 und IO34)
A1 schwankt ständig, obwohl Fahne stillsteht | Wackelkontakt am Spannungsteiler-Knoten — Widerstand-Beinchen und Windfahnen-Ader nachdrücken (siehe 5.2)
"Schallpegel"-Zeile im Web-UI zeigt Werte, obwohl kein Schallsensor verbaut ist | Bekannter kosmetischer Fallstrick — das ist der MQ135-Rohwert unter falschem, fest einkompiliertem Label (nur per Firmware-Neubau behebbar). Maßgeblich ist die Zeile "Luftqualität".
Counter1/2 zählen wild hoch ohne Bewegung | Kontaktprellen — CounterDebounce ist bereits auf 10 gesetzt, bei Bedarf höher
OLED bleibt dunkel | Verkabelung IO21/IO22/3V3/GND prüfen, I2C-Adresse ggf. 0x3D statt 0x3C (siehe 5.5)
Luftqualität zeigt dauerhaft "Kalibriere.." | Braucht 180s ununterbrochene Laufzeit nach dem letzten Neustart (siehe 5.7) — kein neuer Neustart währenddessen
Status-LED bleibt aus | Prüfen ob gerade Nachtruhe (22:00–08:00 Uhr) aktiv ist — das ist so gewollt
Status-LED leuchtet dauerhaft statt zu blinken | GPIO2 prüfen — muss Rolle "Led" (288) sein, nicht "LedLink" (544), siehe Abschnitt 7

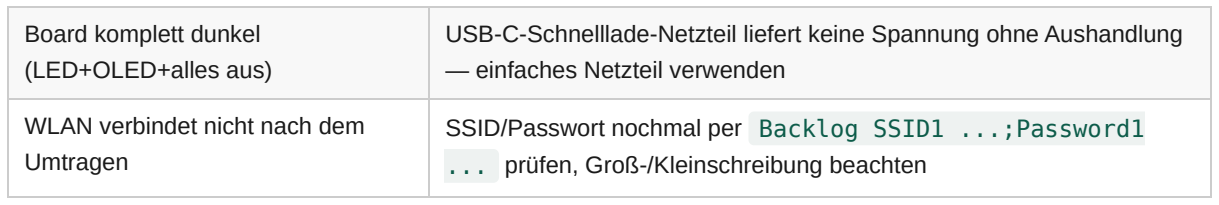
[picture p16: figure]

Board komplett dunkel (LED+OLED+alles aus) | USB-C-Schnelllade-Netzteil liefert keine Spannung ohne Aushandlung — einfaches Netzteil verwenden
WLAN verbindet nicht nach dem Umtragen | SSID/Passwort nochmal per Backlog SSID1 ...;Password1 ... prüfen, Groß-/Kleinschreibung beachten

Viel Erfolg beim Aufbau! Bei Fragen einfach melden — die komplette, laufend aktualisierte Projekt-Doku (Originalgerät mit mehr Sensoren) steht dauerhaft unter github.com/icepaule/IceWeatherstation.

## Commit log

2026-07-15 Initial documentation: BOM, wiring, enclosure, Tasmota config, setup guide
    Complete build documentation for the two-unit ESP32/Tasmota weather
    station project (BME280, DS18B20, SparkFun weather meter, AS3935
    lightning sensor, DFRobot SEN0232 calibrated dBA sensor). Includes
    MISOL compatibility analysis, Mermaid wiring/flow diagrams, a draft
    Berry firmware script, and a step-by-step setup/HA-integration guide.
2026-07-15 Add firmware bundle: official binary reference, config backlog, autoexec.be
    Verified against current Tasmota docs (v15.5.0) that the standard
    tasmota32.bin already includes AS3935, BME280, DS18B20, Counter, ADC
    range and Berry support - no custom PlatformIO build needed. Also
    corrects AS3935 (AS3935setgain) and ADC (AdcParam type 6) commands
    that had drifted from the actual current syntax, and renames the
    Berry script to autoexec.be so Tasmota auto-runs it on boot.
2026-07-18 Physische Pin-Tabelle fürs Prep-Board ergänzen (RJ11-Pinbelegung SEN-15901)
    RJ11-Pinbelegung gegen Original-OEM-Datenblatt (Shenzhen Fine Offset
    Electronics) verifiziert statt geraten, inkl. Anleitung zur
    Direktverdrahtung ohne RJ11-Stecker.
2026-07-18 Board-Pin-Position und Serial-Konsolen-GPIO-Werte ergänzen
    Physische Pin-Positionstabelle für den DevKitC-V4-Formfaktor (gegen
    Espressif-Referenz verifiziert) sowie verifizierte numerische
    GPIO-Funktionswerte für die Serial-Konsolen-Konfiguration als
    Alternative zur Web-UI (nützlich fürs Erstflashen vor WLAN-Verbindung).
2026-07-18 OLED-Display-Konfiguration ergänzen, SEN0232-V2.0-Klarstellung
    Tasmota-Konfig für Hailege SSD1306 0,96" I2C-OLED (teilt sich den
    bestehenden I2C-Bus, kein eigener GPIO nötig) sowie Hinweis, dass
    der als "V2.0" verkaufte Schallpegelsensor hard-/softwareseitig
    identisch zum bereits dokumentierten SEN0232 ist.
2026-07-18 Modulfunktion-Spalte in Pin-Tabellen ergänzen
    Klartext-Bezeichnung je Sensor (z.B. "Thermosensor", "Blitzsensor")
    zusätzlich zur Bauteil-/Pin-Bezeichnung, für schnellere Orientierung
    beim Breadboard-Aufbau.
2026-07-18 dBA-Kalibrierung korrigieren: AdcParam-Kanalnummer und Einheiten
    Live gegen echte Hardware verifiziert: AdcParam<N> zählt nach
    GPIO-Reihenfolge (Windfahne=Kanal1, dBA=Kanal2, nicht andersrum),
    und die Schwellwerte sind ein 0-4095-Pseudo-ADC-Wert statt
    Millivolt. Alte Doku (AdcParam1 mit mV-Werten) war für dieses
    Pin-Layout falsch.
2026-07-18 OLED-Einrichtung (uDisplay) und ADC-Input-Fallstrick dokumentieren
    - tasmota32.bin hat keinen Display-Treiber, OTA-Umstieg auf
    tasmota32-display.bin nötig (Sensor-Config bleibt erhalten)
    - Klassischer SSD1306-Treiber wurde entfernt, neues uDisplay-System
    (DisplayModel 17, virtueller "Option A3"-GPIO-Marker, Display.ini
    als Rule3-Datenspeicher) komplett dokumentiert inkl. Live-Daten-Rule
    - AdcParam-Fallstrick: GPIO_ADC_INPUT unterdrückt "A1" im JSON sobald
    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
2026-07-18 AS3935 CJMCU-3935 Pinbezeichnung klarstellen (MOSI statt SDA)
    Auf diesem Board gibt es keinen "SDA"-Aufdruck, der MOSI-Pin
    übernimmt die I2C-Datenleitung. A0/A1-Adresspins ergänzt.
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2026-07-18 Web-UI-Labels, Nachtruhe, Zeitzone, MQTT/HA-Anbindung und Stromversorgung
    - Custom-Build-Patch für sprechende Web-UI-Labels (Regenmesser/Anemometer/
    Windfahne/Schallpegel statt Counter1/2/Analog1/ADC1 Range) - Tasmota
    bietet dafür keine eingebaute Umbenennung (GitHub-Issue #6970)
    - Status-LED (LedLink-Rolle + LedState 7) für WLAN/MQTT-Aktivität
    - Nachtruhe 22:00-08:00 (Display+LED aus) inkl. Fix für NTP-Boot-Race
    - Timezone-99-Fix (TimeStd/TimeDst waren korrekt, Timezone-Flag nicht)
    - MQTT konfiguriert, eigene Werte (Wind/Regen) per json_append() in die
    SENSOR-JSON eingespeist -> automatisch als Home-Assistant-Entities
    discovered (Tasmota-Integration, nicht generische MQTT-Integ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
2026-07-19 Regen-24h-Persistenz-Bug fixen + Einheiten-Korrekturen
    - Größter Fund: 24h-Regen-Ringpuffer lebte nur im RAM, jeder Neustart
    löschte die komplette Historie statt nur der aktuellen Stunde.
    Fix: persist-Modul, dabei zwei weitere Fallstricke gefunden -
    "persist.foo = self.bar" mit Listen erzeugt keine gemeinsame
    Referenz (jetzt persist direkt als einzige Quelle der Wahrheit),
    und der NTP-Boot-Race betraf auch check_hour_rollover() (nicht nur
    die Nachtruhe) und löschte dabei den falschen Ringpuffer-Slot.
    Zusätzlich: Counter-Basiswerte nach Neustart ohne Delta-Berechnung
    initialisieren, sonst falscher Regen-/Wind-Ausschlag.
    - "Schallpegel (roh)" korrigiert zu "Schallpegel ...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
2026-07-19 Erweiterungssensoren zur BOM, AS3935-Kalibrierungs-Fallstrick, Fritzing-Gesamtplan
    - BOM: BH1750, VEML6070, PMS5003/SDS011, MQ135-Hinweise (2x vorhanden) ergaenzt
    - tasmota-config.md: AS3935 Tunecaps/Kalibrierung als Ursache fuer ausbleibende
    Blitzerkennung bei echtem Gewitter dokumentiert (live auf 10.10.12.50 gefixt)
    - wiring.md + docs/fritzing/IceWeatherstation.fzz: komplette Fritzing-Breadboard-
    Verdrahtung (ESP32 DevKitC V4 community-Part, BME280/DS18B20 echte Parts,
    Platzhalter-Footprints fuer AS3935/SEN0232/OLED)
    [IceWeatherstation.fzz]
2026-07-19 Fritzing-Wires exakt an SVG-Pin-Koordinaten ausrichten
    Wire-Endpunkte lagen bisher nur grob an Bauteil-Ecken statt an den echten
    Anschluss-Pins. Pin-Positionen jetzt aus den SVG-Transformationsketten jedes
    Bauteils berechnet (Rotation/Skalierung/mm-vs-Zoll korrekt aufgeloest) und
    gegen die bekannten 0,1"-Raster-Abstaende plausibilisiert.
    [IceWeatherstation.fzz]
2026-07-19 Fritzing-Verdrahtung kreuzungsfrei als Bus-Ketten neu geroutet
    Statt Stern-Verkabelung (jedes Bauteil direkt einzeln zum ESP32, siehe
    Nutzer-Screenshot mit Wire-Gewirr am BME280) laufen 3,3V/GND/SDA/SCL jetzt
    als Ketten durch alle Bauteile, die sie brauchen. Vier Sammel-Leitungen
    (3,3V/SDA/SCL/AS3935-INT) als eigene Lanes oberhalb, beide GND-Ketten
    unterhalb der Schaltung -- keine Linie kreuzt eine andere mehr, bis auf
    die pinout-bedingt unvermeidbare AS3935-INT-Leitung (GPIO25 liegt auf der
    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
    [IceWeatherstation.fzz]
2026-07-19 Schematic-Platzierung + Code-Tab (Tasmota-Backlog/Berry) ins Fritzing-Sketch, Windfahnen-Kreuzung gefixt
    Fritzing 1.0.1 lokal installiert und die Datei per Xvfb tatsaechlich in der
    echten App geoeffnet+screenshot-geprueft statt nur XML zu validieren. Dabei
    gefunden+gefixt: verbliebene Kreuzung Windfahne/Spannungsteiler/SEN0232
    (Widerstand jetzt in der Signalspalte statt versetzt). Schematic-Ansicht
    zeigt jetzt alle 13 Bauteile mit korrekten Schaltzeichen (Verkabelung dort
    mangels Cross-View-Ratsnest-Uebernahme noch manuell noetig, siehe wiring.md).
    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
    [IceWeatherstation.fzz]
2026-07-20 Regen-Vibrationsunterdrueckung: Solartracker-Bewegung per Cross-MQTT vom Regenkipper abziehen
    PV-Solartracker haengt im selben Schuppen und loest beim Verfahren des
    Aktuators falsche Kippen am Reed-Kontakt-Regenmesser aus. autoexec.be
    abonniert jetzt tele/solar/SENSOR (Motion) + tele/solar/LWT (Fail-Safe)
    und unterdrueckt Counter1-Deltas waehrend Bewegung + Nachlaufzeit, statt
    sie in Rain24h einzurechnen. Verifiziert am echten Geraet inkl. echtem
    Solartracker-Reboot/Bewegung waehrend des Tests.
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2026-07-23 BME280-Erkennung fixen: SevenSeg/Matrix teilt sich I2C-Adresse 0x76
    USE_DISPLAY aktiviert ungewollt auch USE_DISPLAY_MATRIX/USE_DISPLAY_SEVENSEG
    (my_user_config.h guardet die nicht wirklich). Deren Boot-Probe an Adresse
    0x76 kommt dem BME280 zuvor, der dieselbe Adresse nutzt - BME280 wurde nie
    erkannt. Beide Displaytreiber werden hier nicht gebraucht, also deaktiviert.
2026-07-23 BME280-Fix dokumentieren, RainHour-Entity ergaenzen, HA-Dashboard-Screenshot
    Zwei Fallstricke aus dem Live-Betrieb dokumentiert (SevenSeg/Matrix teilt
    sich I2C-Adresse 0x76 mit BME280; danach Wackelkontakt am Breakout, der
    zusaetzlich einen Restart nach der Reparatur brauchte, ein reiner I2CScan
    reicht nicht). autoexec.be json_append() um RainHour ergaenzt, damit die
    Regenmenge der laufenden Stunde auch als eigene HA-Entity existiert
    (analog Rain24h). Screenshot des fertigen HA-Dashboards mit allen neuen
    Werten (Feuchte, Regen/h, Schallpegel, Blitz-Distanz) angehaengt.
2026-07-23 DS18B20 statt BME280 als primaere Temperatur (Strahlungswaerme-Fix)
    BME280 sitzt am Prepboard direkt an der besonnten Gehaeusewand und zeigte
    zeitweise 6-8C zu warm (Strahlungswaerme, kein Messfehler) - ein fixer
    Kalibrierungs-Offset waere nachts/bei Bewoelkung falsch gewesen, also
    bewusst keiner gesetzt. DS18B20 (Messstift, nicht direkt besonnt) ist
    jetzt die angezeigte Lufttemperatur auf OLED und im HA-Dashboard, BME280
    bleibt fuer Druck/Feuchte und als klar markierter Diagnosewert.
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2026-08-20 AS3935: Race Condition im Boot-Self-Heal beheben
    Erster Live-Test des neuen Self-Heals zeigte Disturber weiterhin auf
    "Off" (5x ueber 40s stabil), obwohl "AS3935disturber 1" explizit
    gesetzt wurde - AS3935calibrate war zu diesem Zeitpunkt vermutlich
    noch nicht fertig und ihr interner "Disturber aus"-Nebeneffekt kam
    danach. Fix: Folgebefehle per Timer 1s entkoppelt statt synchron
    direkt hintereinander.
2026-08-20 AS3935: Fehldiagnose korrigieren, kein Race Condition im Self-Heal
    Quellcode-Pruefung (xsns_67_as3935.ino) zeigt: AS3935calibrate fasst
    das Disturber-Register gar nicht an. Der beobachtete "Disturber: Off"-
    Zustand kommt von AS3935autodisturber 1 selbst (60s-Autozyklus,
    gewollt) - betrifft nur Stoersignal-Filterung, echte Blitze laufen
    ueber einen separaten Codepfad und sind davon unabhaengig. Timer-
    Entkopplung im letzten Commit war unnoetig (alle AS3935-Kommandos
    laufen synchron), zurueckgebaut auf die einfache Version. Gleicher
    Fehlschluss steckte schon in der 19.07.2026-Doku, ebenfalls korrigiert.
2026-08-22 docs(as3935): Dashboard-Bug bei Event-Code-Auswertung dokumentieren
    Kiosk-Dashboard prüfte rohe IRQ-Bits (1/4/8) statt der vom Tasmota-
    Treiber übersetzten Event-Codes. Ein echter, lokalisierter Blitzschlag
    (Event=1) wurde dadurch fälschlich als "Rauschen" angezeigt, "Blitz!"
    (Event 8) kam nie vor. Live während eines echten Gewitters gefunden
    und per Quellcode (xsns_67_as3935.ino) verifiziert.
